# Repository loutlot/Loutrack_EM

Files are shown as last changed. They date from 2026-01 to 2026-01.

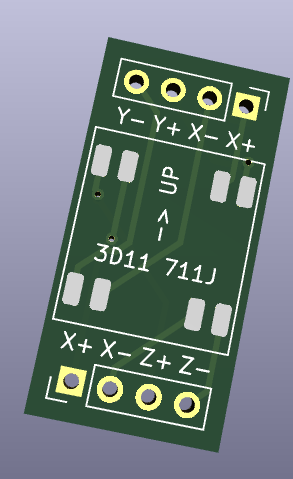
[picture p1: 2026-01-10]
kicad/3D11_test_Board/3D11_test_Board.png

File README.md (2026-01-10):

# Loutrack EM

**磁界ベースのドリフトレスVRトラッカー**

---

## TL;DR

IMUの積分ドリフト問題を解決するため、**磁界（EM）を使った絶対位置・姿勢トラッキング**を開発中。
VRChat等のフルボディトラッキング向け。現在M0（1軸PoC）フェーズ。

---

## 現在の進捗

| フェーズ | 内容 | 状態 |
|---|---|---|
| **M0** | 1軸ディスクリートPoC | 🔄 電源＆受信アンプ組み立て完了、ADC接続中 |
| M1 | 3軸TDM | ⬜ |
| M1.5 | 自作コイル＆ドライバ強化 | ⬜ |
| M2 | SMD基板化（バッテリー駆動対応） | 🔄 バッテリー駆動仕様策定完了 |
| M3 | 推定アルゴリズム | ⬜ |
| M4 | 製品化 | ⬜ |

---

## なぜEMトラッキング？

### 既存技術の問題

| 方式 | 問題点 |
|---|---|
| **IMU** | 積分ドリフトで数分〜数十分で位置がズレる |
| **光学式** | オクルージョン（遮蔽）に弱い、カメラ設置が必要 |
| **Lighthouse** | 高価、HMD依存、セットアップが複雑 |

### EMトラッキングの利点

- ✅ **ドリフトなし**: 磁界強度から直接位置を算出（積分不要）
- ✅ **遮蔽に強い**: 衣服・体を通過する
- ✅ **セットアップ簡単**: 送信アンテナ1つ置くだけ
- ✅ **低コスト化の余地**: IC数個で構成可能

### EMトラッキングの課題

- ⚠️ 金属環境での歪み（キャリブレーションで対応予定）
- ⚠️ 到達距離に限界（送信出力で調整可能）
- ⚠️ 複数トラッカー時の同期

---

## 動作原理

```
┌─────────────┐          磁界           ┌─────────────┐
│   Beacon    │  ～～～～～～～～～～→  │   Tracker   │
│  （送信）   │                         │  （受信）   │
│             │                         │             │
│ 20kHz交流   │                         │ コイルで    │
│ →コイル駆動 │                         │ 誘導電圧検出│
│ →磁界放射   │                         │ →I/Q処理   │
└─────────────┘                         │ →振幅A算出 │
                                        └─────────────┘
```

### 磁界の性質を利用

1. **磁界強度は距離の3乗に反比例** → 距離が分かる
2. **3軸送受信で方向も分かる** → 姿勢も推定可能
3. **位相も取れる** → 将来的に精度向上

### I/Q同期検波

受信信号を送信周波数と同期したsin/cosで積分し、ノイズを除去しながら振幅Aを算出。

```
A = √(I² + Q²)
```

---

## システム構成（M0）

```
┌──────────────────────────────────────────────────────────┐
│                    XIAO ESP32C3                          │
│  PWM生成（20kHz）              SPI ADC読取 → I/Q処理    │
└──────────┬───────────────────────────────┬───────────────┘
           │                               │
           ▼                               ▼
┌──────────────────┐            ┌──────────────────────────┐
│    DRV8835       │            │       MCP6022            │
│   (Hブリッジ)    │            │    (受信アンプ)          │
└────────┬─────────┘            └────────────┬─────────────┘
         │                                   │
         ▼                                   ▼
┌──────────────────┐            ┌──────────────────────────┐
│   3D11-722J      │   磁界     │       3D11-722J          │
│  (送信コイル)    │ ~~~~~~~~→  │     (受信コイル)         │
└──────────────────┘            └────────────┬─────────────┘
                                             │
                                             ▼
                                ┌──────────────────────────┐
                                │        MCP3008           │
                                │         (ADC)            │
                                └──────────────────────────┘
```

## システム構成（M2）

M2では受信機（Tracker）をバッテリー駆動化し、DEEP SLEEP機能で過放電を防止。

```
┌──────────────────────────────────────────────────────────┐
│                XIAO ESP32C3 (Tracker)                    │
│  バッテリー監視 → DEEP SLEEP      SPI ADC読取 → I/Q処理 │
└──────────┬───────────────────────────────┬───────────────┘
           │                               │
           ▼                               ▼
┌──────────────────┐            ┌──────────────────────────┐
│ Li-Po 3.7V       │            │       MCP6022            │
│ (バッテリー)     │            │    (受信アンプ)          │
└────────┬─────────┘            └────────────┬─────────────┘
         │                                   │
         ▼                                   ▼
┌──────────────────┐            ┌──────────────────────────┐
│ 電圧監視回路     │            │       3D11-722J          │
│ (200kΩ分圧)      │            │     (受信コイル)         │
└────────┬─────────┘            └────────────┬─────────────┘
         │                                   │
         ▼                                   ▼
┌──────────────────┐            ┌──────────────────────────┐
│ Wake-upボタン    │   磁界     │        MCP3008           │
│ (D1ピン)         │ ~~~~~~~~→  │         (ADC)            │
└──────────────────┘            └──────────────────────────┘
```

---

## 使用部品

| 部品 | 型番 | 役割 |
|---|---|---|
| MCU | XIAO ESP32C3 | PWM生成、ADC読取、I/Q処理 |
| 3軸コイル | 3D11-722J (7.2mH) | 送受信アンテナ |
| モータドライバ | DRV8835 | コイル駆動（Hブリッジ） |
| オペアンプ | MCP6022 | 受信信号増幅 |
| ADC | MCP3008 | 波形サンプリング |

---

## ロードマップ

### M0: 1軸PoC（現在）
- [x] 部品調達
- [x] GPIO割り当て
- [x] Vmid生成回路組み立て
- [x] 受信アンプ組み立て・動作確認
- [ ] ADC接続・動作確認
- [ ] 送信回路組み立て
- [ ] PWM生成ファームウェア
- [ ] I/Q処理ファームウェア
- [ ] 共振C最適化
- [ ] 距離・角度応答測定

### M1: 3軸TDM
- 3軸送受信でフル姿勢推定
- Time Division Multiplex（X→Y→Z切替）
- 軸間干渉対策

### M1.5: 自作コイル＆ドライバ強化
- 送信距離拡大のための自作コイル製作
- より高出力のドライバ選定・電源強化
- 3m以上のレンジを目指す

### M2: SMD基板化（バッテリー駆動対応）
- [x] バッテリー駆動仕様策定
- [x] 電圧監視回路設計
- [x] DEEP SLEEP/Wake-up実装
- [ ] 回路図設計（KiCad）
- [ ] 基板レイアウト
- [ ] 実装・動作確認

### M3: 推定アルゴリズム
- 磁界モデルに基づく位置・姿勢推定
- キャリブレーション手法

### M4: 製品化
- 無線化（BLE/ESP-NOW）
- 複数トラッカー同期
- VRChat/SteamVR連携

---

## 参考資料

### EMトラッキングの先行事例
- [Polhemus](https://polhemus.com/) - 医療・研究用EMトラッカー
- [NDI Aurora](https://www.ndigital.com/electromagnetic-tracking/) - 手術ナビゲーション

### 技術資料
- [documents/requirements/m0_poc/specification_v0.9.md](documents/requirements/m0_poc/specification_v0.9.md) - M0詳細仕様書
- [documents/requirements/m2_smd/specification.md](documents/requirements/m2_smd/specification.md) - M2バッテリー駆動仕様書
- [documents/schematics/m2_smd/tracker/power_schematic.md](documents/schematics/m2_smd/tracker/power_schematic.md) - M2電源回路図
- [documents/progress/experiment_log.md](documents/progress/m0_poc/experiment_log.md) - M0実験ログ
- [documents/datasheets/](documents/datasheets/) - 部品データシート

---

## フォルダ構成

```
Loutrack_EM/
├── README.md              # このファイル
├── documents/             # ドキュメント
│   ├── requirements/      # 仕様書（フェーズ別）
│   ├── progress/          # 進捗管理
│   ├── bom/               # 部品リスト
│   ├── schematics/        # 回路図
│   ├── assembly/          # 組み立てガイド
│   └── datasheets/        # データシート
├── firmware/              # ファームウェア
│   ├── lib/               # 共通ライブラリ
│   │   ├── battery_monitor.h/cpp    # バッテリー電圧監視
│   │   └── power_manager.h/cpp      # 電源管理（DEEP SLEEP）
│   └── m2_tracker/         # M2受信機ファームウェア
└── kicad/                 # KiCad設計ファイル
```

---

## ライセンス

TBD

---

## 連絡先

TBD

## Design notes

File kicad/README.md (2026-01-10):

# KiCad 設計ファイル

このフォルダには、Loutrack EMプロジェクトで使用するKiCad設計ファイルが保存されています。

## 概要

3D11-722Jコイルをブレッドボード互換のピンヘッダーに変換するためのテストボードをKiCadで設計しています。

## フォルダ構成

```
kicad/
├── README.md                              # このファイル
├── 3D11_test_Board/                       # 単体テストボード
│   ├── 3D11_test_Board.kicad_sch          # 回路図
│   ├── 3D11_test_Board.kicad_pcb          # PCB設計
│   ├── 3D11_test_Board.kicad_pro          # プロジェクト設定
│   ├── 3D11_test_Board.kicad_prl          # プロジェクトレイアウト
│   ├── 3D11_test_Board.png                # 3Dレンダリング
│   ├── garber.zip                         # ガーバーファイル
│   └── fp-info-cache                      # フットプリントキャッシュ
└── 3D11_production/                       # 量産用パネル基板
    ├── 3d11_testboard_batch.kicad_pcb     # PCB設計（パネル）
    ├── 3d11_testboard_batch.kicad_pro     # プロジェクト設定
    ├── 3d11_testboard_batch.png           # 3Dレンダリング
    └── garber.zip                         # ガーバーファイル
```

## テストボードの目的

3D11-722JはSMD部品のため、ブレッドボード（2.54mmピッチ）で直接使用できません。このテストボードは以下の機能を果たします：

- **SMD → DIP変換**: 3D11-722Jを2.54mmピッチのピンヘッダーに接続
- **ブレッドボード互換**: 標準的なブレッドボードに挿入可能
- **信号分離**: 各軸（X, Y, Z）のコイル端子を独立してアクセス可能

## ピン配置

### 基板上面（Y軸 + X軸）

```
        ┌─────────────────────────────────────┐
        │          3D11-722J                  │
        │          Test Board                 │
        │                                     │
        │  Y- [●]  Y+ [●]  X- [●]  X+ [●]    │  ← 上部
        │                                     │
        │          [コイル実装位置]           │
        │                                     │
        │  X+ [●]  X- [●]  Z+ [●]  Z- [●]    │  ← 下部
        │                                     │
        └─────────────────────────────────────┘
```

- **上部**: Y軸, X軸（Y-, Y+, X-, X+）
- **下部**: X軸, Z軸（X+, X-, Z+, Z-）
- **注意**: X軸は上部と下部の両方に存在（接続確認用）

## バージョン説明

### 3D11_test_Board（単体版）

- **用途**: プロトタイプ開発、少量製作
- **基板サイズ**: 単体基板
- **特徴**:
  - 回路図を含む完全なKiCadプロジェクト
  - テスト用の設計検証が可能

### 3D11_production（パネル版）

- **用途**: 量産、10枚同時発注
- **基板サイズ**: 10枚パネル配置
- **特徴**:
  - パネル化によるコスト削減
  - 量産向けに最適化

## 設計仕様

### 電気的特性

| 項目 | 仕様 |
|---|---|
| 入力電圧 | コイルからの誘導電圧（AC） |
| 周波数範囲 | DC〜1MHz（3D11-722JのSRFまで） |
| インピーダンス | コイルインピーダンスに準ずる |
| 絶縁耐圧 | 基板絶縁強度による |

### 機械的特性

| 項目 | 仕様 |
|---|---|
| 基板サイズ | 約30mm × 20mm（単体） |
| 層構成 | 2層基板 |
| ピンヘッダー | 2.54mmピッチ、1×4ヘッダー × 2 |
| コイル固定 | SMDパッド + はんだ固定 |

## 製造手順

### 部品調達

| 部品 | 型番 | 数量 | 備考 |
|---|---|---|---|
| 3D11-722J | - | 1個/基板 | [AliExpress](https://ja.aliexpress.com/item/1005004723068527.html) |
| ピンヘッダー | 1×4, 2.54mm | 2個/基板 | ブレッドボード用 |

### 組み立て手順

1. **基板準備**
   - KiCadでPCBを発注
   - ガーバーファイル（garber.zip）を使用

2. **部品実装**
   - 3D11-722Jを基板中央に配置
   - SMDはんだ付けを実施
   - ピンヘッダーを上下に挿入

3. **動作確認**
   - テスターで各ピン間の導通を確認
   - ショートがないことを確認

## 使用方法

### ブレッドボードへの接続

1. ピンヘッダーをブレッドボードに挿入
2. コイルの各軸端子を回路に接続
3. 電源投入前に接続を確認

### 信号接続例（M0 PoC）

```
DRV8835出力 ──→ 3D11_test_Board X+ ──→ コイルX軸
コイルX軸 ──→ 3D11_test_Board X- ──→ MCP6022入力
```

## 設計ファイルの編集

### KiCadプロジェクトを開く

1. KiCadを起動
2. `File` → `Open Project` → `.kicad_pro`ファイルを選択
3. 回路図（.kicad_sch）またはPCB（.kicad_pcb）を編集

### 回路図の編集

- ピン配置の変更
- 追加回路の設計
- フットプリントの更新

### PCBレイアウトの編集

- 配線パターンの最適化
- サイズ変更
- 層構成の変更

## 注意事項

⚠️ **設計時の注意点:**

1. **絶縁距離**: 高周波信号のため、配線間隔を十分に確保
2. **GND接続**: ノイズ対策のため、GNDプレーンを確保
3. **熱対策**: 発熱部品がある場合は放熱パターンを考慮

⚠️ **使用時の注意点:**

1. **静電気**: ESD対策のため、取り扱いに注意
2. **電源投入**: 接続ミスがないことを確認してから電源投入
3. **周波数範囲**: 3D11-722JのSRFを超えないよう注意

## 関連ドキュメント

- [3D11-722Jデータシート](../../../../documents/datasheets/3d11_coil/)
- [M0組み立てガイド](../../../../documents/assembly/m0_poc/README.md)
- [BOM](../../../../documents/bom/m0_poc/bom.md)

## 変更履歴

| 日付 | 内容 | 変更者 |
|---|---|---|
| 2026-01-11 | 初版作成 | - |

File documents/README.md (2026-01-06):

# Loutrack EM - ドキュメント

## EMトラッキング VRChat用デバイス開発プロジェクト

磁界（EM）ベースのドリフトレストラッキングデバイスのPoC開発ドキュメント

---

## 現在のフェーズ: M0（1軸ディスクリートPoC）

---

## フォルダ構成

```
documents/
├── README.md                      # このファイル
│
├── requirements/                  # 仕様・要件
│   ├── m0_poc/                   # M0: 1軸PoC
│   │   ├── specification_v0.9.md
│   │   └── acceptance_criteria.md
│   ├── m1_3axis/                 # M1: 3軸TDM
│   └── common/                   # 共通仕様
│
├── progress/                      # 進捗管理
│   ├── milestone_tracking.md     # 全体マイルストーン
│   ├── m0_poc/                   # M0実験ログ
│   │   └── experiment_log.md
│   └── m1_3axis/                 # M1実験ログ
│
├── bom/                          # 部品リスト
│   ├── m0_poc/bom.md            # M0用
│   └── m1_3axis/bom.md          # M1用
│
├── schematics/                   # 回路図
│   ├── m0_poc/                  # M0回路図
│   │   ├── beacon/
│   │   ├── tracker/
│   │   └── wiring_table.md
│   └── m1_3axis/                # M1回路図
│
├── assembly/                     # 組み立て説明書
│   ├── m0_poc/                  # M0組み立て
│   │   ├── 01_power_vmid.md
│   │   ├── 02_rx_amplifier.md
│   │   ├── 03_adc.md
│   │   ├── 04_tx_driver.md
│   │   ├── 05_integration.md
│   │   └── troubleshooting.md
│   └── m1_3axis/                # M1組み立て
│
└── datasheets/                   # データシート（共通）
    ├── drv8835/
    ├── 3d11_coil/
    ├── mcp6022/
    ├── mcp3008/
    ├── bat43/
    └── esp32c3/
```

---

## フェーズ一覧

| フェーズ | フォルダ | 内容 | ステータス |
|---|---|---|---|
| **M0** | `m0_poc/` | 1軸ディスクリートPoC | 🔄 進行中 |
| **M1** | `m1_3axis/` | 3軸TDM（ディスクリート） | ⬜ 未着手 |
| **M1.5** | `m1.5_coil_power/` | 自作コイル＆ドライバ強化 | ⬜ 未着手 |
| **M2** | `m2_smd/` | 3軸SMD試作基板 | ⬜ 未着手 |
| **M3** | `m3_algorithm/` | 推定アルゴリズム拡張 | ⬜ 未着手 |
| **M4** | `m4_product/` | 製品化要素 | ⬜ 未着手 |

---

## クイックアクセス（M0）

| ドキュメント | パス |
|---|---|
| 仕様書 | [requirements/m0_poc/specification_v0.9.md](requirements/m0_poc/specification_v0.9.md) |
| 達成基準 | [requirements/m0_poc/acceptance_criteria.md](requirements/m0_poc/acceptance_criteria.md) |
| 部品リスト | [bom/m0_poc/bom.md](bom/m0_poc/bom.md) |
| 配線表 | [schematics/m0_poc/wiring_table.md](schematics/m0_poc/wiring_table.md) |
| 組み立てガイド | [assembly/m0_poc/README.md](assembly/m0_poc/README.md) |
| 実験ログ | [progress/m0_poc/experiment_log.md](progress/m0_poc/experiment_log.md) |
| 全体進捗 | [progress/milestone_tracking.md](progress/milestone_tracking.md) |

---

## 使用機材

| 部品 | 型番 | 入手先 |
|---|---|---|
| MCU | XIAO ESP32C3 | [AliExpress](https://ja.aliexpress.com/item/1005006114576182.html) |
| 3軸コイル | 3D11-722J (L≈7.2mH) | [AliExpress](https://ja.aliexpress.com/item/1005004723068527.html) |
| モータドライバ | DRV8835モジュール | 秋月電子 (109848) |
| オペアンプ | MCP6022-I/P | 秋月電子 (116187) |
| ADC | MCP3008-I/P | 秋月電子 (109485) |

---

## XIAO ESP32C3 GPIO割り当て

| 機能 | ピン | GPIO |
|---|---|---|
| PWM_X | D0 | GPIO2 |
| PWM_X_INV | D1 | GPIO3 |
| SPI_SCK | D8 | GPIO8 |
| SPI_MISO | D9 | GPIO9 |
| SPI_MOSI | D10 | GPIO10 |
| SPI_CS | D7 | GPIO20 |

---

## 更新履歴

| 日付 | 内容 |
|---|---|
| 2026-01-07 | 初版作成 |
| 2026-01-07 | XIAO ESP32C3, 3D11-722J情報追加 |
| 2026-01-07 | フェーズ別フォルダ構成に再編 |

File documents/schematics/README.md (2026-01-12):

# 回路図

## フォルダ構成

```
schematics/
├── README.md          # このファイル
├── m0_poc/           # M0: 1軸ディスクリートPoC
│   ├── beacon/       # 送信回路
│   ├── tracker/      # 受信回路
│   └── wiring_table.md
├── m1_3axis/         # M1: 3軸TDM + LIS3DH
├── m1.5_coil_power/  # M1.5: 自作コイル＆ドライバ強化
└── m2_smd/           # M2: SMD基板化
    └── tracker/
        ├── power_schematic.md   # 電源回路
        └── lis3dh_schematic.md  # LIS3DH回路
```

## 各フェーズの回路図

| フェーズ | 送信回路 | 受信回路 | 配線表 |
|---|---|---|---|
| M0 | [beacon/](m0_poc/beacon/) | [tracker/](m0_poc/tracker/) | [wiring_table.md](m0_poc/wiring_table.md) |
| M1 | TBD | TBD | TBD |
| M2 | TBD | [tracker/](m2_smd/tracker/) | - |

## M2 Tracker回路図

| 回路 | ファイル | 概要 |
|---|---|---|
| 電源回路 | [power_schematic.md](m2_smd/tracker/power_schematic.md) | バッテリー監視、Wake-up回路 |
| LIS3DH回路 | [lis3dh_schematic.md](m2_smd/tracker/lis3dh_schematic.md) | 3軸加速度センサー（Hemispheric ambiguity解決用） |

## 回路図作成ツール（推奨）

- **KiCad** - オープンソース、無料
- **Fritzing** - ブレッドボード図に最適
- **draw.io** - 簡易ブロック図向け

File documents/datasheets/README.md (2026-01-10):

# データシート

## 概要

本プロジェクトで使用する部品のデータシートを保存するフォルダです。

---

## フォルダ構成

```
datasheets/
├── README.md                              # このファイル
├── drv8835/                               # モータドライバ
│   ├── AE-DRV8835-S_akizuki.pdf          ✅ DL済み
│   └── DRV8835_TI.pdf                    ✅ DL済み
├── 3d11_coil/                             # 3軸コイル
│   └── 2016122392158 (1).pdf             ✅ DL済み
├── mcp6022/                               # オペアンプ
│   └── Makin_Signed_henyathegenius-Duet_Night_Abyss_OBT_Campaign.pdf ✅ DL済み
├── mcp3008/                               # ADC
│   └── MCP3008_Microchip.pdf             ✅ DL済み
├── bat43/                                 # ショットキーダイオード
│   └── (要手動DL)
└── esp32c3/                               # MCU
    ├── 20.png                            ✅ DL済み
    └── pin_map-2.png                     ✅ DL済み
```

---

## ダウンロード済み ✅

| フォルダ | ファイル | サイズ | 内容 |
|---|---|---|---|
| drv8835/ | AE-DRV8835-S_akizuki.pdf | 1.0MB | 秋月モジュール説明書 |
| drv8835/ | DRV8835_TI.pdf | 871KB | TI公式データシート |
| 3d11_coil/ | 2016122392158 (1).pdf | 639KB | 3軸コイルシリーズ（3D11） |
| mcp3008/ | MCP3008_Microchip.pdf | 764KB | ADC公式データシート |
| mcp6022/ | Makin_Signed_henyathegenius-Duet_Night_Abyss_OBT_Campaign.pdf | 402KB | オペアンプデータシート |
| esp32c3/ | 20.png | 98KB | ESP32-C3ピン配置図 |
| esp32c3/ | pin_map-2.png | 154KB | ESP32-C3ピンマップ |

---

## 要手動ダウンロード ⚠️

以下のファイルはまだダウンロードできていません。
ブラウザでダウンロードして該当フォルダに保存してください。

### BAT43（ショットキーダイオード）

**保存先:** `bat43/BAT43_ST.pdf`

**ダウンロードリンク:**
- [ST公式](https://www.st.com/en/diodes-and-rectifiers/bat43.html) → "Resources" → "Datasheet"

---

## 主要スペック抜粋

### DRV8835モジュール (秋月 AE-DRV8835-S)

| 項目 | 値 |
|---|-----|
| モータ電源電圧 (VM) | 0〜11V |
| ロジック電源電圧 (VCC) | 2〜7V |
| Hブリッジ出力電流 | 0〜1.5A（並列で3A） |
| 外部入力PWM周波数 | 0〜250kHz |
| オン抵抗 (HS+LS) | 305mΩ |

**ピン配置（反時計回り）:**

| ピン | 名称 | 機能 |
|---|---|---|
| 1 | VM | モータ電源 |
| 2 | AOUT1 | A出力1 |
| 3 | AOUT2 | A出力2 |
| 4 | BOUT1 | B出力1 |
| 5 | BOUT2 | B出力2 |
| 6 | GND | グランド |
| 7 | BIN2 | B入力2/BENBL |
| 8 | BIN1 | B入力1/BPHASE |
| 9 | AIN2 | A入力2/AENBL |
| 10 | AIN1 | A入力1/APHASE |
| 11 | MODE | モード設定 |
| 12 | VCC | ロジック電源 |

**IN/INモード (MODE = GND):**

| xIN1 | xIN2 | xOUT1 | xOUT2 | 動作 |
|---|---|---|---|---|
| 0 | 0 | HiZ | HiZ | 空転 |
| 0 | 1 | L | H | 逆転 |
| 1 | 0 | H | L | 正転 |
| 1 | 1 | L | L | ブレーキ |

### 3D11-722J (SHINHOM)

| 項目 | 値 |
|---|-----|
| サイズ | 11.8 × 11.8 × 2.9 mm |
| インダクタンス (Lx,y,z) | 7.20 mH |
| Q値 | 30 |
| 自己共振周波数 (SRFx,y) | 330 kHz (typ) |
| 自己共振周波数 (SRFz) | 700 kHz (min) |
| DC抵抗 (RDCx,y) | 150Ω max |
| DC抵抗 (RDCz) | 210Ω max |
| 動作温度 | -40°C 〜 +85°C |

### MCP3008 (Microchip)

| 項目 | 値 |
|---|-----|
| 分解能 | 10bit |
| チャンネル数 | 8 |
| サンプルレート | 200ksps @ 5V, 75ksps @ 2.7V |
| 電源電圧 | 2.7〜5.5V |
| インターフェース | SPI |

### ESP32-C3 (Espressif)

| 項目 | 値 |
|---|-----|
| CPU | 32-bit RISC-V RV32IMC |
| クロック | 最大 160MHz |
| SRAM | 400KB |
| Flash | 外部サポート（最大16MB） |
| GPIO | 22個（うちADC1: 6個） |
| Wi-Fi | 802.11 b/g/n |
| Bluetooth | 5.0 (BLE) |
| 消費電流（アクティブ） | 約20mA |
| 消費電流（Deep Sleep） | 約5µA |
| 電源電圧 | 3.0〜3.6V |
| 動作温度 | -40°C 〜 +85°C |

---

## 外部リンク

### メーカーサイト

| 部品 | メーカー | 製品ページ |
|---|---|---|
| DRV8835 | Texas Instruments | [TI](https://www.ti.com/product/DRV8835) |
| AE-DRV8835-S | 秋月電子 | [秋月](https://akizukidenshi.com/catalog/g/g109848/) |
| 3D11-722J | SHINHOM | [SHINHOM](https://www.shinhom.com/) |
| MCP6022 | Microchip | [Microchip](https://www.microchip.com/en-us/product/MCP6022) |
| MCP3008 | Microchip | [Microchip](https://www.microchip.com/en-us/product/MCP3008) |
| BAT43 | STMicroelectronics | [ST](https://www.st.com/en/diodes-and-rectifiers/bat43.html) |
| ESP32-C3 | Espressif | [Espressif](https://www.espressif.com/en/products/socs/esp32-c3) |
| XIAO ESP32C3 | Seeed Studio | [Wiki](https://wiki.seeedstudio.com/XIAO_ESP32C3_Getting_Started/) |

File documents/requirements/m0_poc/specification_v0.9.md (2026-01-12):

# EMトラッキング PoC 仕様書

## ディスクリート→3軸TDM→SMD基板化ロードマップ

**Version:** 0.9  
**作成日:** 2026-01-07  
**対象:** 磁界（EM）ベースのドリフトレス計測 PoC（1軸→3軸TDMへ拡張可能な構造）

---

## 1. 目的とゴール

### 1.1 目的

- EM（磁界）だけで「積分ドリフトなし」の計測が成立するかを検証する
- 送信（Beacon）→受信（Tracker）→I/Q（同期検波） の最小パイプラインをPoCで成立させる
- 将来仕様（3軸TDM＋I/Q＋受信アンプ＋SMD基板）へ、配線・ソフト・データ構造を流用可能な形で実装する

### 1.2 PoCの達成条件（Acceptance Criteria）

PoC（1軸）で以下を満たすこと：

| # | 条件 |
|---|---|
| 1 | 送信ON時、受信信号からI/Qで **安定した振幅A** が算出できる |
| 2 | 送受コイルの距離・角度を変えると、Aが再現性のある単調変化を示す |
| 3 | 送信OFF時は、Aが十分小さく（ノイズフロア）、ON/OFFが明確に判別できる |
| 4 | 1フレーム（例: 16.7ms）内に I/Q 算出が完了し、60Hz相当の更新が可能 |

---

## 2. スコープ

### 2.1 PoC段階のスコープ

- **送信:** 20kHz帯の矩形波をHブリッジでコイル駆動し、L＋共振Cで正弦寄りの磁界を生成
- **受信:** コイル → MCP6022増幅（Vmid基準） → MCP3008 ADC → ESP32S3でI/Q演算
- **段階:**
  1. 1軸送受で成立
  2. 次に **3軸TDM（X→Y→Z時間切替）** へ拡張（同一構造の増殖）

### 2.2 非スコープ（PoCで未実装でもOK）

- VRワールド座標への整列（HMDアンカーによる剛体変換）
- 多トラッカー運用時の無線最適化（帯域、混信、低遅延化）
- 金属環境補正の高度化（環境モデル・キャリブレーション高度化）

---

## 3. 用語と前提

| 用語 | 説明 |
|---|---|
| **Beacon（送信）** | コイルへ交番電流を流し、磁界を作る側 |
| **Tracker（受信）** | コイルで誘導電圧を受け、I/Q処理する側 |
| **Vmid** | 単電源アナログ処理用の仮想GND（3.3V系では1.65V） |
| **I/Q（同期検波）** | 受信波形v(t)をcos/sin参照波で積分し、振幅と位相を得る手法 |
| **TDM** | Time Division Multiplex: X/Y/Z軸送信を時間枠で切り替え識別する方式 |

---

## 4. システム全体アーキテクチャ

### 4.1 ブロック図（論理）

```
┌─────────────────────────────────────────────────────────────────┐
│                    Beacon（送信）                                │
├─────────────────────────────────────────────────────────────────┤
│  ESP32S3                                                        │
│  ├─ 20kHzキャリア生成（PWM/LEDC等）                              │
│  └─ TDMスロット制御（将来3軸）                                   │
│           ↓                                                     │
│  DRV8835（Hブリッジ）                                            │
│  └─ コイルへ±電圧印加（交番電流生成）                            │
│           ↓                                                     │
│  コイル（PoC）＋ 共振C                                           │
│  └─ 高調波を抑えて「正弦寄りの電流波形」にする                   │
└─────────────────────────────────────────────────────────────────┘
           ↓ 磁界
┌─────────────────────────────────────────────────────────────────┐
│                    Tracker（受信）                               │
├─────────────────────────────────────────────────────────────────┤
│  コイル（PoC）                                                   │
│  └─ 20kHz近傍の誘導電圧を発生                                    │
│           ↓                                                     │
│  MCP6022（オペアンプ）                                           │
│  └─ Vmid基準で増幅（単電源で交流を扱う）                         │
│           ↓                                                     │
│  MCP3008（ADC 8ch）                                              │
│  └─ 生波形をサンプルしESP32へSPI転送                             │
│           ↓                                                     │
│  ESP32S3                                                         │
│  └─ I/Q（同期検波）→ A/φ算出                                    │
│     （将来）軸ごとの観測ベクトルから姿勢/位置推定へ拡張          │
└─────────────────────────────────────────────────────────────────┘
```

---

## 5. PoC仕様（ディスクリート実装）

### 5.1 電気仕様（PoCターゲット）

| 項目 | 値 |
|---|-----|
| 送信周波数 | 20kHz（±数%は許容、I/Q参照で追従） |
| 更新レート | 60Hz相当以上（内部はスロット制御でI/Q積分） |
| 受信ADC目標サンプルレート | ≥ 80ksps（20kHzに対して4サンプル/周期以上） |
| アナログ電源 | 3.3V単一（Vmid=1.65V） |
| 送信電源 | USB 5V想定（PoC） |

---

## 6. 回路仕様（PoC：1軸）

### 6.1 Beacon（送信）回路仕様

#### 6.1.1 コイル駆動

- DRV8835の1chで1軸コイルを駆動
- **駆動方式（PoC推奨順）:**
  1. AIN1 = PWM / AIN2 = 反転PWM（±駆動で磁界強度が取りやすい）
  2. AIN1 = PWM / AIN2 = Low固定（簡単だが磁界が弱くなる場合あり）

#### 6.1.2 共振C（"矩形波を丸める"）

- コイル両端にCを並列接続し、L-Cで共振点を20kHz近傍へ寄せる
- PoCでは理論一致より **受信振幅が最大となるCを実測で探索する**
- **手持ちCセットの使い方:**
  - 8200pF
  - 8200+560=8760pF
  - 8200+1500=9700pF
  - 6800pF、6800+1500…
  - の順で試し、受信I/Q振幅が最大になる点を採用

#### 6.1.3 電源デカップリング

- DRV8835近傍に:
  - 0.1µF（5V-GND）
  - 電解100µF（5V-GND）
- 送信系GNDは受信系GNDと一点接続（ノイズ回り込み防止）

### 6.2 Tracker（受信）回路仕様

#### 6.2.1 Vmid生成（仮想GND）

- 10k/10k分圧で1.65V生成（Vmid_raw）
- Vmid_rawを0.1µFで平滑、可能なら電解も追加
- MCP6022の1chを電圧フォロワとしてVmidをバッファ（推奨）
- 以後すべてのアナログ基準はVmid

#### 6.2.2 受信アンプ（1軸・非反転、Vmid基準）

- 受信コイル片端をVmidへ固定し、もう一端を信号入力とする（単端化）
- 入力はVmidにバイアスされるよう構成（ACカップリング or 直結＋抵抗で調整）
- **非反転アンプ:**
  - Gain = 1 + Rf/Rg = 11（Rf=10k, Rg=1k、Rg下端はVmid）
  - 発振時の対策: 47pFをRfに並列（高域ゲインを落とす）
- **目標:** ADCレンジ（0–3.3V）に収まること
  - 飽和する場合はゲインを下げる（または入力を下げる）
  - 弱い場合は2段増幅（将来3軸化時はchが逼迫するのでPoCのみ推奨）

#### 6.2.3 入力保護（BAT43）

- ADC入力を3.3V/GNDへクランプするショットキーを実装（保険）
- 実際には誘導電圧は小さい想定だが、実験時の誤配線対策

#### 6.2.4 ADC（MCP3008）

- VDD=3.3V、VREF=3.3V
- **デカップリング:**
  - VDD-GNDに0.1µF
  - VREF-AGNDに0.1µF
- CH0に受信アンプ出力を入力（PoC）

---

## 7. ファームウェア仕様（PoC：1軸→3軸へ流用）

### 7.1 送信（Beacon側）

- 20kHz PWM生成
- 将来のTDMに備え、スロット制御ステートマシンを最初から実装
- PoCはスロットXのみ有効で動作
- スロット切替は将来X→Y→Zへ拡張

### 7.2 受信（Tracker側）

- MCP3008から波形サンプルを取得
- **I/Q処理:**
  - 参照波cos/sinはNCOまたはテーブル
  - 積分窓長はパラメータ化（0.5ms〜5ms程度で探索）
- **出力:**
  - 振幅 A = sqrt(I²+Q²)
  - 位相 φ = atan2(Q, I)
- PoCではAを主要評価値とする（位相は観測の健全性チェック用途）

### 7.3 TDM（3軸化時）

- フレームを3スロットに分割し、送信軸を切り替える
- 各スロットで独立にI/Q積分し、(Ax, Ay, Az)を得る
- スロット間の過渡（コイルの立上り/共振の安定）を見込んだ "待ち時間（settling）"をパラメータ化（例: 0.2〜1.0ms）

---

## 8. 検証計画（PoCの進め方）

### 8.1 立ち上げ手順（最短）

| Step | 内容 | 確認項目 |
|---|---|---|
| 1 | 受信系単体 | ADCがVmid付近を中心に安定していること |
| 2 | 送信系単体 | DRV8835が過熱しない、電源が落ちない |
| 3 | 送受近接（数cm） | Aが明確に上がること、距離を離すと下がること |
| 4 | 共振C探索 | Cを変え、Aが最大の点を採用 |
| 5 | 距離・角度スイープ | Aの再現性（同じ配置に戻すと同程度のA） |

### 8.2 成功判定に必要なログ

- サンプルレート、積分窓長、A（平均/分散）、送信スロット状態
- 送信PWM設定値、電源電圧（可能なら）

---

## 9. リスクと対策（PoC段階）

| リスク | 対策 |
|---|---|
| ノイズ（送信スイッチングの回り込み） | 送受を物理分離、GND一点接続、ADC/OPAMP近傍デカップリング |
| 信号が弱い | 共振C最適化、コイルの向き・距離見直し、積分窓長増、（PoCのみ）2段増幅 |
| DRV8835の送信出力不足（距離を稼げない） | PoCの目的は"パイプライン成立"なので、まず近距離で成立を優先。将来は送信ドライバ/電源の増強をロードマップに含める |

---

## 10. 3軸TDMへの拡張仕様（次フェーズ）

### 10.1 ハード拡張

- **送信:**
  - DRV8835 2枚で3軸駆動（合計4chのうち3ch使用）
  - コイルは3軸（3Dコイル or 立方体巻線）を用意
- **受信:**
  - MCP6022を「Vmidバッファ1ch＋増幅3ch」で使用
  - MCP3008 CH0-CH2へ各軸アンプ出力を入力
- **⭐ LIS3DH（3軸加速度センサー）**:
  - Hemispheric ambiguity解決用（詳細は10.3参照）
  - I2C接続（D4=SDA, D5=SCL）
  - ブレークアウトボード推奨（秋月/Adafruit）

### 10.2 ソフト拡張

- スロット制御: X→Y→Z
- 各スロットでI/Q積分して (Ax, Ay, Az) を算出
- PoCの次の評価:
  - 軸間干渉（他軸送信時の漏れ）
  - スロット切替時の過渡（settling time）

### 10.3 Hemispheric Ambiguity解決

#### 10.3.1 問題

磁界測定では、+X+Y+Zの位置と-X-Y-Zの位置が同じ測定値を示す「Hemispheric ambiguity」が発生する。

```
     Beacon (送信)
         │
         ▼ 磁界
    ┌─────────┐
    │  +位置  │  ← 測定値 A
    └─────────┘
         │
    ─────┼───── 中心面
         │
    ┌─────────┐
    │  -位置  │  ← 測定値 A（同じ値）
    └─────────┘
```

#### 10.3.2 解決方法（IMU併用）

**Kirbの講義**（`documents/outside_sources/Electromagnetic 6-DOF Tracking for VR Applications/reformatted_kirb_lecture.md`）を参考に、**IMU（加速度センサー）で重力方向を検出**して上下を識別する。

| 方法 | メリット | デメリット | 採用 |
|---|---|---|---|
| 位相検出 | IMU不要 | 位相同期が必要、実装複雑 | ❌ |
| 複数送信コイル | 追加コイルで検証 | コスト・配線増 | ❌ |
| **IMU併用** | シンプル、実証済み | センサー追加 | ⭐ 採用 |

#### 10.3.3 LIS3DHによる実装

- **センサー**: LIS3DH（3軸加速度センサー）
- **必要な機能**: 重力方向検出のみ → 低コストセンサーで十分
- **ジャイロ**: 不要（角速度は不要）
- **データシート**: `documents/requirements/lis3dh/lis3dh.pdf`

**接続（I2C）**:

| LIS3DH | XIAO ESP32C3 | GPIO |
|---|---|---|
| SDA | D4 | GPIO6 |
| SCL | D5 | GPIO7 |
| VDD | 3.3V | - |
| GND | GND | - |

**重力方向検出アルゴリズム**:

```cpp
// Beaconの「下」方向を+Zと仮定
bool isPositiveHemisphere() {
  float gx, gy, gz;
  getGravityDirection(gx, gy, gz);
  // 重力が+Z方向を向いていれば正半球
  return gz > 0;
}
```

#### 10.3.4 初期キャリブレーション手順

1. **Beaconを設置し、向きを固定**（「下」方向を定義）
2. **Trackerを起動**、LIS3DHで重力方向を検出
3. **座標系を整列**: BeaconとTrackerの座標系を合わせる

#### 10.3.5 I/Qロックインとの関係

⚠️ **重要**: I/Qロックイン（I/Q同期検波）は**依然として必要**

| 目的 | I/Qロックイン | IMU (LIS3DH) |
|---|---|---|
| 信号検出・ノイズ除去 | ✅ 必須 | ❌ 不可 |
| 振幅A算出 | ✅ 必須 | ❌ 不可 |
| Hemispheric ambiguity | ❌ 使わない | ✅ これで解決 |

- 位相φも算出するが、**Hemispheric ambiguity解決には使わない**（IMUで解決）
- 位相同期の複雑な実装は不要

---

## 11. SMD基板化（量産に向けた設計方針）

### 11.1 目的

- 配線の寄生成分とノイズ混入を減らし、再現性を上げる
- 3軸＋受信＋ADCの構成を一体化し、調整点を減らす

### 11.2 基板分割（推奨）

- **Beacon基板（送信）とTracker基板（受信）** は分ける
- 送信のスイッチングノイズを受信から隔離
- 受信基板は「アナログ（コイル/AMP）」「デジタル（ADC/MCU/無線）」をレイアウトで分離

### 11.3 回路のSMD化での重要ポイント

- Vmidは必ずバッファ（低インピーダンス）で全体へ配布
- ADCのVREF周りは最優先で静かに（スターGND、短配線、デカップリング密）
- コイル入力は保護・ESD・クランプを入れつつ、過剰な容量を増やさない
- 送信側Hブリッジは熱と電源バルク配置を最優先

### 11.4 将来の部品置換（PoC→製品）

| PoC部品 | 置換候補 |
|---|---|
| MCP3008（SPI ADC） | サンプルレート/分解能/同期性の良いADC |
| DRV8835 | 送信電流を上げられるドライバ（レンジ3m目標時） |
| コイル | 3Dコイル（市販）or 立方体巻線（50mm立方体、線径・巻数最適化） |

---

## 12. ロードマップ（推奨マイルストーン）

| マイルストーン | 内容 |
|---|---|
| **M0** | 1軸ディスクリートPoC成立: Aの安定算出、C最適化、距離/角度応答の確認 |
| **M1** | 3軸TDM（ディスクリート）+ **LIS3DH統合**: (Ax,Ay,Az)がスロットで正しく分離できる、軸干渉・過渡対策のパラメータ確立、**Hemispheric ambiguity解決** |
| **M2** | 3軸SMD試作基板（機能同等）: ディスクリートPoCと同等のA応答を再現、ノイズ・再現性の改善、LIS3DH SMD実装 |
| **M3** | 推定アルゴリズム拡張: 3軸観測ベクトルを用いた姿勢/位置推定の初期実装（環境誤差は未補正で可） |
| **M4** | 製品化要素: 送信出力拡張（レンジ）、無線多端末（同期、帯域）、HMDアンカー整列（ワールド座標） |

---

## 付録

### 付録A: 現在BOM（秋月購入分）

→ `documents/bom/` フォルダ参照

### 付録B: PoCでの「最小配線規約」（再現性のためのルール）

1. 送信系と受信系はブレッドボードで距離を取る
2. GNDは一点接続（受信側で合流）
3. Vmidは必ずバッファして配布
4. ADC VREFは最優先でデカップリング
5. コイル入力配線は最短（可能ならツイスト）

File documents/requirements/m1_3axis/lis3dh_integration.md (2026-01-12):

# M1 LIS3DH統合仕様書

## 概要

LIS3DH（3軸加速度センサー）をTrackerに統合し、Hemispheric ambiguityを解決する。

**参考**: [Kirb EM Tracking講義](../../outside_sources/Electromagnetic%206-DOF%20Tracking%20for%20VR%20Applications/reformatted_kirb_lecture.md)

---

## 1. 目的

### 1.1 Hemispheric Ambiguity問題

磁界測定では、送信コイルからの距離と角度だけで位置を推定するため、原点に対して対称な2つの位置（+X+Y+Zと-X-Y-Z）が同じ測定値を示す。

```
           Beacon
              │
    ┌─────────┴─────────┐
    │                   │
 Tracker A          Tracker A'
 (+X,+Y,+Z)        (-X,-Y,-Z)
    │                   │
    └───── 同じA値 ─────┘
```

### 1.2 解決アプローチ

Kirbの実装を参考に、**IMU（加速度センサー）で重力方向を検出**し、どちらの半球にいるかを判別する。

- **Beaconの「下」方向を固定**（設置時に定義）
- **TrackerのIMUで重力方向を検出**
- **比較して半球を判定**

---

## 2. LIS3DH仕様

### 2.1 基本仕様

| 項目 | 値 |
|---|-----|
| メーカー | STMicroelectronics |
| 型番 | LIS3DH / LIS3DHTR |
| 機能 | 3軸加速度センサー |
| 電源電圧 | 1.71V〜3.6V |
| インターフェース | I2C / SPI |
| I2Cアドレス | 0x18 (SA0=GND) / 0x19 (SA0=VDD) |
| 測定レンジ | ±2g / ±4g / ±8g / ±16g |
| 消費電流 | 2µA (1Hz) 〜 11µA (10Hz) |
| パッケージ | LGA-16 (3x3x1mm) |

**データシート**: [`documents/requirements/lis3dh/lis3dh.pdf`](../lis3dh/lis3dh.pdf)

### 2.2 選定理由

| 項目 | 評価 |
|---|---|
| コスト | ⭐⭐⭐ 低コスト（$1-2） |
| 消費電力 | ⭐⭐⭐ 超低消費電力 |
| 精度 | ⭐⭐ 重力方向検出には十分 |
| 入手性 | ⭐⭐⭐ 秋月、Adafruit、AliExpress |
| ライブラリ | ⭐⭐⭐ Adafruit LIS3DH、Arduino標準 |

**ジャイロは不要**: 重力方向検出だけなので、6軸IMU（BMI160など）より低コストなLIS3DHで十分。

---

## 3. ハードウェア接続

### 3.1 M1（ブレークアウトボード使用）

**推奨ボード**:
- 秋月電子 LIS3DHモジュール
- Adafruit LIS3DH Breakout
- AliExpress GY-LIS3DH

**接続図**:

```
XIAO ESP32C3         LIS3DH Breakout
─────────────        ───────────────
3.3V ────────────── VDD
GND  ────────────── GND
D4 (GPIO6) ──────── SDA
D5 (GPIO7) ──────── SCL
(GND) ───────────── SA0 (アドレス=0x18)
```

**I2Cプルアップ**: ブレークアウトボードに内蔵されていれば不要。無ければ4.7kΩを追加。

### 3.2 M2（SMD直付け）

→ [`documents/schematics/m2_smd/tracker/lis3dh_schematic.md`](../../schematics/m2_smd/tracker/lis3dh_schematic.md)を参照

### 3.3 XIAO ESP32C3 GPIO割り当て（M1/M2共通）

| 機能 | ピン | GPIO | プロトコル |
|---|---|---|---|
| I2C_SDA | D4 | GPIO6 | I2C |
| I2C_SCL | D5 | GPIO7 | I2C |

**ピン競合チェック**:
- SPI（MCP3008）: D7, D8, D9, D10 → OK（別ピン）
- バッテリー監視: D0 → OK（別ピン）
- 空きピン: D1, D2, D3, D6 → OK

---

## 4. ファームウェア実装

### 4.1 依存ライブラリ

```cpp
#include <Wire.h>
#include <Adafruit_LIS3DH.h>
#include <Adafruit_Sensor.h>
```

**インストール** (Arduino IDE):
- `Adafruit LIS3DH` ライブラリ
- `Adafruit Unified Sensor` ライブラリ

### 4.2 初期化コード

```cpp
// LIS3DH設定
#define I2C_SDA 6  // GPIO6 (D4)
#define I2C_SCL 7  // GPIO7 (D5)
#define LIS3DH_ADDR 0x18  // SA0=GND

Adafruit_LIS3DH lis = Adafruit_LIS3DH();

void setupLIS3DH() {
  // I2C初期化（ESP32C3のカスタムピン）
  Wire.begin(I2C_SDA, I2C_SCL);
  
  // LIS3DH初期化
  if (!lis.begin(LIS3DH_ADDR)) {
    Serial.println("ERROR: LIS3DH not found!");
    while (1) yield();
  }
  
  // レンジ設定（±2g: 重力検出に十分）
  lis.setRange(LIS3DH_RANGE_2_G);
  
  // データレート（10Hz: 低消費電力、レスポンス十分）
  lis.setDataRate(LIS3DH_DATARATE_10_HZ);
  
  Serial.println("LIS3DH initialized!");
}
```

### 4.3 重力方向取得

```cpp
// 重力ベクトルを取得（正規化済み）
void getGravityDirection(float &gx, float &gy, float &gz) {
  lis.read();
  
  // 生値（±2gレンジ、1g ≈ 1.0）
  gx = lis.x_g;
  gy = lis.y_g;
  gz = lis.z_g;
  
  // 正規化（オプション）
  float mag = sqrt(gx*gx + gy*gy + gz*gz);
  if (mag > 0.1) {  // ゼロ除算防止
    gx /= mag;
    gy /= mag;
    gz /= mag;
  }
}
```

### 4.4 Hemispheric Ambiguity解決

```cpp
// ===== 設定 =====
// Beaconの「下」方向を定義（設置時に固定）
// 例: Beaconを水平に置いた場合、重力は+Z方向
const float BEACON_DOWN_X = 0.0;
const float BEACON_DOWN_Y = 0.0;
const float BEACON_DOWN_Z = 1.0;  // +Z = 下

// ===== Hemispheric判定 =====
// true: 正半球（Beaconと同じ側）
// false: 負半球（Beaconと反対側）
bool isPositiveHemisphere() {
  float gx, gy, gz;
  getGravityDirection(gx, gy, gz);
  
  // TrackerとBeaconの重力方向の内積
  // 内積 > 0 なら同じ向き（正半球）
  float dot = gx * BEACON_DOWN_X + gy * BEACON_DOWN_Y + gz * BEACON_DOWN_Z;
  
  return dot > 0;
}

// ===== 磁界測定値の符号補正 =====
void applyHemisphereCorrection(float &Ax, float &Ay, float &Az) {
  if (!isPositiveHemisphere()) {
    // 負半球の場合、符号を反転
    Ax = -Ax;
    Ay = -Ay;
    Az = -Az;
  }
}
```

### 4.5 メインループ統合

```cpp
void loop() {
  // ===== 1. 磁界測定（I/Q同期検波） =====
  float Ix, Qx, Ax, phix;
  computeIQ(Ix, Qx, Ax, phix);  // X軸
  
  // 同様にY軸、Z軸（TDM使用時）
  
  // ===== 2. Hemispheric Ambiguity解決 =====
  float Ay = 0, Az = 0;  // TDM使用時は実測値
  applyHemisphereCorrection(Ax, Ay, Az);
  
  // ===== 3. 結果出力 =====
  Serial.printf("A = (%.3f, %.3f, %.3f)\n", Ax, Ay, Az);
}
```

---

## 5. キャリブレーション手順

### 5.1 Beacon設置キャリブレーション

1. **Beaconを設置**（通常は動かさない）
2. **「下」方向を定義**:
   - Beaconを水平に置く → `BEACON_DOWN_Z = 1.0`
   - Beaconを壁に立てかける → `BEACON_DOWN_X = 1.0` など
3. **ファームウェアに定数を設定**

### 5.2 Trackerキャリブレーション（将来拡張）

必要に応じて以下を実装:
- オフセットキャリブレーション（静止状態で1gになるよう補正）
- 軸整列キャリブレーション（LIS3DHとTrackerコイルの軸を合わせる）

---

## 6. 検証項目

### 6.1 M1タスク一覧

| # | タスク | 確認項目 |
|---|---|---|
| 1.7 | LIS3DH購入・接続 | I2C通信成功、加速度値読み取り |
| 1.8 | FW実装（重力方向検出） | 静止状態で約1g、傾けると軸ごとに変化 |
| 1.9 | Hemispheric ambiguity検証 | Beaconの上下で磁界符号が正しく補正される |

### 6.2 テストシナリオ

1. **静止テスト**: 
   - Trackerを水平に置く → gz ≈ 1.0
   - Trackerを垂直に立てる → gx or gy ≈ 1.0

2. **半球判定テスト**:
   - TrackerをBeaconの「上」に配置 → 正半球
   - TrackerをBeaconの「下」に配置 → 負半球
   - 符号補正後のAxが一貫していることを確認

---

## 7. 参考資料

- [LIS3DHデータシート](../lis3dh/lis3dh.pdf)
- [Adafruit LIS3DHライブラリ](https://github.com/adafruit/Adafruit_LIS3DH)
- [Kirb EM Tracking講義](../../outside_sources/Electromagnetic%206-DOF%20Tracking%20for%20VR%20Applications/reformatted_kirb_lecture.md)
- [M1 BOM](../../bom/m1_3axis/bom.md)
- [M2 LIS3DH回路図](../../schematics/m2_smd/tracker/lis3dh_schematic.md)

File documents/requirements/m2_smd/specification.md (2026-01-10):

# M2: 3軸SMD試作基板 仕様書

**Version:** 1.0  
**作成日:** 2026-01-11  
**対象:** 3軸TDM + バッテリー駆動対応の受信機SMD基板

---

## 1. 概要

M2フェーズでは、M1で確立した3軸TDMシステムをSMD基板化し、受信機にバッテリー駆動機能を追加します。

### 1.1 目標

- ディスクリートPoCと同等のA応答を再現
- ノイズ・再現性の改善
- 受信機のバッテリー駆動対応

### 1.2 構成

| ユニット | 電源 | MCU | 備考 |
|---|---|-----|---|
| 送信機（Beacon） | USB 5V | XIAO ESP32C3 | 固定設置 |
| 受信機（Tracker） | Li-Po 3.7V | XIAO ESP32C3 | バッテリー駆動 |

---

## 2. 受信機 GPIO割り当て

### 2.1 ピンマップ

| ピン | GPIO | 機能 | 備考 |
|---|---|---|---|
| D0 | GPIO2 | **バッテリー電圧監視 (A0)** | 200kΩ分圧で接続 |
| D1 | GPIO3 | **Wake-upボタン** | LOW→Wake-up、内部プルアップ使用 |
| D2 | GPIO4 | 予備 | |
| D3 | GPIO5 | 予備 | |
| D4 | GPIO6 | 予備 | |
| D5 | GPIO7 | 予備 | |
| D6 | GPIO21 | 予備 | |
| D7 | GPIO20 | SPI_CS (MCP3008) | |
| D8 | GPIO8 | SPI_SCK | |
| D9 | GPIO9 | SPI_MISO | |
| D10 | GPIO10 | SPI_MOSI | |

**使用: 6ピン / 予備: 5ピン**

### 2.2 制約事項

- **Wake-up対応ピン:** ESP32C3ではD0〜D3 (GPIO2, 3, 4, 5) のみ対応
- **ADC1対応ピン:** D0〜D2 (GPIO2, 4, 3) はADC1を使用、WiFi動作時も利用可能
- **ADC2対応ピン:** D3 (GPIO5) はADC2を使用、WiFi動作時は利用不可

---

## 3. 送信機 GPIO割り当て

### 3.1 ピンマップ

| ピン | GPIO | 機能 | 備考 |
|---|---|---|---|
| D0 | GPIO2 | PWM_X | X軸送信PWM |
| D1 | GPIO3 | PWM_X_INV | X軸反転PWM（またはGND固定） |
| D2 | GPIO4 | PWM_Y | Y軸送信PWM |
| D3 | GPIO5 | PWM_Y_INV | Y軸反転PWM（またはGND固定） |
| D4 | GPIO6 | PWM_Z | Z軸送信PWM |
| D5 | GPIO7 | PWM_Z_INV | Z軸反転PWM（またはGND固定） |
| D6 | GPIO21 | 予備 | |
| D7 | GPIO20 | 予備 | |
| D8 | GPIO8 | 予備 | |
| D9 | GPIO9 | 予備 | |
| D10 | GPIO10 | 予備 | |

**使用: 6ピン / 予備: 5ピン**

---

## 4. バッテリー駆動仕様（受信機のみ）

### 4.1 電源仕様

| 項目 | 仕様 |
|---|---|
| バッテリー種別 | Li-Po 3.7V (1セル) |
| 充電方式 | USB-C経由、XIAO内蔵充電回路使用 |
| 過充電防止 | XIAO内蔵回路で対応 |
| 過放電防止 | ソフトウェア監視 + DEEP SLEEP |

### 4.2 電圧監視

| 項目 | 値 |
|---|-----|
| 監視ピン | D0 (GPIO2 / A0) |
| 分圧抵抗 | 200kΩ × 2（1/2分圧） |
| フル充電電圧 | 4.2V（ADC読み値: 2.1V） |
| 低電圧警告 | 3.3V（ADC読み値: 1.65V） |
| 過放電閾値 | 3.1V（ADC読み値: 1.55V） |

### 4.3 電源スイッチ

| スイッチ | 種類 | 機能 |
|---|---|---|
| メインスイッチ | トグル | バッテリーとXIAO間を物理的に切断 |
| Wake-upボタン | モーメンタリ | DEEP SLEEPからの復帰 |

### 4.4 DEEP SLEEP仕様

| 項目 | 仕様 |
|---|---|
| Wake-upピン | D1 (GPIO3) |
| Wake-up条件 | LOW（ボタン押下時） |
| 内部プルアップ | 有効 |
| DEEP SLEEP消費電流 | 約5µA（XIAO ESP32C3仕様） |

---

## 5. 回路仕様

### 5.1 電圧監視回路

```
BAT+ ──[200kΩ]──┬──[200kΩ]── GND
                │
                └── D0 (A0/GPIO2)
```

### 5.2 Wake-upボタン回路

```
D1 (GPIO3) ──┬── [内部プルアップ]
             │
             └── [モーメンタリSW] ── GND
```

---

## 6. ファームウェア仕様

### 6.1 バッテリー電圧監視

- 監視間隔: 1秒ごと
- 平均化: 16回サンプリングの平均
- `analogReadMilliVolts()` を使用（チップ個体差補正済み）

### 6.2 過放電防止フロー

```
起動
  ↓
電圧監視（1秒間隔）
  ↓
┌─ V < 3.1V → 即座にDEEP SLEEP
├─ V < 3.3V → 警告状態（一定時間後にDEEP SLEEP）
└─ V ≥ 3.3V → 通常動作
```

### 6.3 Wake-up処理

1. ボタン押下でDEEP SLEEPから復帰
2. 起動時に電圧チェック
3. 電圧が十分（≥3.3V）なら通常動作開始
4. 電圧が不足なら再度DEEP SLEEP

---

## 7. 必要部品（バッテリー関連追加分）

| 部品 | 仕様 | 数量 | 用途 |
|---|---|---|---|
| 抵抗 200kΩ | 1/4W, 1% | 2 | 電圧分圧 |
| トグルスイッチ | SPST | 1 | メイン電源ON/OFF |
| タクトスイッチ | モーメンタリ | 1 | Wake-up用 |
| Li-Poバッテリー | 3.7V, 500mAh以上 | 1 | 電源 |
| JST-PHコネクタ | 2ピン | 1 | バッテリー接続 |

---

## 8. 注意事項

1. **XIAO内蔵充電回路を使用**: 外部充電IC（TP4056等）は不要
2. **トグルスイッチの配置**: バッテリーのプラス側に挿入
3. **Wake-up対応ピン制限**: ESP32C3ではD0〜D3のみ対応
4. **ADC精度**: チップ個体差があるため、キャリブレーション推奨
5. **通信時のノイズ**: WiFi通信時はADC読み取りにスパイクが発生するため、16回平均化を実施

---

## 変更履歴

| 日付 | 内容 | 変更者 |
|---|---|---|
| 2026-01-11 | 初版作成（バッテリー駆動仕様追加） | - |

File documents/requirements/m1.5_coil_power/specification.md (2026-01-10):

# M1.5: 自作コイル＆ドライバ強化 仕様書

**Version:** 0.1  
**作成日:** 2026-01-07

---

## 1. 目的

M0/M1で使用した3D11-722JとDRV8835の組み合わせでは、送信距離が限られる。
VRChatフルボディトラッキングの実用化に向け、**3m以上の送受信距離**を実現するため、
送信系（コイル・ドライバ・電源）を強化する。

---

## 2. 達成目標

| 項目 | M1まで | M1.5目標 |
|---|---|---|
| 有効距離 | 〜30cm | 3m以上 |
| 送信電流 | 〜100mA | 0.5〜2A |
| 送信コイル | 3D11-722J (7.2mH) | 自作コイル（最適化） |
| ドライバ | DRV8835 (1.5A) | 高出力ドライバ |
| 電源 | USB 5V | 専用電源 or 昇圧 |

---

## 3. 送信コイル設計

### 3.1 磁界強度の基本

磁気ダイポールの磁界強度（軸上）:

```
B ∝ μ₀ × n × I × A / r³
```

- n: 巻数
- I: 電流
- A: コイル面積
- r: 距離

→ **大きいコイル × 多い巻数 × 大電流** で磁界強度UP

### 3.2 設計パラメータ候補

| パラメータ | 候補1（小型） | 候補2（中型） | 候補3（大型） |
|---|---|---|---|
| 形状 | 立方体 | 立方体 | 立方体 |
| 一辺 | 50mm | 80mm | 100mm |
| 巻数/軸 | 30T | 50T | 50T |
| 線径 | 0.3mm | 0.5mm | 0.8mm |
| 概算L | 〜5mH | 〜15mH | 〜20mH |

### 3.3 コイル製作方法

1. **立方体フレーム製作**
   - 3Dプリント or アクリル板組み立て
   - 各軸用の巻き溝を設ける

2. **巻線**
   - エナメル線を使用
   - 層巻き or 乱巻き
   - 各軸が直交するように配置

3. **インダクタンス測定**
   - LCRメーターで測定
   - 共振Cを計算

---

## 4. ドライバ選定

### 4.1 要件

| 項目 | 要件 |
|---|---|
| 出力電流 | 1A以上（ピーク2A以上） |
| PWM周波数 | 20kHz以上対応 |
| 電源電圧 | 12V〜24V対応 |
| チャンネル数 | 3軸 = 3ch（または2ch×2） |

### 4.2 候補ドライバ

| 型番 | メーカー | 電流 | 電圧 | 備考 |
|---|---|---|---|---|
| DRV8833 | TI | 1.5A | 2.7〜10.8V | DRV8835の上位 |
| TB6612FNG | 東芝 | 1.2A (3A peak) | 2.5〜13.5V | 定番 |
| L298N | ST | 2A | 5〜35V | 大型、放熱板付き |
| BTS7960 | Infineon | 43A | 5.5〜27V | 高出力、過剰かも |
| ディスクリートMOSFET | - | 任意 | 任意 | フルカスタム可 |

### 4.3 初期選定

**TB6612FNG** または **L298N** から開始を推奨。

---

## 5. 電源強化

### 5.1 要件

| 項目 | 計算 |
|---|---|
| 電流 | 1A × 3軸 = 3A（同時駆動時） |
| 電圧 | 12V（コイル抵抗・インダクタンスに依存） |
| 電力 | 12V × 3A = 36W |

### 5.2 電源オプション

| 方式 | 利点 | 欠点 |
|---|---|---|
| ACアダプタ 12V 5A | 安定、安価 | コード必要 |
| Li-Po 3S (11.1V) | ポータブル | 充電管理必要 |
| USB PD + 昇圧 | USB-C対応 | 変換ロス |

---

## 6. 熱設計

### 6.1 発熱源

- ドライバIC（オン抵抗による損失）
- コイル（銅損）
- 昇圧回路（変換損失）

### 6.2 対策

- ヒートシンク追加
- 基板の銅箔面積拡大
- TDMのデューティ比調整（常時送信を避ける）

---

## 7. 検証項目

| # | 項目 | 方法 |
|---|---|---|
| 1 | コイルL値 | LCRメーター |
| 2 | 共振C最適化 | 受信振幅Aで評価 |
| 3 | 距離レンジ | 1m/2m/3mでA測定 |
| 4 | 消費電力 | 電流計で測定 |
| 5 | 温度上昇 | 30分連続運転後の温度 |

---

## 8. リスクと対策

| リスク | 対策 |
|---|---|
| コイルが大きすぎてVRに不向き | Beacon側は固定なので許容、Trackerは小型維持 |
| 発熱で連続運転できない | TDMデューティ調整、放熱強化 |
| 電磁ノイズが増える | シールド、フィルタ追加 |
| コストが上がる | M2で量産最適化 |

---

## 9. 参考資料

- [コイル設計の基礎](https://www.coilcraft.com/)
- [TB6612FNGデータシート](https://toshiba.semicon-storage.com/jp/semiconductor/product/motor-driver-ics/brushed-dc-motor-driver-ics/detail.TB6612FNG.html)
- [L298Nデータシート](https://www.st.com/resource/en/datasheet/l298.pdf)

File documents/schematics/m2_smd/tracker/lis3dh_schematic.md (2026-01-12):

# M2 LIS3DH SMD回路図

## 概要

LIS3DH（3軸加速度センサー）のSMD実装回路図。Hemispheric ambiguity解決用。

**データシート**: [`documents/requirements/lis3dh/lis3dh.pdf`](../../../requirements/lis3dh/lis3dh.pdf)

---

## LIS3DH仕様

| 項目 | 値 |
|---|-----|
| メーカー | STMicroelectronics |
| 型番 | LIS3DHTR |
| パッケージ | LGA-16 (3x3x1mm) |
| 電源電圧 | 1.71V〜3.6V |
| IO電源 | 1.8V（独立供給可能、VDD共用可） |
| インターフェース | I2C / SPI |
| I2Cアドレス | 0x18（SA0=GND）/ 0x19（SA0=VDD） |
| 消費電力 | 2µA @ 1Hz（Ultra-low-power mode） |

---

## ピンアウト（LGA-16）

```
        ┌─────────────────────┐
        │     LIS3DH (TOP)    │
        │      LGA-16         │
        │                     │
    1 ──┤ VDD_IO        GND  ├── 5
    2 ──┤ NC           INT1  ├── 6
    3 ──┤ NC           INT2  ├── 7
    4 ──┤ SDO/SA0      GND   ├── 8
        │                     │
   16 ──┤ VDD          SCL   ├── 9
   15 ──┤ NC           SDA   ├── 10
   14 ──┤ NC           ADC3  ├── 11
   13 ──┤ CS           ADC2  ├── 12
        │                     │
        └─────────────────────┘
```

**ピン説明**:

| ピン | 名称 | 機能 | 接続先 |
|---|---|---|---|
| 1 | VDD_IO | IO電源 (1.8V〜VDD) | 3.3V（VDD共用可） |
| 4 | SDO/SA0 | I2Cアドレス選択 / SPI MISO | GND（アドレス=0x18） |
| 5, 8 | GND | グランド | GND |
| 6 | INT1 | 割り込み出力1 | NC（将来拡張用） |
| 7 | INT2 | 割り込み出力2 | NC（将来拡張用） |
| 9 | SCL | I2Cクロック / SPI CLK | GPIO7 (D5) + 4.7kΩプルアップ |
| 10 | SDA | I2Cデータ / SPI MOSI | GPIO6 (D4) + 4.7kΩプルアップ |
| 11 | ADC3 | 外部ADC入力3 | NC |
| 12 | ADC2 | 外部ADC入力2 | NC |
| 13 | CS | SPI CS（I2Cモード時はVDD） | 3.3V（I2Cモード） |
| 16 | VDD | 電源 | 3.3V |
| 2, 3, 14, 15 | NC | 未接続 | NC |

---

## 回路図

### I2C接続（推奨）

```
                         3.3V
                          │
                    ┌─────┴─────┐
                    │           │
                   4.7kΩ      4.7kΩ
                    │           │
                    │           │
    GPIO6 (D4) ─────┼───────────┼──────────┐
    (SDA)           │           │          │
                    │           │          │
    GPIO7 (D5) ─────┼───────────┘          │
    (SCL)           │                      │
                    │                      │
                    │     ┌────────────────┼────────────────┐
                    │     │                │                │
                    │     │   LIS3DH       │                │
                    │     │   (LGA-16)     │                │
                    │     │                │                │
              3.3V ─┼─────┼── VDD (16)     │                │
                    │     │                │                │
              3.3V ─┼─────┼── VDD_IO (1)   │                │
                    │     │                │                │
              3.3V ─┼─────┼── CS (13)      │ (I2Cモード)    │
                    │     │                │                │
               GND ─┼─────┼── GND (5, 8)   │                │
                    │     │                │                │
               GND ─┼─────┼── SA0 (4)      │ (アドレス=0x18)│
                    │     │                │                │
                    └─────┼── SCL (9) ─────┘                │
                          │                                 │
                          └── SDA (10) ────────────────────┘
                          │
                          ├── INT1 (6) ──── NC (将来拡張用)
                          │
                          └── INT2 (7) ──── NC (将来拡張用)

    電源デカップリング:

              3.3V
               │
           ┌───┴───┐
           │       │
         100nF   10µF
           │       │
           └───┬───┘
               │
              GND
```

---

## 部品リスト

| 参照番号 | 部品 | 値 | パッケージ | 数量 | 備考 |
|---|---|-----|---|---|---|
| U1 | LIS3DHTR | - | LGA-16 | 1 | 3軸加速度センサー |
| C1 | デカップリング | 100nF | 0402/0603 | 1 | VDD-GND |
| C2 | バルク | 10µF | 0603/0805 | 1 | VDD-GND |
| R1 | プルアップ | 4.7kΩ | 0402/0603 | 1 | SDA-3.3V |
| R2 | プルアップ | 4.7kΩ | 0402/0603 | 1 | SCL-3.3V |

---

## PCBレイアウトガイドライン

### フットプリント

データシート（lis3dh.pdf）のFigure 12参照。

| 項目 | 値 |
|---|-----|
| パッケージサイズ | 3.0 × 3.0 × 1.0 mm |
| パッドピッチ | 0.5mm |
| パッドサイズ | データシート推奨値に従う |

### 配置推奨

```
┌─────────────────────────────────────────────┐
│                                             │
│   ┌───────┐                                 │
│   │ C1    │  ← VDD近傍（デカップリング）     │
│   │100nF  │                                 │
│   └───────┘                                 │
│                                             │
│   ┌───────────────┐                         │
│   │               │                         │
│   │    LIS3DH     │  ← センサー配置          │
│   │               │                         │
│   └───────────────┘                         │
│                                             │
│   ┌───────┐                                 │
│   │ C2    │  ← バルクコンデンサ             │
│   │ 10µF  │                                 │
│   └───────┘                                 │
│                                             │
│   ┌───┐ ┌───┐                               │
│   │R1 │ │R2 │  ← I2Cプルアップ              │
│   │4.7k│ │4.7k│                             │
│   └───┘ └───┘                               │
│                                             │
└─────────────────────────────────────────────┘
```

### 配線ガイドライン

1. **デカップリング**: C1 (100nF) はVDDピンの直近に配置
2. **I2Cライン**: できるだけ短く配線、GNDプレーンから離す
3. **GNDプレーン**: センサー周辺にベタGNDを配置
4. **ノイズ対策**: デジタル回路（MCU）とは離して配置

---

## ファームウェア設定

### I2C初期化

```cpp
#include <Wire.h>
#include <Adafruit_LIS3DH.h>

// XIAO ESP32C3のI2Cピン
#define I2C_SDA 6  // GPIO6 (D4)
#define I2C_SCL 7  // GPIO7 (D5)

// I2Cアドレス（SA0=GND）
#define LIS3DH_ADDR 0x18

Adafruit_LIS3DH lis = Adafruit_LIS3DH();

void setupLIS3DH() {
  // I2C初期化
  Wire.begin(I2C_SDA, I2C_SCL);
  
  // LIS3DH初期化
  if (!lis.begin(LIS3DH_ADDR)) {
    Serial.println("LIS3DH not found!");
    while (1);
  }
  
  // レンジ設定（±2g、重力検出に十分）
  lis.setRange(LIS3DH_RANGE_2_G);
  
  // データレート設定（低消費電力モード）
  lis.setDataRate(LIS3DH_DATARATE_10_HZ);
  
  Serial.println("LIS3DH initialized!");
}
```

### 重力方向検出（Hemispheric Ambiguity解決）

```cpp
// 重力方向を取得
void getGravityDirection(float &gx, float &gy, float &gz) {
  lis.read();
  gx = lis.x_g;
  gy = lis.y_g;
  gz = lis.z_g;
}

// Hemispheric ambiguity解決
// Beaconの「下」方向を+Zと仮定
bool isPositiveHemisphere() {
  float gx, gy, gz;
  getGravityDirection(gx, gy, gz);
  
  // 重力方向がBeaconの「下」と同じ向きなら正半球
  return gz > 0;
}
```

---

## 参考資料

- [LIS3DHデータシート](../../../requirements/lis3dh/lis3dh.pdf)
- [Kirb EMトラッキング講義](../../../outside_sources/Electromagnetic%206-DOF%20Tracking%20for%20VR%20Applications/reformatted_kirb_lecture.md)（Hemispheric ambiguity解決の参考）
- [Adafruit LIS3DHライブラリ](https://github.com/adafruit/Adafruit_LIS3DH)

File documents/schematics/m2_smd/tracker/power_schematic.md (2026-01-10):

# M2 Tracker（受信機）電源回路図

## 概要

このドキュメントでは、M2受信機のバッテリー駆動に必要な電源回路を説明します。

---

## 電源系統ブロック図

```
                          ┌─────────────────────────────────────────────────┐
                          │               XIAO ESP32C3                      │
                          │                                                 │
USB-C ════════════════════╪══→ USB ──→ [内蔵充電IC] ──→ BAT+端子           │
                          │                  │            ↓                 │
                          │                  │      ┌─────────┐            │
                          │                  └──────┤ Li-Po   │            │
                          │                         │ 3.7V    │            │
                          │                         └────┬────┘            │
                          │                              │                  │
                          │      ┌───────────────────────┤                  │
                          │      │                       │                  │
                          │      ▼                       ▼                  │
                          │ [トグルSW] ─────────────→ BAT+ ──→ LDO ──→ 3.3V│
                          │                              │                  │
                          │                         [電圧監視]              │
                          │                              │                  │
                          │                              ▼                  │
                          │                         D0 (A0)                 │
                          └─────────────────────────────────────────────────┘
```

---

## 電圧監視回路（詳細）

### 回路図

```
Li-Po BAT+ (3.7V〜4.2V)
     │
     │    ┌────────────────────────────────────────────┐
     │    │                                            │
     ├────┼──[トグルスイッチ]──→ XIAO BAT+端子         │
     │    │                                            │
     │    │   電圧監視回路                             │
     │    │   ┌─────────┐                              │
     └────┼───┤         │                              │
          │   │  200kΩ  │ R1                           │
          │   │         │                              │
          │   └────┬────┘                              │
          │        │                                   │
          │        ├───────────→ D0 (GPIO2/A0)         │
          │        │              XIAO ESP32C3         │
          │   ┌────┴────┐                              │
          │   │         │                              │
          │   │  200kΩ  │ R2                           │
          │   │         │                              │
          │   └────┬────┘                              │
          │        │                                   │
          └────────┴───────────→ GND                   │
                                                       │
                   └───────────────────────────────────┘
```

### 計算

| 項目 | 計算式 | 値 |
|---|---|-----|
| 分圧比 | R2 / (R1 + R2) | 0.5 (1/2) |
| 消費電流 | V_bat / (R1 + R2) | 4.2V / 400kΩ = 10.5µA (最大) |
| フル充電時 ADC入力 | 4.2V × 0.5 | 2.1V |
| 空時 ADC入力 | 3.0V × 0.5 | 1.5V |

### ADC読み取り値と電圧の対応

| バッテリー電圧 | ADC入力電圧 | 状態 |
|---|---|---|
| 4.2V | 2.1V | フル充電 |
| 3.7V | 1.85V | 50%程度 |
| 3.3V | 1.65V | 低電圧警告 |
| 3.1V | 1.55V | 過放電閾値 |
| 3.0V | 1.5V | 危険（即シャットダウン） |

---

## Wake-upボタン回路（詳細）

### 回路図

```
        XIAO ESP32C3
             │
             │   D1 (GPIO3)
             │      │
             │      ├───[内部プルアップ 45kΩ]──── 3.3V
             │      │
             │      │
             │      └───[タクトスイッチ]──── GND
             │
             └─────────────────────────────────────
```

### 動作

| ボタン状態 | D1電圧 | ESP32C3状態 |
|---|---|---|
| 開放（通常） | HIGH (3.3V) | 通常動作 / DEEP SLEEP維持 |
| 押下 | LOW (0V) | Wake-up（DEEP SLEEPから復帰） |

### 設定

```cpp
// 内部プルアップを有効化
pinMode(D1, INPUT_PULLUP);

// Wake-up設定（LOWで起動）
esp_deep_sleep_enable_gpio_wakeup(BIT(D1), ESP_GPIO_WAKEUP_GPIO_LOW);
```

---

## 電源スイッチ接続

### トグルスイッチの配置

```
Li-Po バッテリー
     │
     ├──[+]── トグルスイッチ ───→ XIAO BAT+パッド
     │                              │
     │                         [はんだ付け]
     │                              │
     │                         XIAO ESP32C3
     │                              │
     └──[−]─────────────────────→ GND
```

### XIAO ESP32C3 バッテリー接続パッド

```
        ┌─────────────────────────────────┐
        │         XIAO ESP32C3            │
        │                                 │
USB-C ══╪══                               │
        │                                 │
        │    ┌─────┐    ┌─────┐          │
        │    │ BAT+│    │ BAT-│          │
        │    │ パッド│    │ パッド│          │
        │    └──┬──┘    └──┬──┘          │
        │       │           │             │
        └───────┼───────────┼─────────────┘
                │           │
                ▼           ▼
          [トグルSW]       GND
                │
                ▼
          Li-Po BAT+
```

⚠️ **注意:** XIAOの裏面にあるBAT+/BAT-パッドにはんだ付けが必要です。

---

## 配線表

### 電圧監視回路

| 接続元 | 接続先 | 部品 |
|---|---|---|
| Li-Po BAT+ | R1 (200kΩ) 片端 | - |
| R1 (200kΩ) もう片端 | R2 (200kΩ) 片端 | - |
| R1-R2 接続点 | XIAO D0 (GPIO2) | - |
| R2 (200kΩ) もう片端 | GND | - |

### Wake-upボタン

| 接続元 | 接続先 | 部品 |
|---|---|---|
| XIAO D1 (GPIO3) | タクトスイッチ 片端 | - |
| タクトスイッチ もう片端 | GND | - |

### 電源スイッチ

| 接続元 | 接続先 | 部品 |
|---|---|---|
| Li-Po BAT+ | トグルスイッチ COM | JST-PHコネクタ |
| トグルスイッチ NO | XIAO BAT+パッド | はんだ付け |
| Li-Po BAT- | XIAO GND | JST-PHコネクタ |

---

## 部品リスト

| 部品 | 仕様 | 数量 | 秋月コード | 備考 |
|---|---|---|---|---|
| 抵抗 | 200kΩ 1/4W 1% | 2 | - | 電圧分圧用 |
| トグルスイッチ | SPST | 1 | - | メイン電源 |
| タクトスイッチ | 6mm角 | 1 | 103647 | Wake-up用 |
| JST-PHコネクタ | 2ピン メス | 1 | - | バッテリー接続 |
| Li-Poバッテリー | 3.7V 500mAh以上 | 1 | - | 電源 |

---

## 安全上の注意

⚠️ **バッテリー取り扱い注意:**

1. **ショート厳禁:** BAT+とGNDを絶対にショートさせないこと
2. **極性確認:** バッテリーの+/-を必ず確認してから接続
3. **はんだ作業:** XIAOのBAT+パッドへのはんだ付けは慎重に（隣接パッドとのブリッジに注意）
4. **過放電防止:** 3.0V以下まで放電させないこと（ファームウェアで保護）
5. **保管:** 使用しない場合はトグルスイッチをOFFにして保管

---

## 変更履歴

| 日付 | 内容 | 変更者 |
|---|---|---|
| 2026-01-11 | 初版作成 | - |

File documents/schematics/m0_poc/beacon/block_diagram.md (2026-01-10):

# M0 Beacon（送信）ブロック図

## 回路ブロック図

```
┌─────────────────────────────────────────────────────────────────────┐
│                         ESP32-S3                                    │
│  ┌──────────────────────────────────────────────────────────────┐  │
│  │  LEDC / PWM Generator                                         │  │
│  │  ├─ 20kHz, 50% duty                                          │  │
│  │  └─ 将来: TDMスロット制御                                     │  │
│  └──────────────────────────────────────────────────────────────┘  │
│           │ PWM                    │ PWM_INV (反転)                 │
│           │ GPIO_TBD               │ GPIO_TBD                       │
└───────────┼────────────────────────┼────────────────────────────────┘
            │                        │
            ▼                        ▼
┌─────────────────────────────────────────────────────────────────────┐
│                      DRV8835 モジュール                              │
│  ┌────────────────────────────────────────────────────────────┐    │
│  │  VCC ←── 5V (USB)                                          │    │
│  │  GND ←── GND                                               │    │
│  │  VIN ←── 3.3V (ロジック電圧)                                │    │
│  │  MODE ←── Hi (IN/IN モード)                                │    │
│  │                                                            │    │
│  │  AIN1 ←── PWM                                              │    │
│  │  AIN2 ←── PWM_INV (または GND固定)                         │    │
│  │                                                            │    │
│  │  AOUT1 ──┬──→ 送信コイル端子A                              │    │
│  │  AOUT2 ──┴──→ 送信コイル端子B                              │    │
│  └────────────────────────────────────────────────────────────┘    │
│                                                                     │
│  デカップリング:                                                    │
│  ├─ 0.1µF (5V-GND) ← VCC近傍                                       │
│  └─ 100µF電解 (5V-GND) ← 電源バルク                                │
└─────────────────────────────────────────────────────────────────────┘
            │
            ▼
┌─────────────────────────────────────────────────────────────────────┐
│                     送信コイル + 共振C                               │
│  ┌────────────────────────────────────────────────────────────┐    │
│  │                                                            │    │
│  │    AOUT1 ────┬────[  L (コイル)  ]────┬──── AOUT2          │    │
│  │              │                        │                    │    │
│  │              └────[  C (共振C)   ]────┘                    │    │
│  │                                                            │    │
│  │  ※ L-C並列で20kHz付近に共振点を合わせる                    │    │
│  │  ※ Cは実測で最適値を探索                                   │    │
│  └────────────────────────────────────────────────────────────┘    │
└─────────────────────────────────────────────────────────────────────┘
            │
            ▼
        【磁界放射】
```

## DRV8835 駆動モードの選択

### 推奨: IN/IN モード（MODE = Hi）

| AIN1 | AIN2 | AOUT1 | AOUT2 | 動作 |
|---|---|---|---|---|
| Hi | Lo | Hi | Lo | 正方向 |
| Lo | Hi | Lo | Hi | 逆方向 |
| Hi | Hi | Hi | Hi | ブレーキ |
| Lo | Lo | Lo | Lo | コースト |

### ±駆動（推奨）

```
AIN1 = PWM (20kHz, 50%)
AIN2 = PWM反転 (20kHz, 50%, 位相180°)

→ コイルに交互に±電圧が印加され、磁界強度が最大化
```

### 片側駆動（簡易版）

```
AIN1 = PWM (20kHz, 50%)
AIN2 = Lo 固定

→ 配線は簡単だが、磁界強度は±駆動の半分程度
```

## 共振Cの選定

共振周波数: f = 1 / (2π√(LC))

20kHz共振の場合:
- L = 7.7mH → C ≈ 8200pF
- L = 6.5mH → C ≈ 9700pF

**実測手順:**
1. まず共振Cなしで送信
2. 8200pF → 8760pF → 9700pF の順で試す
3. 受信側のI/Q振幅Aが最大になるCを採用

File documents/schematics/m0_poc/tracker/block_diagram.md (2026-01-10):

# M0 Tracker（受信）ブロック図

## 回路ブロック図

```
┌─────────────────────────────────────────────────────────────────────┐
│                       受信コイル                                     │
│  ┌────────────────────────────────────────────────────────────┐    │
│  │                                                            │    │
│  │    端子A ────[  L (コイル)  ]──── 端子B                     │    │
│  │       │                            │                       │    │
│  │       └─→ Vmidへ接続               └─→ アンプ入力へ        │    │
│  │                                                            │    │
│  └────────────────────────────────────────────────────────────┘    │
└─────────────────────────────────────────────────────────────────────┘
            │
            ▼
┌─────────────────────────────────────────────────────────────────────┐
│                     Vmid生成（仮想GND）                              │
│  ┌────────────────────────────────────────────────────────────┐    │
│  │                                                            │    │
│  │   3.3V ──[10kΩ]──┬──[10kΩ]── GND                          │    │
│  │                   │                                        │    │
│  │                   ├── 0.1µF ── GND (平滑)                  │    │
│  │                   │                                        │    │
│  │                   └──→ MCP6022 電圧フォロワ入力            │    │
│  │                              │                             │    │
│  │                              └──→ Vmid (バッファ後)        │    │
│  │                                   = 1.65V (安定)           │    │
│  └────────────────────────────────────────────────────────────┘    │
└─────────────────────────────────────────────────────────────────────┘
            │
            ▼
┌─────────────────────────────────────────────────────────────────────┐
│              MCP6022 受信アンプ（非反転増幅）                        │
│  ┌────────────────────────────────────────────────────────────┐    │
│  │                                                            │    │
│  │   【Vmidバッファ（1ch目）】                                │    │
│  │   Vmid_raw ──[+]──┬── Vmid_out                            │    │
│  │              [-]──┘                                        │    │
│  │                                                            │    │
│  │   【受信アンプ（2ch目）】                                  │    │
│  │                     ┌─[47pF]─┐                            │    │
│  │                     │        │                            │    │
│  │   コイル信号 ──[+]──┤        ├── ADC入力へ                │    │
│  │              [-]──┬─[10kΩ Rf]┘                            │    │
│  │                   │                                        │    │
│  │                [1kΩ Rg]                                    │    │
│  │                   │                                        │    │
│  │                 Vmid                                       │    │
│  │                                                            │    │
│  │   Gain = 1 + Rf/Rg = 1 + 10k/1k = 11倍                    │    │
│  │                                                            │    │
│  └────────────────────────────────────────────────────────────┘    │
│                                                                     │
│  電源デカップリング:                                                │
│  └─ 0.1µF (VDD-GND) ← IC近傍                                       │
└─────────────────────────────────────────────────────────────────────┘
            │
            ▼
┌─────────────────────────────────────────────────────────────────────┐
│                  入力保護（BAT43クランプ）                           │
│  ┌────────────────────────────────────────────────────────────┐    │
│  │                                                            │    │
│  │   3.3V ──|◁── ADC入力 ──▷|── GND                          │    │
│  │       (BAT43)          (BAT43)                             │    │
│  │                                                            │    │
│  │   ※ 過大入力時に3.3VまたはGNDへクランプ                   │    │
│  │   ※ 実験中の誤配線対策                                    │    │
│  └────────────────────────────────────────────────────────────┘    │
└─────────────────────────────────────────────────────────────────────┘
            │
            ▼
┌─────────────────────────────────────────────────────────────────────┐
│                      MCP3008（ADC）                                  │
│  ┌────────────────────────────────────────────────────────────┐    │
│  │                                                            │    │
│  │   VDD = 3.3V ──┬── 0.1µF ── GND                           │    │
│  │   VREF = 3.3V ──┬── 0.1µF ── AGND                         │    │
│  │                                                            │    │
│  │   CH0 ←── 受信アンプ出力                                  │    │
│  │   CH1〜CH7: 未使用（将来3軸用）                            │    │
│  │                                                            │    │
│  │   SPI:                                                     │    │
│  │   ├─ CLK  ──→ ESP32 GPIO_TBD                              │    │
│  │   ├─ DOUT ──→ ESP32 GPIO_TBD (MISO)                       │    │
│  │   ├─ DIN  ←── ESP32 GPIO_TBD (MOSI)                       │    │
│  │   └─ CS   ←── ESP32 GPIO_TBD                              │    │
│  │                                                            │    │
│  └────────────────────────────────────────────────────────────┘    │
└─────────────────────────────────────────────────────────────────────┘
            │
            ▼
┌─────────────────────────────────────────────────────────────────────┐
│                         ESP32-S3                                    │
│  ┌────────────────────────────────────────────────────────────┐    │
│  │                                                            │    │
│  │   SPI受信 → I/Q処理                                        │    │
│  │   ├─ cos/sin参照波と乗算                                   │    │
│  │   ├─ 積分窓長で積分                                        │    │
│  │   └─ A = √(I²+Q²), φ = atan2(Q,I)                         │    │
│  │                                                            │    │
│  │   出力: 振幅A（主要評価値）                                │    │
│  │                                                            │    │
│  └────────────────────────────────────────────────────────────┘    │
└─────────────────────────────────────────────────────────────────────┘
```

## アンプゲイン調整

| 状態 | 対策 |
|---|---|
| ADCが飽和（0または3.3Vに張り付く） | Rfを小さく（例: 5.1kΩでGain≈6） |
| 信号が小さすぎる | Rfを大きく（例: 22kΩでGain≈23） |
| 発振する | 47pFを追加、または大きく |

## ADCサンプルレート設定

MCP3008の理論最大: 200ksps @ 5V, 75ksps @ 2.7V

**PoC目標:** ≥80ksps

ESP32側のSPIクロック設定で調整

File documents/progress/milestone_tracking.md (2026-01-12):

# マイルストーン進捗管理

## 現在のフェーズ: M0（1軸ディスクリートPoC）

---

## フェーズ別ドキュメント

| フェーズ | 仕様書 | BOM | 回路図 | 組み立て | 実験ログ |
|---|---|-----|---|---|---|
| M0 | [仕様](../requirements/m0_poc/) | [BOM](../bom/m0_poc/) | [回路図](../schematics/m0_poc/) | [組み立て](../assembly/m0_poc/) | [ログ](m0_poc/experiment_log.md) |
| M1 | [仕様](../requirements/m1_3axis/) | [BOM](../bom/m1_3axis/) | [回路図](../schematics/m1_3axis/) | [組み立て](../assembly/m1_3axis/) | [ログ](m1_3axis/) |
| M1.5 | [仕様](../requirements/m1.5_coil_power/) | [BOM](../bom/m1.5_coil_power/) | [回路図](../schematics/m1.5_coil_power/) | [組み立て](../assembly/m1.5_coil_power/) | [ログ](m1.5_coil_power/) |

---

## 使用機材

| 部品 | 型番 | 数量 | ステータス |
|---|---|---|---|
| MCU | XIAO ESP32C3 | **2** | ✅ 入手済み |
| 3軸コイル | 3D11-722J | **5** | ✅ 入手済み |
| モータドライバ | DRV8835モジュール | 2 | ✅ 入手済み |
| オペアンプ | MCP6022-I/P | 2 | ✅ 入手済み |
| ADC | MCP3008-I/P | 1 | ✅ 入手済み |
| **加速度センサー** | **LIS3DH（ブレークアウト）** | **1** | ⬜ 未入手（M1用） |
| 受動部品（R,C） | 各種 | 適量 | ✅ 入手済み |
| ブレッドボード | EIC-106J | 1 | ✅ 入手済み |

---

## M0: 1軸ディスクリートPoC

**目標:** Aの安定算出、C最適化、距離/角度応答の確認

### タスク一覧

| # | タスク | ステータス | 開始日 | 完了日 | 備考 |
|---|---|---|---|---|---|
| 0.1 | 部品確認・在庫チェック | ✅ 完了 | 2026-01-07 | 2026-01-07 | |
| 0.2 | GPIO割り当て確定 | ✅ 完了 | 2026-01-07 | 2026-01-07 | XIAO ESP32C3 |
| 0.3 | Vmid生成回路組み立て | ✅ 完了 | 2026-01-11 | 2026-01-11 | |
| 0.4 | 受信アンプ組み立て | ✅ 完了 | 2026-01-11 | 2026-01-11 | |
| 0.5 | ADC(MCP3008)接続・動作確認 | ⬜ 未着手 | - | - | |
| 0.6 | 送信回路(DRV8835)組み立て | ⬜ 未着手 | - | - | |
| 0.7 | PWM生成ファームウェア | ⬜ 未着手 | - | - | |
| 0.8 | I/Q処理ファームウェア | ⬜ 未着手 | - | - | |
| 0.9 | 共振C探索 | ⬜ 未着手 | - | - | 3D11-722J: L≈7.2mH |
| 0.10 | 距離・角度応答測定 | ⬜ 未着手 | - | - | |
| 0.11 | AC-01〜04達成確認 | ⬜ 未着手 | - | - | |

### ステータス凡例
- ⬜ 未着手
- 🔄 進行中
- ✅ 完了
- ⏸️ 保留
- ❌ 中止

---

## M1: 3軸TDM（ディスクリート）+ LIS3DH統合

**目標:** (Ax,Ay,Az)がスロットで正しく分離できる、軸干渉・過渡対策のパラメータ確立、Hemispheric ambiguity解決

| # | タスク | ステータス | 開始日 | 完了日 | 備考 |
|---|---|---|---|---|---|
| 1.1 | 3D11-722J Y/Z軸接続 | ⬜ 未着手 | - | - | |
| 1.2 | DRV8835 2枚構成 | ⬜ 未着手 | - | - | |
| 1.3 | 3軸受信アンプ構成 | ⬜ 未着手 | - | - | MCP6022 2枚使用 |
| 1.4 | TDMスロット制御実装 | ⬜ 未着手 | - | - | |
| 1.5 | 軸間干渉測定・対策 | ⬜ 未着手 | - | - | |
| 1.6 | settling time最適化 | ⬜ 未着手 | - | - | |
| **1.7** | **LIS3DH購入・接続** | ⬜ 未着手 | - | - | **Hemispheric ambiguity解決用** |
| **1.8** | **LIS3DH FW実装** | ⬜ 未着手 | - | - | **重力方向検出** |
| **1.9** | **Hemispheric ambiguity検証** | ⬜ 未着手 | - | - | **IMUで上下識別** |

### Hemispheric Ambiguity解決方針

- **問題**: +X+Y+Zと-X-Y-Zが同じ磁界測定値になる
- **解決**: LIS3DH（3軸加速度センサー）で重力方向を検出し、上下を識別
- **参考**: Kirb EMトラッキング講義（BMI270使用、同様のアプローチ）
- **接続**: I2C（D4=SDA, D5=SCL）

---

## M1.5: 自作コイル＆ドライバ強化

**目標:** 送信距離を3m以上に拡大するための自作コイル製作とドライバ・電源強化

| # | タスク | ステータス | 開始日 | 完了日 | 備考 |
|---|---|---|---|---|---|
| 1.5.1 | 送信コイル設計（巻数・線径・コア検討） | ⬜ 未着手 | - | - | |
| 1.5.2 | コイル製作治具準備 | ⬜ 未着手 | - | - | |
| 1.5.3 | 送信コイル製作・インダクタンス測定 | ⬜ 未着手 | - | - | |
| 1.5.4 | 高出力ドライバ選定・評価 | ⬜ 未着手 | - | - | DRV8835以外を検討 |
| 1.5.5 | 電源強化（専用電源 or 昇圧回路） | ⬜ 未着手 | - | - | |
| 1.5.6 | 距離レンジ測定（1m/2m/3m） | ⬜ 未着手 | - | - | |
| 1.5.7 | 熱設計・連続動作テスト | ⬜ 未着手 | - | - | |

---

## M2: 3軸SMD試作基板

**目標:** ディスクリートPoCと同等のA応答を再現、ノイズ・再現性の改善

| # | タスク | ステータス | 開始日 | 完了日 | 備考 |
|---|---|---|---|---|---|
| 2.0 | バッテリー駆動仕様策定 | ✅ 完了 | 2026-01-11 | 2026-01-11 | GPIO割り当て、電源回路設計 |
| 2.0.1 | 電源回路図作成 | ✅ 完了 | 2026-01-11 | 2026-01-11 | 電圧監視、Wake-up回路 |
| 2.0.2 | バッテリー監視ファームウェア | ✅ 完了 | 2026-01-11 | 2026-01-11 | battery_monitor.h/cpp |
| 2.0.3 | DEEP SLEEP実装 | ✅ 完了 | 2026-01-11 | 2026-01-11 | power_manager.h/cpp |
| 2.1 | 回路図設計 | ⬜ 未着手 | - | - | |
| 2.2 | 基板レイアウト | ⬜ 未着手 | - | - | |
| 2.3 | 基板発注 | ⬜ 未着手 | - | - | |
| 2.4 | 実装・動作確認 | ⬜ 未着手 | - | - | |

---

## M3: 推定アルゴリズム拡張

**目標:** 3軸観測ベクトルを用いた姿勢/位置推定の初期実装

| # | タスク | ステータス | 開始日 | 完了日 | 備考 |
|---|---|---|---|---|---|
| 3.1 | 磁界モデル実装 | ⬜ 未着手 | - | - | |
| 3.2 | 姿勢推定アルゴリズム | ⬜ 未着手 | - | - | |
| 3.3 | 位置推定アルゴリズム | ⬜ 未着手 | - | - | |

---

## M4: 製品化要素

**目標:** 送信出力拡張、無線多端末、HMDアンカー整列

| # | タスク | ステータス | 開始日 | 完了日 | 備考 |
|---|---|---|---|---|---|
| 4.1 | 高出力ドライバ選定 | ⬜ 未着手 | - | - | |
| 4.2 | 無線プロトコル設計 | ⬜ 未着手 | - | - | |
| 4.3 | VRChat連携実装 | ⬜ 未着手 | - | - | |

---

## 変更履歴

| 日付 | 内容 | 変更者 |
|---|---|---|
| 2026-01-07 | 初版作成 | - |
| 2026-01-07 | XIAO ESP32C3, 3D11-722J追加 | - |
| 2026-01-07 | フェーズ別フォルダ構成に対応 | - |
| 2026-01-07 | M1.5（自作コイル＆ドライバ強化）追加 | - |
| 2026-01-11 | M0: Vmid生成回路と受信アンプ組み立て完了 | - |
| 2026-01-11 | M2: バッテリー駆動仕様策定・ファームウェア実装 | - |
| 2026-01-13 | M1: LIS3DH統合タスク追加（1.7-1.9）、Hemispheric ambiguity解決方針追記 | - |

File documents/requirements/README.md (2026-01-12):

# 仕様・要件

## フォルダ構成

```
requirements/
├── README.md          # このファイル
├── m0_poc/           # M0: 1軸ディスクリートPoC
│   ├── specification_v0.9.md
│   └── acceptance_criteria.md
├── m1_3axis/         # M1: 3軸TDM + LIS3DH統合
│   └── lis3dh_integration.md
├── m1.5_coil_power/  # M1.5: 自作コイル＆ドライバ強化
│   └── specification.md
├── m2_smd/           # M2: SMD基板化
│   └── specification.md
├── lis3dh/           # LIS3DHデータシート
│   └── lis3dh.pdf
└── common/           # 共通仕様
```

## 各フェーズの仕様書

| フェーズ | 仕様書 | 達成基準 | 追加仕様 |
|---|---|---|---|
| M0 | [specification_v0.9.md](m0_poc/specification_v0.9.md) | [acceptance_criteria.md](m0_poc/acceptance_criteria.md) | - |
| M1 | (M0仕様の拡張) | TBD | [LIS3DH統合](m1_3axis/lis3dh_integration.md) |
| M1.5 | [specification.md](m1.5_coil_power/specification.md) | TBD | - |
| M2 | [specification.md](m2_smd/specification.md) | TBD | - |

## Hemispheric Ambiguity解決

M1以降で使用するLIS3DH（3軸加速度センサー）による解決方法は以下を参照:
- [M1 LIS3DH統合仕様書](m1_3axis/lis3dh_integration.md)
- [M0仕様書 10.3節](m0_poc/specification_v0.9.md#103-hemispheric-ambiguity解決)

## 命名規則

- `specification_vX.Y.md` - 仕様書（バージョン付き）
- `acceptance_criteria.md` - 達成基準
- `design_notes.md` - 設計メモ（オプション）

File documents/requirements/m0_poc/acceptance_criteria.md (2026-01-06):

# Acceptance Criteria（達成基準）

## PoC（M0）達成条件

### 必須条件

| ID | 条件 | 測定方法 | 合格基準 |
|----|---|---|---|
| AC-01 | 振幅A安定性 | 送信ON時のA値を100サンプル取得 | 標準偏差 < 平均値の10% |
| AC-02 | 距離応答 | 距離5cm→10cm→15cmでA測定 | 単調減少を示すこと |
| AC-03 | ON/OFF判別 | 送信ON/OFF時のA値比較 | ON時のA > OFF時のA × 10 |
| AC-04 | 更新レート | I/Q算出時間を測定 | 16.7ms以内（60Hz相当） |

### 推奨条件（達成すればより良い）

| ID | 条件 | 測定方法 | 目標値 |
|----|---|---|---|
| AC-05 | 再現性 | 同一配置で3回測定 | A値の差 < 5% |
| AC-06 | 角度応答 | 0°/45°/90°でA測定 | 予測可能な変化パターン |

---

## M1（3軸TDM）達成条件

| ID | 条件 | 測定方法 | 合格基準 |
|----|---|---|---|
| AC-11 | 軸分離 | X送信時のAy, Az | 漏れ < Ax × 5% |
| AC-12 | 過渡安定 | スロット切替後のA安定時間 | < 1ms |
| AC-13 | 3軸同時取得 | (Ax, Ay, Az)を60Hz取得 | 欠落なく連続取得 |

---

## M2（SMD基板）達成条件

| ID | 条件 | 測定方法 | 合格基準 |
|----|---|---|---|
| AC-21 | 機能同等 | ディスクリートPoCと同条件で比較 | A値の差 < 10% |
| AC-22 | ノイズ改善 | ノイズフロア測定 | ディスクリート以下 |
| AC-23 | 再現性 | 3枚の基板で同一測定 | 基板間差 < 5% |

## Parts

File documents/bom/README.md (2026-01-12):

# 部品リスト（BOM）

## フォルダ構成

```
bom/
├── README.md          # このファイル
├── m0_poc/           # M0: 1軸ディスクリートPoC
│   └── bom.md
├── m1_3axis/         # M1: 3軸TDM + LIS3DH
│   └── bom.md
├── m1.5_coil_power/  # M1.5: 自作コイル＆ドライバ強化
└── m2_smd/           # M2: SMD基板化
    └── bom.md
```

## 各フェーズのBOM

| フェーズ | BOM | 特徴 |
|---|-----|---|
| M0 | [bom.md](m0_poc/bom.md) | 1軸ディスクリートPoC |
| M1 | [bom.md](m1_3axis/bom.md) | 3軸TDM + LIS3DHブレークアウト |
| M2 | [bom.md](m2_smd/bom.md) | SMD基板化、LIS3DH直付け |

## 共通部品（購入済み）

| 部品 | 型番 | 入手先 |
|---|---|---|
| MCU | XIAO ESP32C3 | AliExpress |
| 3軸コイル | 3D11-722J | AliExpress |
| モータドライバ | DRV8835モジュール | 秋月電子 |
| オペアンプ | MCP6022-I/P | 秋月電子 |
| ADC | MCP3008-I/P | 秋月電子 |

## M1以降で追加（要購入）

| 部品 | 型番 | 入手先 | 用途 |
|---|---|---|---|
| 加速度センサー | LIS3DH（ブレークアウト） | 秋月/Adafruit/AliExpress | Hemispheric ambiguity解決 |

## M2以降で追加（SMD実装）

| 部品 | 型番 | パッケージ | 入手先 | 用途 |
|---|---|---|---|---|
| 加速度センサー | LIS3DHTR | LGA-16 | DigiKey/LCSC | SMD直付け |
| デカップリング | 100nF | 0402/0603 | - | 各IC用 |
| バルクC | 10µF | 0603/0805 | - | 電源安定化 |
| プルアップR | 4.7kΩ | 0402/0603 | - | I2C用 |
| 分圧R | 1MΩ | 0402/0603 | - | バッテリー監視用 |

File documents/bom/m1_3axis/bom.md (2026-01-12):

# M1 3軸TDM 部品リスト（BOM）

## 概要

3軸TDMディスクリート実装用の部品リスト（M0からの追加分）

**M1追加機能**: LIS3DH（3軸加速度センサー）によるHemispheric ambiguity解決

---

## M0で購入済み部品からの流用

| 秋月コード | 商品名 | M0残り | M1使用 | 備考 |
|---|---|---|---|---|
| [109848](https://akizukidenshi.com/catalog/g/g109848/) | DRV8835モジュール | 1 | 1 | 3軸駆動（計2枚で4ch→3ch使用） |
| [116187](https://akizukidenshi.com/catalog/g/g116187/) | MCP6022-I/P | 1 | 1 | 残り2ch（+増幅2ch分） |
| [116877](https://akizukidenshi.com/catalog/g/g116877/) | 10kΩ 0.1% | 7 | 2 | Rf追加分 |
| [116876](https://akizukidenshi.com/catalog/g/g116876/) | 1kΩ 0.1% | 9 | 2 | Rg追加分 |
| [108045](https://akizukidenshi.com/catalog/g/g108045/) | 47pF C0G | 9 | 2 | 発振防止追加分 |
| [117059](https://akizukidenshi.com/catalog/g/g117059/) | 0.1µF C0G | 6 | 2 | デカップリング追加分 |
| [105002](https://akizukidenshi.com/catalog/g/g105002/) | 100µF電解 | 3 | 1 | DRV8835 #2用 |

### コイル（追加購入不要）

| 入手先 | 商品名 | M0残り | M1使用 | 備考 |
|---|---|---|---|---|
| AliExpress | 3D11-722J 3軸コイル | **3** | 2 | 送信Y/Z軸用（各1個）または受信Y/Z軸用 |

---

## M1で追加購入が必要な部品

### LIS3DH（3軸加速度センサー）— Hemispheric Ambiguity解決用

| 入手先 | 商品名 | 価格 | 数量 | 備考 |
|---|---|---|---|---|
| 秋月電子 | LIS3DHモジュール | 約¥500 | 1 | ブレッドボード対応推奨 |
| AliExpress | GY-LIS3DH | 約$2-3 | 1 | 安価だが配送時間あり |
| Adafruit | LIS3DH Breakout | 約$8 | 1 | 品質安定、ライブラリ充実 |

**LIS3DH仕様**:
- メーカー: STMicroelectronics
- 電源電圧: 1.71V〜3.6V
- インターフェース: I2C / SPI
- I2Cアドレス: 0x18（SA0=GND）または 0x19（SA0=VDD）
- 消費電力: 超低消費（2µA @ 1Hz）
- データシート: `documents/requirements/lis3dh/lis3dh.pdf`

**接続（I2C）**:

| LIS3DH | XIAO ESP32C3 | GPIO |
|---|---|---|
| SDA | D4 | GPIO6 |
| SCL | D5 | GPIO7 |
| VDD | 3.3V | - |
| GND | GND | - |
| SA0 | GND | - （アドレス0x18） |

**追加部品（ブレークアウトボードに内蔵の場合は不要）**:

| 部品 | 値 | 数量 | 用途 |
|---|-----|---|---|
| プルアップ抵抗 | 4.7kΩ | 2 | I2C SDA, SCL |

---

### 送信コイル（3D11-722Jから流用）

| 品名 | 仕様 | 数量 | 用途 | 備考 |
|---|---|---|---|---|
| 送信コイル Y軸 | 3D11-722J | 1 | Y軸磁界生成 | M0残りから流用 |
| 送信コイル Z軸 | 3D11-722J | 1 | Z軸磁界生成 | M0残りから流用 |
| 共振C Y軸 | 最適値 | 1セット | Y軸波形整形 | M0で最適値確定後 |
| 共振C Z軸 | 最適値 | 1セット | Z軸波形整形 | M0で最適値確定後 |

### 受信コイル（3D11-722Jから流用）

| 品名 | 仕様 | 数量 | 用途 | 備考 |
|---|---|---|---|---|
| 受信コイル Y軸 | 3D11-722J | 1 | Y軸誘導電圧検出 | M0残りから流用 |
| 受信コイル Z軸 | 3D11-722J | 1 | Z軸誘導電圧検出 | M0残りから流用 |

### 3軸コイル候補

| タイプ | 仕様 | メリット | デメリット |
|---|---|---|---|
| 3Dコイル（市販） | 直交3軸一体型 | 位置精度高い | 入手性、サイズ制約 |
| 立方体巻線（自作） | 50mm立方体、各面に巻線 | カスタマイズ可 | 製作手間 |
| 個別コイル3個配置 | 独立コイル×3 | 簡単 | 位置合わせ困難 |

---

## M1完成時の総部品使用数

| 部品 | M0 | M1追加 | 合計 | 在庫残り |
|---|-----|---|---|---|
| XIAO ESP32C3 | 1 | 0 | 1 | 1 |
| DRV8835モジュール | 1 | 1 | 2 | 0 |
| MCP6022 | 1 | 1 | 2（計4ch） | 0 |
| MCP3008 | 1 | 0 | 1（3ch使用） | 0 |
| 3D11-722J | 2 | 2 | 4 | **1** |
| **LIS3DH** | 0 | **1** | **1** | - |
| 10kΩ (Rf) | 1 | 2 | 3 | 7 |
| 1kΩ (Rg) | 1 | 2 | 3 | 9 |
| 47pF | 1 | 2 | 3 | 9 |
| 4.7kΩ（I2Cプルアップ） | 0 | 2 | 2 | - |

---

## GPIO割り当て（3軸時）

※ ESP32S3の型番確定後に詳細化

### 送信側

| 機能 | DRV8835 | GPIO | 備考 |
|---|---|---|---|
| PWM_X | #1 AIN1 | TBD | X軸送信 |
| PWM_X_INV | #1 AIN2 | TBD | X軸反転PWM |
| PWM_Y | #1 BIN1 | TBD | Y軸送信 |
| PWM_Y_INV | #1 BIN2 | TBD | Y軸反転PWM |
| PWM_Z | #2 AIN1 | TBD | Z軸送信 |
| PWM_Z_INV | #2 AIN2 | TBD | Z軸反転PWM |

### 受信側

| 機能 | MCP3008 CH | 備考 |
|---|---|---|
| RX_X | CH0 | X軸受信 |
| RX_Y | CH1 | Y軸受信 |
| RX_Z | CH2 | Z軸受信 |

### SPI（共通）

| 信号 | GPIO | 備考 |
|---|---|---|
| SPI_CLK | GPIO8 (D8) | MCP3008 CLK |
| SPI_MOSI | GPIO10 (D10) | MCP3008 DIN |
| SPI_MISO | GPIO9 (D9) | MCP3008 DOUT |
| SPI_CS | GPIO20 (D7) | MCP3008 CS |

### I2C（LIS3DH用）

| 信号 | GPIO | 備考 |
|---|---|---|
| I2C_SDA | GPIO6 (D4) | LIS3DH SDA |
| I2C_SCL | GPIO7 (D5) | LIS3DH SCL |

---

## DRV8835 2枚構成

### DRV8835 #1（M0から使用）

| 出力 | 接続先 |
|---|---|
| AOUT1/2 | X軸送信コイル |
| BOUT1/2 | Y軸送信コイル |

### DRV8835 #2（M1で追加）

| 出力 | 接続先 |
|---|---|
| AOUT1/2 | Z軸送信コイル |
| BOUT1/2 | 未使用 |

---

## MCP6022 2枚構成

### MCP6022 #1（M0から使用）

| チャンネル | 用途 |
|---|---|
| A | Vmidバッファ |
| B | X軸受信アンプ |

### MCP6022 #2（M1で追加）

| チャンネル | 用途 |
|---|---|
| A | Y軸受信アンプ |
| B | Z軸受信アンプ |

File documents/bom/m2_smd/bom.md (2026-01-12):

# M2 SMD基板 部品リスト（BOM）

## 概要

3軸SMD試作基板用の部品リスト（Tracker側）

**M2の特徴**:
- SMD直付け実装（devボードではなくIC直接実装）
- LIS3DH (LGA-16) + 周辺部品
- バッテリー駆動対応

---

## LIS3DH（3軸加速度センサー）— SMD実装

### IC

| 入手先 | 型番 | パッケージ | 価格 | 数量 | 備考 |
|---|---|---|---|---|---|
| DigiKey | LIS3DHTR | LGA-16 (3x3x1mm) | 約$1.5 | 1 | |
| LCSC | LIS3DHTR | LGA-16 (3x3x1mm) | 約$0.8 | 1 | 中国発送 |
| AliExpress | LIS3DHTR | LGA-16 (3x3x1mm) | 約$0.5-1 | 1 | 安価だが品質要確認 |

**データシート**: [`documents/requirements/lis3dh/lis3dh.pdf`](../../requirements/lis3dh/lis3dh.pdf)

### LIS3DH周辺部品

| 部品 | 値 | パッケージ | 数量 | 接続先 | 用途 | 備考 |
|---|-----|---|---|---|---|---|
| C1 | 100nF | 0402/0603 | 1 | VDD-GND | デカップリング | 必須 |
| C2 | 10µF | 0603/0805 | 1 | VDD-GND | バルクデカップリング | 推奨 |
| C3 | 100nF | 0402/0603 | 1 | VDD_IO-GND | IO電源デカップリング | VDD共用可 |
| R1 | 4.7kΩ | 0402/0603 | 1 | SDA-3.3V | I2Cプルアップ | |
| R2 | 4.7kΩ | 0402/0603 | 1 | SCL-3.3V | I2Cプルアップ | |

### LIS3DH接続

| LIS3DHピン | 接続先 | 備考 |
|---|---|---|
| VDD | 3.3V | 電源 |
| VDD_IO | 3.3V | IO電源（VDD共用可） |
| GND | GND | |
| SDA | GPIO6 (D4) + 4.7kΩプルアップ | I2Cデータ |
| SCL | GPIO7 (D5) + 4.7kΩプルアップ | I2Cクロック |
| SA0 | GND | I2Cアドレス=0x18 |
| CS | VDD | I2Cモード選択（SPIモードでは未使用） |
| INT1 | NC | 将来拡張用（割り込み） |
| INT2 | NC | 将来拡張用（割り込み） |

---

## バッテリー監視回路

**参考**: [`documents/outside_sources/Xiao_ESP32C3_battery/lipo_overdischarge_protection.md`](../../outside_sources/Xiao_ESP32C3_battery/lipo_overdischarge_protection.md)

### 分圧回路部品

| 部品 | 値 | パッケージ | 数量 | 用途 | 備考 |
|---|-----|---|---|---|---|
| R3 | 1MΩ | 0402/0603 | 1 | 分圧上側 | 漏電電流削減のため1MΩ推奨 |
| R4 | 1MΩ | 0402/0603 | 1 | 分圧下側 | |
| C4 | 100nF | 0402/0603 | 1 | ADC入力安定化 | オプション |

### 接続

| 信号 | 接続先 | 備考 |
|---|---|---|
| LiPo+ | R3 (1MΩ) → ADC入力 (D0/GPIO2) | 分圧後 |
| ADC入力 | R4 (1MΩ) → GND | |
| 分圧比 | 0.5 | V_adc = V_battery × 0.5 |

---

## MCU周辺部品

### XIAO ESP32C3用

| 部品 | 値 | パッケージ | 数量 | 用途 | 備考 |
|---|-----|---|---|---|---|
| C5 | 100nF | 0402/0603 | 1 | 3.3V デカップリング | |
| C6 | 10µF | 0603/0805 | 1 | 3.3V バルク | |

---

## ADC (MCP3008) 周辺部品

| 部品 | 値 | パッケージ | 数量 | 用途 | 備考 |
|---|-----|---|---|---|---|
| C7 | 100nF | 0402/0603 | 1 | VDD-DGND | デカップリング |
| C8 | 100nF | 0402/0603 | 1 | VREF-AGND | リファレンス安定化 |

---

## アナログフロントエンド (MCP6022) 周辺部品

### 各軸アンプ（X/Y/Z × 3セット）

| 部品 | 値 | パッケージ | 数量 | 用途 | 備考 |
|---|-----|---|---|---|---|
| Rf | 10kΩ | 0402/0603 | 3 | フィードバック抵抗 | ゲイン設定 |
| Rg | 1kΩ | 0402/0603 | 3 | ゲイン設定抵抗 | |
| Cf | 47pF | 0402/0603 | 3 | 発振防止 | Rfに並列 |

### Vmid生成

| 部品 | 値 | パッケージ | 数量 | 用途 | 備考 |
|---|-----|---|---|---|---|
| R_vmid1 | 10kΩ | 0402/0603 | 1 | 分圧上側 | 3.3V → Vmid |
| R_vmid2 | 10kΩ | 0402/0603 | 1 | 分圧下側 | Vmid → GND |
| C_vmid | 100nF | 0402/0603 | 1 | Vmid平滑 | |

---

## M2 GPIO割り当て（Tracker側）

| 機能 | ピン | GPIO | ADC | 備考 |
|---|---|---|-----|---|
| バッテリー監視 | D0 | GPIO2 | ✅ ADC1 | 分圧回路経由 |
| Wake-upボタン | D1 | GPIO3 | ✅ ADC1 | Deep Sleep復帰 |
| 空き | D2 | GPIO4 | ✅ ADC1 | |
| 空き | D3 | GPIO5 | ❌ | |
| I2C_SDA (LIS3DH) | D4 | GPIO6 | ❌ | |
| I2C_SCL (LIS3DH) | D5 | GPIO7 | ❌ | |
| 空き | D6 | GPIO21 | ❌ | |
| SPI_CS (MCP3008) | D7 | GPIO20 | ❌ | |
| SPI_SCK (MCP3008) | D8 | GPIO8 | ❌ | |
| SPI_MISO (MCP3008) | D9 | GPIO9 | ❌ | |
| SPI_MOSI (MCP3008) | D10 | GPIO10 | ❌ | |

**使用ピン数**: 8（SPI 4 + I2C 2 + バッテリー監視 1 + Wake-up 1）
**空きピン数**: 3（D2, D3, D6）

---

## 部品サマリー

### SMD部品一覧

| カテゴリ | 部品 | 値 | パッケージ | 数量 |
|---|---|-----|---|---|
| IC | LIS3DHTR | - | LGA-16 | 1 |
| コンデンサ | デカップリング | 100nF | 0402/0603 | 6 |
| コンデンサ | バルク | 10µF | 0603/0805 | 2 |
| 抵抗 | I2Cプルアップ | 4.7kΩ | 0402/0603 | 2 |
| 抵抗 | バッテリー分圧 | 1MΩ | 0402/0603 | 2 |
| 抵抗 | ゲイン設定 (Rf) | 10kΩ | 0402/0603 | 4 |
| 抵抗 | ゲイン設定 (Rg) | 1kΩ | 0402/0603 | 3 |
| コンデンサ | 発振防止 | 47pF | 0402/0603 | 3 |

### 実装上の注意

1. **LIS3DH (LGA-16)**: 3x3mmの微小パッケージ、リフローはんだ付け推奨
2. **パッド設計**: データシートのフットプリント推奨値に従う
3. **配線**: I2Cラインは短く、GNDプレーンから離す
4. **デカップリング**: ICの近傍に配置

---

## 参考資料

- [LIS3DHデータシート](../../requirements/lis3dh/lis3dh.pdf)
- [XIAO ESP32C3 バッテリー駆動設定](../../outside_sources/Xiao_ESP32C3_battery/lipo_overdischarge_protection.md)
- [M2電源回路図](../../schematics/m2_smd/tracker/power_schematic.md)

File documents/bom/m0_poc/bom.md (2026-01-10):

# M0 PoC 部品リスト（BOM）

## 概要

1軸ディスクリートPoC用の部品リスト

---

## 購入済み部品一覧

### マイコン

| 入手先 | 商品名 | 数量 | 用途 | リンク |
|---|---|---|---|---|
| AliExpress | XIAO ESP32C3 Development Board | **2** | 送信用×1、受信用×1（M0では1台で送受信兼用も可） | [リンク](https://ja.aliexpress.com/item/1005006114576182.html) |

### コイル

| 入手先 | 商品名 | 数量 | 用途 | リンク |
|---|---|---|---|---|
| AliExpress | 3D11-722J 3軸コイル | **5** | M0: 送信用×1、受信用×1（残り3個はM1/M1.5用） | [リンク](https://ja.aliexpress.com/item/1005004723068527.html) |

**3D11-722J スペック:**
- インダクタンス: 各軸約7.2mH（722 = 7200µH）
- 構造: 3軸直交コイル内蔵
- **パッケージ: SMD**（ブレッドボード直接使用不可）

### 3D11-722Jテストボード

| 入手先 | 商品名 | 数量 | 用途 | リンク |
|---|---|---|---|---|
| 自作基板 | 3D11-722Jテストボード（単体版） | 2枚 | 送信用×1、受信用×1 | [KiCad設計](../../../kicad/3D11_test_Board/) |
| 自作基板 | 3D11-722Jテストボード（パネル版） | 1パネル（10枚） | 量産用（M0では2枚使用、残りはM1以降用） | [KiCad設計](../../../kicad/3D11_production/) |

**テストボードの部品（1枚あたり）:**
- 3D11-722Jコイル × 1個
- ピンヘッダー 1×4（2.54mmピッチ）× 2本（上部・下部用）

💡 **基板発注について:**
- KiCadファイルからGerberファイル（`garber.zip`）を生成して基板発注
- 単体版: プロトタイプ用
- パネル版: 10枚まとめて発注する場合（到着後、個別基板に切り離す）

### アクティブ部品（秋月電子）

| 秋月コード | 商品名 | 数量 | 単価 | 用途 |
|---|---|---|---|---|
| [109848](https://akizukidenshi.com/catalog/g/g109848/) | DRV8835使用ステッピング&DCモータードライバーモジュール | 2セット | ¥550/セット | Hブリッジ送信（M0で1枚使用） |
| [116187](https://akizukidenshi.com/catalog/g/g116187/) | 2回路入レールtoレールCMOSオペアンプ MCP6022-I/P | 2個 | ¥220/個 | 受信増幅+Vmidバッファ |
| [109485](https://akizukidenshi.com/catalog/g/g109485/) | 10bit 8ch ADコンバーター MCP3008-I/P | 1個 | ¥360/個 | 受信波形サンプリング |
| [113907](https://akizukidenshi.com/catalog/g/g113907/) | ショットキーバリアダイオード 30V200mA BAT43 | 10本入 | ¥150/パック | 入力保護クランプ |

### コンデンサ（共振C候補・C0G）

| 秋月コード | 商品名 | 数量 | 単価 | 用途 |
|---|---|---|---|---|
| [108125](https://akizukidenshi.com/catalog/g/g108125/) | 積層セラミックコンデンサー 8200pF50V C0G 5mm | 10個入 | ¥170/パック | 共振C候補 |
| [108124](https://akizukidenshi.com/catalog/g/g108124/) | 積層セラミックコンデンサー 6800pF50V C0G 5mm | 10個入 | ¥170/パック | 共振C候補 |
| [108116](https://akizukidenshi.com/catalog/g/g108116/) | 積層セラミックコンデンサー 1500pF50V C0G 5mm | 10個入 | ¥130/パック | 共振C調整 |
| [108111](https://akizukidenshi.com/catalog/g/g108111/) | 積層セラミックコンデンサー 560pF50V C0G 5mm | 10個入 | ¥100/パック | 共振C調整 |
| [108045](https://akizukidenshi.com/catalog/g/g108045/) | 積層セラミックコンデンサー 47pF50V C0G 5mm | 10個入 | ¥130/パック | 発振防止 |

### コンデンサ（デカップリング）

| 秋月コード | 商品名 | 数量 | 単価 | 用途 |
|---|---|---|---|---|
| [117059](https://akizukidenshi.com/catalog/g/g117059/) | 積層セラミックコンデンサー 0.1µF50V C0G 5mm | 10個入 | ¥250/パック | デカップリング |
| [108043](https://akizukidenshi.com/catalog/g/g108043/) | 積層セラミックコンデンサー 0.01µF50V C0G 5mm | 10個入 | ¥200/パック | デカップリング |
| [105002](https://akizukidenshi.com/catalog/g/g105002/) | アルミ電解コンデンサー100µF16V105℃ ルビコンMH5 | 4個 | ¥20/個 | バルクデカップリング |

### 抵抗

| 秋月コード | 商品名 | 数量 | 単価 | 用途 |
|---|---|---|---|---|
| [116876](https://akizukidenshi.com/catalog/g/g116876/) | 金属皮膜抵抗 1/4W 1kΩ ±0.1% | 10本入 | ¥200/パック | Rg（ゲイン設定） |
| [116877](https://akizukidenshi.com/catalog/g/g116877/) | 金属皮膜抵抗 1/4W 10kΩ ±0.1% | 10本入 | ¥400/パック | Rf, Vmid分圧 |

### その他

| 秋月コード | 商品名 | 数量 | 単価 | 用途 |
|---|---|---|---|---|
| [100167](https://akizukidenshi.com/catalog/g/g100167/) | ピンヘッダー 1×40 (40P) | 2個 | ¥35/個 | 接続用 |
| [100167](https://akizukidenshi.com/catalog/g/g100167/) | ピンヘッダー 1×40 (40P) | 1個 | ¥35/個 | テストボード用（1×4を8本切り出し、2枚のテストボード×4本） |
| [100284](https://akizukidenshi.com/catalog/g/g100284/) | ブレッドボード EIC-106J | 1枚 | ¥2,100/枚 | プロトタイピング |

---

## M0 PoCでの使用数

| 部品 | 在庫 | M0使用 | 残り | 備考 |
|---|---|---|---|---|
| XIAO ESP32C3 | **2** | 1 | 1 | M0では1台で送受信兼用も可、残りはM1以降用 |
| 3D11-722J | **5** | 2 | 3 | 送信×1、受信×1。残りはM1/M1.5用 |
| DRV8835モジュール | 2 | 1 | 1 | M1で残りを使用 |
| MCP6022 | 2 | 1 | 1 | 2ch使用（Vmid+アンプ） |
| MCP3008 | 1 | 1 | 0 | 1ch使用 |
| 10kΩ | 10 | 3 | 7 | Vmid分圧2本+Rf1本 |
| 1kΩ | 10 | 1 | 9 | Rg1本 |
| 0.1µF | 10 | 4 | 6 | 各IC+Vmid平滑 |
| 100µF | 4 | 1 | 3 | DRV8835バルク |
| 47pF | 10 | 1 | 9 | 発振防止 |
| BAT43 | 10 | 2 | 8 | 入力保護 |
| 共振C | 各10 | 1〜2 | 多数 | 最適値探索 |

---

## 共振C組み合わせ候補

3D11-722J（L ≈ 7.2mH）の場合:

| 組み合わせ | 合計容量 | 共振周波数（理論） | 備考 |
|---|---|---|---|
| 8200pF単体 | 8200pF | 20.6kHz | |
| 8200+560pF | 8760pF | 20.0kHz | ★ 理論最適 |
| 8200+1500pF | 9700pF | 19.0kHz | |
| 6800pF単体 | 6800pF | 22.9kHz | |
| 6800+560pF | 7360pF | 22.0kHz | |
| 6800+1500pF | 8300pF | 20.5kHz | |

※ 実測で受信振幅が最大になる組み合わせを採用

---

## XIAO ESP32C3 GPIO割り当て

| 機能 | ピン | GPIO | 備考 |
|---|---|---|---|
| PWM_X | D0 | GPIO2 | 送信PWM |
| PWM_X_INV | D1 | GPIO3 | 反転PWM（または GND固定） |
| SPI_SCK | D8 | GPIO8 | MCP3008 CLK |
| SPI_MISO | D9 | GPIO9 | MCP3008 DOUT |
| SPI_MOSI | D10 | GPIO10 | MCP3008 DIN |
| SPI_CS | D7 | GPIO20 | MCP3008 CS |
| 5V | 5V | - | DRV8835 VM |
| 3.3V | 3V3 | - | アナログ回路電源 |
| GND | GND | - | 共通GND |

---

## 秋月商品リンク

- [DRV8835モジュール (109848)](https://akizukidenshi.com/catalog/g/g109848/)
- [MCP6022-I/P (116187)](https://akizukidenshi.com/catalog/g/g116187/)
- [MCP3008-I/P (109485)](https://akizukidenshi.com/catalog/g/g109485/)
- [BAT43 (113907)](https://akizukidenshi.com/catalog/g/g113907/)
- [ブレッドボード EIC-106J (100284)](https://akizukidenshi.com/catalog/g/g100284/)

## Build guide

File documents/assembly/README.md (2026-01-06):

# 組み立てガイド

## フォルダ構成

```
assembly/
├── README.md          # このファイル
├── m0_poc/           # M0: 1軸ディスクリートPoC
│   ├── README.md
│   ├── 01_power_vmid.md
│   ├── 02_rx_amplifier.md
│   ├── 03_adc.md
│   ├── 04_tx_driver.md
│   ├── 05_integration.md
│   └── troubleshooting.md
└── m1_3axis/         # M1: 3軸TDM
```

## 各フェーズの組み立てガイド

| フェーズ | ガイド |
|---|---|
| M0 | [m0_poc/README.md](m0_poc/README.md) |
| M1 | TBD |

## 組み立て順序（共通）

```
[1] 電源 & Vmid
      ↓ 動作確認
[2] 受信アンプ
      ↓ 動作確認
[3] ADC
      ↓ 動作確認
[4] 送信回路
      ↓ 動作確認
[5] 全体結合 & 調整
```

## 必要な工具

| 工具 | 用途 | 必須度 |
|---|---|---|
| テスター（マルチメータ） | 電圧確認、導通チェック | ★★★ |
| ブレッドボード | 部品配置 | ★★★ |
| ジャンパワイヤ | 配線 | ★★★ |
| ニッパー | リード線カット | ★★☆ |
| ピンセット | 小さい部品 | ★☆☆ |
| オシロスコープ | 波形確認 | ★☆☆ |

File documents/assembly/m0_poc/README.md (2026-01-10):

# M0 PoC 組み立てガイド

## はじめに

このガイドは、電子回路初心者の方がM0 PoC（1軸ディスクリート）を組み立てられるよう、**モジュール単位**で段階的に説明します。

## 使用部品

| 部品 | 型番 | 入手先 |
|---|---|---|
| MCU | XIAO ESP32C3 | [AliExpress](https://ja.aliexpress.com/item/1005006114576182.html) |
| 3軸コイル | 3D11-722J | [AliExpress](https://ja.aliexpress.com/item/1005004723068527.html) |
| **3D11-722Jテストボード** | **自作基板** | [KiCad設計ファイル](../../../kicad/3D11_test_Board/) |
| モータドライバ | DRV8835モジュール | 秋月電子 ([109848](https://akizukidenshi.com/catalog/g/g109848/)) |
| オペアンプ | MCP6022-I/P | 秋月電子 ([116187](https://akizukidenshi.com/catalog/g/g116187/)) |
| ADC | MCP3008-I/P | 秋月電子 ([109485](https://akizukidenshi.com/catalog/g/g109485/)) |

## 3D11-722Jテストボードについて

3D11-722Jは**SMD部品**のため、ブレッドボード（2.54mmピッチ）で直接使用できません。
そのため、KiCadで設計した**テストボード**を作成し、2.54mmピッチのピンヘッダーに変換します。

### テストボードの入手方法

| バージョン | 説明 | KiCadファイル | 3Dレンダリング |
|---|---|---|---|
| **単体版** | 1枚の基板（プロトタイプ用） | [3D11_test_Board](../../../kicad/3D11_test_Board/) | [3D11_test_Board.png](../../../kicad/3D11_test_Board/3D11_test_Board.png) |
| **パネル版** | 10枚を1パネルに（量産用） | [3D11_production](../../../kicad/3D11_production/) | [3d11_testboard_batch.png](../../../kicad/3D11_production/3d11_testboard_batch.png) |

💡 **基板発注について:**
- 単体版: プロトタイプや少量製作に適しています
- パネル版: 10枚まとめて発注する場合に使用します。到着後、パネルから個別基板を切り離して使用します
- 基板発注は、KiCadから生成したGerberファイル（`garber.zip`）を使用します

### テストボードのピン配置

```
        ┌─────────────┐
        │  3D11-722J  │
        │  Test Board │
        │             │
  Y- ───┤●            │
  Y+ ───┤●            │
  X- ───┤●            │
  X+ ───┤●            │
        │             │
        │    [UP]     │
        │             │
  X+ ───┤●            │
  X- ───┤●            │
  Z+ ───┤●            │
  Z- ───┤●            │
        └─────────────┘

上部: Y-, Y+, X-, X+  (Y軸とX軸)
下部: X+, X-, Z+, Z-  (X軸とZ軸)
```

💡 **注意:** 上部と下部の両方にX軸端子があります。どちらを使ってもOKです。

### テストボードの組み立て

**必要な部品:**
- 3D11-722Jコイル × 1個（1枚の基板あたり）
- ピンヘッダー 1×4（2.54mmピッチ）× 2本（上部・下部用）

**組み立て手順:**

1. **パネル版の場合:** パネルから個別基板を切り離す（ニッパーやカッターで切り離し）
2. **3D11-722Jを基板に実装**
   - 基板の中央に3D11-722Jを配置
   - 向きを確認（基板の"UP"マークに合わせる）
   - SMDはんだ付けを実施
3. **ピンヘッダーを基板に挿入**
   - 上部: 1×4ピンヘッダー（Y-, Y+, X-, X+）
   - 下部: 1×4ピンヘッダー（X+, X-, Z+, Z-）
   - 2.54mmピッチでブレッドボードに挿入可能
4. **動作確認**
   - テスターで各ピン間の導通を確認
   - ショートがないことを確認

詳細は [04_tx_driver.md](04_tx_driver.md) と [05_integration.md](05_integration.md) を参照。

## 組み立て順序（推奨）

各モジュールを**順番に組み立て、動作確認してから次へ進む**ことで、問題が発生しても原因を特定しやすくなります。

```
[0] 3D11-722Jテストボード組み立て（事前準備）
      ↓
[1] 電源 & Vmid
      ↓ 動作確認
[2] 受信アンプ
      ↓ 動作確認
[3] ADC (MCP3008)
      ↓ 動作確認
[4] 送信回路 (DRV8835)
      ↓ 動作確認
[5] 全体結合 & 調整
```

## ドキュメント一覧

| ファイル | 内容 |
|---|---|
| [01_power_vmid.md](01_power_vmid.md) | 電源配線とVmid（仮想GND）生成 |
| [02_rx_amplifier.md](02_rx_amplifier.md) | 受信アンプ（MCP6022） |
| [03_adc.md](03_adc.md) | ADC（MCP3008）の接続 |
| [04_tx_driver.md](04_tx_driver.md) | 送信ドライバ（DRV8835） |
| [05_integration.md](05_integration.md) | 全体結合と動作確認 |
| [troubleshooting.md](troubleshooting.md) | よくある問題と対策 |

## XIAO ESP32C3 ピンアウト

```
        ┌─────────────────┐
        │   XIAO ESP32C3  │
        │                 │
   D0 ──┤ GPIO2    5V    ├── 5V出力
   D1 ──┤ GPIO3    GND   ├── GND
   D2 ──┤ GPIO4    3V3   ├── 3.3V出力
   D3 ──┤ GPIO5    GPIO10├── D10 (MOSI)
   D4 ──┤ GPIO6    GPIO9 ├── D9  (MISO)
   D5 ──┤ GPIO7    GPIO8 ├── D8  (SCK)
   D6 ──┤ GPIO21   GPIO20├── D7  (RX)
        └─────────────────┘

左側: D0-D6 (GPIO2,3,4,5,6,7,21)
右側: 5V, GND, 3V3, D10-D7 (GPIO10,9,8,20)
```

💡 **注意:** D3 (GPIO5/A3) はADC2を使用します。ADC2はWiFi使用時に動作しない可能性があるため、アナログ読み取りにはADC1（D0-D2）を使用することを推奨します。

## M0での GPIO割り当て

| 機能 | ピン | GPIO | 備考 |
|---|---|---|---|
| PWM_X | D0 | GPIO2 | 送信PWM |
| PWM_X_INV | D1 | GPIO3 | 反転PWM（またはGND固定） |
| SPI_SCK | D8 | GPIO8 | MCP3008 CLK |
| SPI_MISO | D9 | GPIO9 | MCP3008 DOUT |
| SPI_MOSI | D10 | GPIO10 | MCP3008 DIN |
| SPI_CS | D7 | GPIO20 | MCP3008 CS |

## 必要な工具

| 工具 | 用途 | 必須度 |
|---|---|---|
| テスター（マルチメータ） | 電圧確認、導通チェック | ★★★ 必須 |
| ブレッドボード | 部品配置 | ★★★ 必須 |
| ジャンパワイヤ | 配線 | ★★★ 必須 |
| はんだごて | テストボード組み立て | ★★★ 必須 |
| はんだ | SMD部品実装 | ★★★ 必須 |
| ニッパー | 部品のリード線カット | ★★☆ |
| ラジオペンチ | 部品の取り扱い | ★★☆ |
| ピンセット | 小さい部品の取り扱い | ★☆☆ |
| オシロスコープ | 波形確認（なくてもOK） | ★☆☆ |

## 安全上の注意

⚠️ **電源投入前に必ず確認:**
- 電源（3.3V, 5V）とGNDがショートしていないこと
- ICの向きが正しいこと
- 電解コンデンサの極性が正しいこと
- テストボードのピン配置が正しいこと

⚠️ **作業中の注意:**
- 静電気に注意（ICを触る前に金属に触れる）
- 電源を入れたままの配線変更は避ける
- 異常な発熱・異臭があれば即座に電源を切る
- はんだ作業時は換気を十分に

## 記号の説明

このガイドで使用する記号:

| 記号 | 意味 |
|---|---|
| ✅ | 完了した手順 |
| ⚠️ | 注意事項 |
| 💡 | ヒント・コツ |
| 🔧 | 調整が必要な箇所 |
| ❌ | やってはいけないこと |

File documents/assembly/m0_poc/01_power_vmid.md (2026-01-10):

# モジュール1: 電源 & Vmid生成

## 概要

このモジュールでは:
1. ブレッドボードの電源レールに3.3Vと5Vを配線
2. Vmid（仮想GND = 1.65V）を生成

## なぜVmidが必要？

単電源（0V〜3.3V）で交流信号を扱うため、**中点電圧（1.65V）**を基準にします。
これにより、正負の振動を持つ信号を0V〜3.3Vの範囲で表現できます。

```
3.3V ─────────────────
       ↑
       │  正の振動
1.65V ─│───────────────  ← Vmid（仮想GND）
       │  負の振動
       ↓
  0V ─────────────────
```

---

## 必要な部品

| 部品 | 秋月コード | 数量 | 用途 |
|---|---|---|---|
| 抵抗 10kΩ 0.1% | 116877 | 2 | Vmid分圧 |
| セラミックC 0.1µF | 117059 | 2 | デカップリング、平滑 |
| 電解C 100µF | 105002 | 1 | バルクデカップリング（オプション） |

---

## 手順

### Step 1: ブレッドボードの準備

ブレッドボードには通常、上下に**電源レール**（赤い線と青い線）があります。

```
+─────────────────────────────────────────────+
│ ● ● ● ● ● ● ● ● ● ● ● ● ● ● ● ● │ ← 赤レール（+）
│ ● ● ● ● ● ● ● ● ● ● ● ● ● ● ● ● │ ← 青レール（GND）
├─────────────────────────────────────────────┤
│                                             │
│   メイン配線エリア（5穴×N列）               │
│                                             │
├─────────────────────────────────────────────┤
│ ● ● ● ● ● ● ● ● ● ● ● ● ● ● ● ● │ ← 赤レール（+）
│ ● ● ● ● ● ● ● ● ● ● ● ● ● ● ● ● │ ← 青レール（GND）
+─────────────────────────────────────────────+
```

💡 **ヒント:** 上側を3.3V系、下側を5V系として使い分けると整理しやすいです。

### Step 2: XIAO ESP32C3から電源を取り出す

XIAO ESP32C3をブレッドボードに挿し、以下を電源レールに接続:

```
XIAO ESP32C3 ピン配置:
        ┌─────────────────┐
        │  ● USB-C ●     │
        │                 │
   D0 ──┤ ●           ● ├── 5V   → 下側赤レールへ
   D1 ──┤ ●           ● ├── GND  → 青レールへ
   D2 ──┤ ●           ● ├── 3V3  → 上側赤レールへ
   D3 ──┤ ●           ● ├── D10  → SPI MOSI
   D4 ──┤ ●           ● ├── D9   → SPI MISO
   D5 ──┤ ●           ● ├── D8   → SPI SCK
   D6 ──┤ ●           ● ├── D7   → SPI CS
        └─────────────────┘

左側: D0-D6 (GPIO2,3,4,5,6,7,21)
右側: 5V, GND, 3V3, D10-D7 (GPIO10,9,8,20)
```

| XIAOピン | 接続先 | 備考 |
|---|---|---|
| 3V3（3.3V出力） | 上側赤レール | アナログ回路用 |
| 5V（USB電源） | 下側赤レール | DRV8835用 |
| GND | 青レール（両方） | 共通GND |

⚠️ **注意:** 上下の青レール（GND）同士を**ジャンパで接続**してください。

### Step 3: Vmid分圧回路の作成

```
3.3V ──[10kΩ]──┬──[10kΩ]── GND
               │
               └── Vmid_raw（約1.65V）
```

**配線手順:**

1. 3.3Vレールから、10kΩ抵抗の片足を接続
2. その10kΩのもう片足を、空いている列（例: 列10）に挿す
3. 同じ列10に、もう1本の10kΩの片足を挿す
4. その10kΩのもう片足をGNDレールに接続

**確認:** テスターで列10とGND間の電圧を測定 → **約1.65V** になればOK

### Step 4: Vmid平滑コンデンサの追加

```
Vmid_raw ──┬── 0.1µF ── GND
           │
           └── Vmid_raw（安定化）
```

**配線手順:**

1. 列10（Vmid_raw）に0.1µFの片足を挿す
2. もう片足をGNDレールに接続

💡 **なぜ平滑が必要？** 分圧抵抗だけだと、ノイズで電圧が揺れます。コンデンサで高周波ノイズを吸収します。

### Step 5: 3.3V側デカップリングコンデンサ

XIAO ESP32C3の3.3V出力近くに0.1µFを追加:

1. 3.3Vレールに0.1µFの片足を接続
2. もう片足をGNDレールに接続

💡 **目的:** 電源のノイズを低減し、アナログ回路の動作を安定させます。

---

## 動作確認

### チェックリスト

電源を入れて、テスターで以下を確認:

| 測定点 | 期待値 | 許容範囲 | チェック |
|---|---|---|---|
| 3.3Vレール - GND | 3.3V | 3.2〜3.4V | ☐ |
| 5Vレール - GND | 5.0V | 4.8〜5.2V | ☐ |
| Vmid_raw - GND | 1.65V | 1.6〜1.7V | ☐ |

### トラブルシューティング

| 症状 | 原因 | 対策 |
|---|---|---|
| 3.3Vが出ない | XIAO ESP32C3が起動していない | USBケーブル確認、LEDの点灯確認 |
| Vmidが1.65Vにならない | 抵抗値の間違い | 抵抗を確認（テスターで測定） |
| Vmidが不安定 | 平滑Cがない、または接続不良 | 0.1µFの接続を確認 |

---

## 完成図

```
          3.3V
           │
         [10kΩ]
           │
    ┌──────┼──────┐
    │      │      │
  [0.1µF]  │    Vmid_raw ──→ 次のモジュールへ
    │      │      │
    GND  [10kΩ]   │
           │      │
          GND     │
                  │
                 GND
```

---

## 次のステップ

✅ 電源とVmidの確認が完了したら、[02_rx_amplifier.md](02_rx_amplifier.md) へ進みます。

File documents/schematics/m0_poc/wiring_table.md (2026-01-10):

# M0 PoC 配線接続表

## 使用機材

| 部品 | 型番 | 入手先 | データシート |
|---|---|---|---|
| MCU | XIAO ESP32C3 | [AliExpress](https://ja.aliexpress.com/item/1005006114576182.html) | [Wiki](https://wiki.seeedstudio.com/XIAO_ESP32C3_Getting_Started/) |
| 3軸コイル | 3D11-722J | [AliExpress](https://ja.aliexpress.com/item/1005004723068527.html) | [PDF](https://ru.shinhom.com/Content/upload/pdf/202339189/3D11-Series.pdf) |
| モータドライバ | DRV8835モジュール (AE-DRV8835-S) | 秋月電子 (109848) | [PDF](https://akizukidenshi.com/goodsaffix/AE-DRV8835-S_20210526.pdf) |
| オペアンプ | MCP6022-I/P | 秋月電子 (116187) | |
| ADC | MCP3008-I/P | 秋月電子 (109485) | |

---

## XIAO ESP32C3 ピンアウト

```
        ┌─────────────────┐
        │   XIAO ESP32C3  │
        │                 │
   D0 ──┤ GPIO2    5V    ├── 5V出力
   D1 ──┤ GPIO3    GND   ├── GND
   D2 ──┤ GPIO4    3V3   ├── 3.3V出力
   D3 ──┤ GPIO5    GPIO10├── D10 (MOSI)
   D4 ──┤ GPIO6    GPIO9 ├── D9  (MISO)
   D5 ──┤ GPIO7    GPIO8 ├── D8  (SCK)
   D6 ──┤ GPIO21   GPIO20├── D7  (RX/CS)
        └─────────────────┘

左側: D0-D6 (GPIO2,3,4,5,6,7,21)
右側: 5V, GND, 3V3, D10-D7 (GPIO10,9,8,20)
```

---

## DRV8835モジュール (AE-DRV8835-S) ピンアウト

[データシート](https://akizukidenshi.com/goodsaffix/AE-DRV8835-S_20210526.pdf)より:

```
ピン番号は基板左上を起点に反時計回り

        ┌────────────────┐
   VM ─1┤●            ●├12─ VCC
AOUT1 ─2┤●            ●├11─ MODE
AOUT2 ─3┤●            ●├10─ AIN1
BOUT1 ─4┤●            ●├9── AIN2
BOUT2 ─5┤●            ●├8── BIN1
  GND ─6┤●            ●├7── BIN2
        └────────────────┘
```

| ピン | 名称 | 機能 |
|---|---|---|
| 1 | VM | モータ電源 (0〜11V) |
| 2 | AOUT1 | A出力1 |
| 3 | AOUT2 | A出力2 |
| 4 | BOUT1 | B出力1 |
| 5 | BOUT2 | B出力2 |
| 6 | GND | グランド |
| 7 | BIN2 | B入力2 |
| 8 | BIN1 | B入力1 |
| 9 | AIN2 | A入力2 |
| 10 | AIN1 | A入力1 |
| 11 | MODE | モード設定 (0=IN/IN, 1=PHASE/ENABLE) |
| 12 | VCC | ロジック電源 (2〜7V) |

### IN/INモード (MODE = 0 = GND接続)

| xIN1 | xIN2 | xOUT1 | xOUT2 | 動作 |
|---|---|---|---|---|
| 0 | 0 | HiZ | HiZ | 空転 |
| 0 | 1 | L | H | 逆転 |
| 1 | 0 | H | L | 正転 |
| 1 | 1 | L | L | ブレーキ |

---

## 3D11-722J コイル スペック

[データシート](https://ru.shinhom.com/Content/upload/pdf/202339189/3D11-Series.pdf)より:

| 項目 | 値 |
|---|-----|
| サイズ | 11.8 × 11.8 × 2.9 mm |
| インダクタンス (L) | 7.20 mH（各軸） |
| Q値 | 30 |
| 自己共振周波数 (SRF) | 330 kHz (X,Y), 700 kHz (Z) |
| DC抵抗 | 150Ω (X,Y), 210Ω (Z) |

---

## 電源系統

| 信号名 | 電圧 | 接続元 | 接続先 | 備考 |
|---|---|---|---|---|
| 5V | 5V | XIAO 5V | DRV8835 VM (ピン1) | 送信電源 |
| 3.3V | 3.3V | XIAO 3V3 | MCP6022 VDD, MCP3008 VDD, Vmid分圧 | アナログ電源 |
| GND | 0V | XIAO GND | 全モジュール | 一点接続推奨 |

---

## Beacon（送信）接続

### XIAO ESP32C3 → DRV8835

| 信号名 | XIAO ピン | GPIO | DRV8835ピン | 備考 |
|---|---|---|---|---|
| PWM_X | D0 | GPIO2 | ピン10 (AIN1) | 20kHz PWM |
| PWM_X_INV | D1 | GPIO3 | ピン9 (AIN2) | 反転PWM（または GND固定） |
| - | - | - | ピン11 (MODE) | GNDへ接続（IN/INモード） |

### DRV8835 電源

| ピン | 接続先 | 備考 |
|---|---|---|
| ピン1 (VM) | 5V | モータ電源 |
| ピン12 (VCC) | 3.3V | ロジック電源 |
| ピン6 (GND) | GND | |
| ピン11 (MODE) | GND | IN/INモード |

### DRV8835 → 送信コイル（3D11-722J #1）

| DRV8835ピン | 接続先 | 備考 |
|---|---|---|
| ピン2 (AOUT1) | 3D11-722J X軸端子1 | コイル端子A |
| ピン3 (AOUT2) | 3D11-722J X軸端子2 | コイル端子B |

### 共振C

| 部品 | 接続 | 備考 |
|---|---|---|
| 8760pF (8200+560) | AOUT1-AOUT2間に並列 | 初期値、要調整 |

### DRV8835 デカップリング

| 部品 | 接続 | 備考 |
|---|---|---|
| 0.1µF | VM(ピン1)-GND | IC近傍 |
| 100µF電解 | 5V-GND | バルク |

---

## Tracker（受信）接続

### Vmid生成

| 部品/信号 | 接続 | 備考 |
|---|---|---|
| 10kΩ #1 | 3.3V → Vmid_raw | 分圧上側 |
| 10kΩ #2 | Vmid_raw → GND | 分圧下側 |
| 0.1µF | Vmid_raw → GND | 平滑 |
| MCP6022 ch1 (+) | Vmid_raw | 電圧フォロワ入力 |
| MCP6022 ch1 (-) | Vmid_out | フィードバック |
| MCP6022 ch1 out | Vmid_out | バッファ後の安定Vmid |

### 受信コイル（3D11-722J #2）→ MCP6022

| コイル端子 | 接続先 | 備考 |
|---|---|---|
| X軸端子1 | Vmid_out | コイル基準 |
| X軸端子2 | MCP6022 ch2 (+IN B) | 信号入力 |

### 受信アンプ（MCP6022 ch2）

| 部品/信号 | 接続 | 備考 |
|---|---|---|
| 10kΩ (Rf) | MCP6022 ch2 out → (-IN B) | フィードバック抵抗 |
| 1kΩ (Rg) | MCP6022 ch2 (-IN B) → Vmid_out | ゲイン設定抵抗 |
| 47pF | Rfに並列 | 発振防止 |
| MCP6022 ch2 out | ADC入力へ | 増幅後信号 |

### MCP6022 電源

| ピン | 接続 | 備考 |
|---|---|---|
| VDD (ピン8) | 3.3V | |
| VSS (ピン4) | GND | |
| 0.1µF | VDD-GND | IC近傍 |

### 入力保護（BAT43）

| 部品 | 接続 | 備考 |
|---|---|---|
| BAT43 #1 | ADC入力 → 3.3V (カソード→アノード) | 上側クランプ |
| BAT43 #2 | GND → ADC入力 (カソード→アノード) | 下側クランプ |

### MCP3008 ADC → XIAO ESP32C3

| MCP3008ピン | 接続先 | XIAO | 備考 |
|---|---|---|---|
| VDD (ピン16) | 3.3V | - | |
| VREF (ピン15) | 3.3V | - | |
| AGND (ピン14) | GND | - | |
| DGND (ピン9) | GND | - | |
| CLK (ピン13) | D8 | GPIO8 | SPI CLK |
| DOUT (ピン12) | D9 | GPIO9 | SPI MISO |
| DIN (ピン11) | D10 | GPIO10 | SPI MOSI |
| CS (ピン10) | D7 | GPIO20 | SPI CS |
| CH0 (ピン1) | アンプ出力 | - | 受信信号 |
| CH1-CH7 | 未接続 | - | 将来3軸用 |

### MCP3008 デカップリング

| 部品 | 接続 | 備考 |
|---|---|---|
| 0.1µF | VDD-DGND | IC近傍 |
| 0.1µF | VREF-AGND | IC近傍 |

---

## ブレッドボード配置ガイド

```
【推奨配置】

┌──────────────────────────────────────────────────────────────────┐
│                        ブレッドボード EIC-106J                   │
├──────────────────────────────────────────────────────────────────┤
│                                                                  │
│  [送信エリア]              [   間隔   ]       [受信エリア]       │
│                                                                  │
│  ┌─────────┐                              ┌─────────────────┐   │
│  │DRV8835  │                              │MCP6022          │   │
│  │(109848) │           5cm以上            │(Vmid+アンプ)    │   │
│  │         │           離す               │                 │   │
│  │3D11-722J│                              │MCP3008          │   │
│  │ #1(送信)│                              │(ADC)            │   │
│  │ + 共振C │                              │                 │   │
│  └─────────┘                              │BAT43 (保護)     │   │
│                                            │                 │   │
│                                            │3D11-722J        │   │
│                                            │ #2(受信)        │   │
│                                            └─────────────────┘   │
│                                                                  │
│  ┌─────────────────────────────────────────────────────────────┐│
│  │                    XIAO ESP32C3                              ││
│  │  (中央付近に配置、両側へアクセスしやすく)                    ││
│  └─────────────────────────────────────────────────────────────┘│
│                                                                  │
└──────────────────────────────────────────────────────────────────┘

【GND接続】
- 受信側でGNDを合流させる（一点接続）
- 送信側のGNDは細いジャンパで受信側GNDへ
```

---

## 配線チェックリスト

### 電源投入前の確認

- [ ] 3.3VとGNDがショートしていないこと（テスタで確認）
- [ ] 5VとGNDがショートしていないこと
- [ ] DRV8835のVM (ピン1) が5Vに接続されていること
- [ ] DRV8835のVCC (ピン12) が3.3Vに接続されていること
- [ ] DRV8835のMODE (ピン11) がGNDに接続されていること
- [ ] MCP6022, MCP3008のVDDが3.3Vに接続されていること
- [ ] 全てのGNDが接続されていること
- [ ] ICの向きが正しいこと（ピン1マーク確認）

### 電源投入後の確認

- [ ] XIAO ESP32C3が正常起動すること（LED点灯）
- [ ] DRV8835が過熱していないこと（触って確認）
- [ ] MCP6022 Vmid出力が約1.65Vであること
- [ ] MCP3008がSPIで応答すること

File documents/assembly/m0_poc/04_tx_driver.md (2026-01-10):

# モジュール4: 送信ドライバ（DRV8835）

## 概要

このモジュールでは:
1. DRV8835モジュールをブレッドボードに配置
2. XIAO ESP32C3からのPWM信号で駆動
3. 送信コイル（3D11-722J）と共振コンデンサを接続

---

## DRV8835モジュールについて

DRV8835は**デュアルHブリッジモータドライバ**です。
通常はモーター制御に使いますが、ここでは**交流電流を生成してコイルを駆動**します。

### 秋月モジュール（109848）のピン配置

```
┌─────────────────────────────┐
│  DRV8835モジュール (109848) │
│                             │
│  VM  ─ モータ電源（5V）     │
│  VCC ─ ロジック電源（3.3V） │
│  GND ─ グランド             │
│                             │
│  AIN1 ─ A側入力1            │
│  AIN2 ─ A側入力2            │
│  AOUT1 ─ A側出力1           │
│  AOUT2 ─ A側出力2           │
│                             │
│  BIN1 ─ B側入力1            │
│  BIN2 ─ B側入力2            │
│  BOUT1 ─ B側出力1           │
│  BOUT2 ─ B側出力2           │
│                             │
│  MODE ─ モード選択          │
└─────────────────────────────┘
```

⚠️ **注意:** モジュールの実際のシルク印刷を確認してください。

---

## 3D11-722Jコイルについて

AliExpressで入手した3軸コイル:
- 型番: 3D11-722J
- 構造: 3軸直交コイル内蔵
- インダクタンス: 各軸約7.2mH（722 = 72 × 10² = 7200µH = 7.2mH）
- リンク: [AliExpress](https://ja.aliexpress.com/item/1005004723068527.html)

**M0では1軸のみ使用します。**

---

## 必要な部品

| 部品 | 秋月コード | 数量 | 用途 |
|---|---|---|---|
| DRV8835モジュール | 109848 | 1 | Hブリッジ |
| コンデンサ 0.1µF | 117059 | 1 | 電源デカップリング |
| 電解コンデンサ 100µF | 105002 | 1 | バルクデカップリング |
| 3D11-722J | - | 1 | 送信コイル（1軸使用、SMD） |
| 3D11-722Jテストボード | 自作基板 | 1 | SMD→2.54mm変換基板 |
| ピンヘッダー 1×4（2.54mm） | 100167等 | 2 | テストボード用（上部・下部） |
| 共振コンデンサ | 108125等 | 1セット | 波形整形 |

---

## 手順

### Step 1: モジュールの配置

⚠️ **重要:** DRV8835は**受信回路から離して配置**してください（5cm以上推奨）。

送信系のスイッチングノイズが受信系に影響するのを防ぎます。

```
ブレッドボード配置例:

[受信側エリア]              [送信側エリア]
MCP6022, MCP3008           DRV8835, コイル
     ↑                          ↑
     └─────── 5cm以上 ──────────┘
```

### Step 2: 電源接続

| ピン | 接続先 | 備考 |
|---|---|---|
| VM | 5Vレール | モータ電源（送信電力） |
| VCC | 3.3Vレール | ロジック電圧（XIAO ESP32C3に合わせる） |
| GND | GNDレール | |
| MODE | 3.3Vレール | Hiで IN/IN モード |

### Step 3: デカップリングコンデンサ

**VM近傍に:**

1. 0.1µF: VM-GND間
2. 100µF電解: VM-GND間

⚠️ **電解コンデンサの極性に注意!** 長い足が+（プラス）側です。

### Step 4: XIAO ESP32C3からPWM信号接続

**±駆動モード（推奨）:**

| DRV8835ピン | XIAOピン | GPIO | 説明 |
|---|---|---|---|
| AIN1 | D0 | GPIO2 | 20kHz PWM |
| AIN2 | D1 | GPIO3 | 反転PWM |

**片側駆動モード（簡易）:**

| DRV8835ピン | 接続先 | 説明 |
|---|---|---|
| AIN1 | XIAO D0 (GPIO2) | 20kHz PWM |
| AIN2 | GND | 固定Low |

💡 **最初は片側駆動で試して**、動作確認後に±駆動に変更するのが安全です。

### Step 5: コイル接続（3D11-722Jテストボード）

3D11-722Jは**SMD部品**のため、直接ブレッドボードに挿入できません。
**テストボード**を使用して2.54mmピッチのピンヘッダーに変換します。

**テストボードのピン配置:**

```
        ┌─────────────┐
        │  3D11-722J  │
        │  Test Board │
        │             │
  Y- ───┤●            │
  Y+ ───┤●            │
  X- ───┤●            │
  X+ ───┤●            │
        │             │
        │    [UP]     │
        │             │
  X+ ───┤●            │
  X- ───┤●            │
  Z+ ───┤●            │
  Z- ───┤●            │
        └─────────────┘

上部: Y-, Y+, X-, X+  (Y軸とX軸)
下部: X+, X-, Z+, Z-  (X軸とZ軸)
```

**M0での接続（送信側）:**

3D11-722Jは3軸コイルですが、M0では**X軸のみ**使用します。
上部または下部のX軸端子を使用できます。

| DRV8835ピン | テストボード端子 | 備考 |
|---|---|---|
| AOUT1 | X+（上部または下部） | X軸プラス |
| AOUT2 | X-（上部または下部） | X軸マイナス |

💡 **テストボードの組み立て:**
- 詳細は [README.md](README.md) の「3D11-722Jテストボードについて」を参照
- 基板発注は [KiCadファイル](../../../kicad/3D11_test_Board/) からGerberファイルを生成

⚠️ **注意:** テストボードの向きを確認してください（"UP"マークが上向き）。

### Step 6: 共振コンデンサ

コイルと**並列**に共振Cを接続:

```
AOUT1 ──┬────[コイル L]────┬── AOUT2
        │                  │
        └────[共振C]───────┘
```

**3D11-722J（L ≈ 7.2mH）の場合:**

20kHz共振に必要なC:
```
f = 1 / (2π√(LC))
C = 1 / (4π²f²L)
C = 1 / (4 × 3.14² × 20000² × 0.0072)
C ≈ 8800pF
```

**最初は8200pF + 560pF = 8760pFから試してください。**

---

## XIAO ESP32C3 PWM生成コード

```cpp
// XIAO ESP32C3 PWM生成
#include <Arduino.h>

const int PWM_PIN = 2;       // D0 = GPIO2
const int PWM_INV_PIN = 3;   // D1 = GPIO3（±駆動時）
const int PWM_FREQ = 20000;  // 20kHz
const int PWM_RESOLUTION = 8; // 8bit (0-255)

// LEDC チャンネル
const int PWM_CHANNEL = 0;
const int PWM_INV_CHANNEL = 1;

void setup() {
  Serial.begin(115200);
  
  // PWMチャンネル0設定
  ledcSetup(PWM_CHANNEL, PWM_FREQ, PWM_RESOLUTION);
  ledcAttachPin(PWM_PIN, PWM_CHANNEL);
  ledcWrite(PWM_CHANNEL, 128);  // 50% duty
  
  // ±駆動の場合（簡易版: 同じPWMを両方に出力）
  // 完全な反転は追加のハード or ソフト対応が必要
  // まずは片側駆動（AIN2=GND）で試すことを推奨
  
  Serial.println("PWM Started: 20kHz, 50% duty");
}

void loop() {
  // 送信は常時ON（PoCでは）
  delay(1000);
  Serial.println("TX running...");
}
```

---

## 動作確認

### 確認前のチェック

- [ ] VMが5Vに接続されている
- [ ] VCCが3.3Vに接続されている
- [ ] GNDが接続されている
- [ ] MODEが3.3V（Hi）に接続されている

### 電源投入時の確認

| 確認項目 | 正常 | 異常時の対策 |
|---|---|---|
| DRV8835の発熱 | 常温〜微温 | 熱い場合は即電源OFF、配線確認 |
| XIAO ESP32C3の動作 | 正常起動（LED点灯） | リセット、電源確認 |

### オシロスコープがある場合

1. AOUT1-AOUT2間の波形を確認
2. 20kHzの矩形波（または共振で丸まった波形）が観測されればOK

### オシロがない場合

受信側で確認:
1. 送信コイル（3D11-722J X軸）と受信コイルを5cm程度に近づける
2. ADCの値がVmid（512）から大きく振れればOK

---

## 共振C探索の手順

3D11-722J (L ≈ 7.2mH) の場合:

| C値 | 共振周波数（理論） | A（実測） |
|-----|---|---|
| なし | - | __ |
| 8200pF | 20.6kHz | __ |
| 8200+560pF = 8760pF | 20.0kHz | __ |
| 8200+1500pF = 9700pF | 19.0kHz | __ |
| 6800pF | 22.9kHz | __ |

**Aが最大になったC値を採用**

---

## トラブルシューティング

| 症状 | 原因 | 対策 |
|---|---|---|
| DRV8835が熱くなる | 出力ショート、過電流 | 即電源OFF、配線確認 |
| 波形が出ない | PWMが出力されていない | GPIO確認、コード確認 |
| 受信側で信号が見えない | コイルが離れすぎ、共振ズレ | コイルを近づける、C値を変える |

---

## 回路図まとめ

```
                 5V
                  │
               [100µF]
                  │
                  ├──[0.1µF]── GND
                  │
          ┌───────┴───────┐
          │    DRV8835    │
          │    (109848)   │
          │               │
3.3V ────→│VCC       VM  │←── 5V
          │               │
3.3V ────→│MODE    AOUT1│──┬──[3D11-722J X軸]──┬── AOUT2
          │               │  │                   │
XIAO D0 ─→│AIN1    AOUT2│──│───────────────────┘
          │               │  │
GND ─────→│AIN2          │  └──[共振C 8760pF]───┘
          │               │
          │         GND  │←── GND
          └───────────────┘
```

---

## 次のステップ

✅ 送信回路の動作確認が完了したら、[05_integration.md](05_integration.md) へ進みます。

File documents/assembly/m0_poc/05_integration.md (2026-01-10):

# モジュール5: 全体結合と動作確認

## 概要

このモジュールでは:
1. 送信系と受信系を結合
2. 受信コイル（3D11-722J）を接続
3. I/Q処理で振幅Aを算出
4. 距離・角度応答を確認

---

## 3D11-722Jの送受信配置

3D11-722Jは3軸コイルなので、送信用と受信用に**2個**使用します。
**テストボード**を使用してブレッドボードに接続します。

```
【送信側】3D11-722J #1        【受信側】3D11-722J #2
┌─────────────┐              ┌─────────────┐
│  Test Board │   5cm以上    │  Test Board │
│  X軸 ← 使用 │  ←───────→  │  X軸 ← 使用 │
│  Y軸 (未使用)│              │  Y軸 (未使用)│
│  Z軸 (未使用)│              │  Z軸 (未使用)│
└─────────────┘              └─────────────┘
    DRV8835へ                    MCP6022へ
```

💡 **テストボードについて:**
- 3D11-722JはSMD部品のため、テストボードに実装してから使用します
- テストボードの組み立ては [README.md](README.md) を参照
- KiCad設計ファイル: [3D11_test_Board](../../../kicad/3D11_test_Board/)

---

## 全体接続図

```
┌────────────────────────────────────────────────────────────────────────┐
│                        XIAO ESP32C3                                    │
│  ┌──────────────────────────────────────────────────────────────────┐ │
│  │  D0 (GPIO2) ───────────────→ DRV8835 AIN1 (PWM)                  │ │
│  │  D1 (GPIO3) ───────────────→ DRV8835 AIN2 (GND固定 or 反転PWM)   │ │
│  │                                                                   │ │
│  │  D8 (GPIO8)  ──────────────→ MCP3008 CLK                         │ │
│  │  D9 (GPIO9)  ←────────────── MCP3008 DOUT                        │ │
│  │  D10 (GPIO10) ─────────────→ MCP3008 DIN                         │ │
│  │  D7 (GPIO20) ──────────────→ MCP3008 CS                          │ │
│  └──────────────────────────────────────────────────────────────────┘ │
│                                                                        │
│  3V3 ──────┬───────────────────────────────────────────────┐         │
│             │                                               │         │
│  5V ────────┼───────────────────────┐                       │         │
│             │                       │                       │         │
│  GND ───────┼───────────────────────┼───────────────────────┼─────    │
└─────────────┼───────────────────────┼───────────────────────┼─────────┘
              │                       │                       │
              ▼                       ▼                       ▼
┌─────────────────────┐   ┌─────────────────────┐   ┌─────────────────┐
│   Vmid生成          │   │   DRV8835           │   │   MCP6022       │
│   (10k/10k分圧)     │   │   (送信ドライバ)    │   │   (受信アンプ)  │
└─────────┬───────────┘   └─────────┬───────────┘   └────────┬────────┘
          │                         │                        │
          │                         ▼                        │
          │               ┌─────────────────┐                │
          │               │ 3D11-722J #1    │                │
          │               │ Test Board      │                │
          │               │ (送信: X軸)     │                │
          │               │ ＋ 共振C        │                │
          │               └─────────────────┘                │
          │                         │                        │
          │                     【磁界】                      │
          │                         │                        │
          │                         ▼                        │
          │               ┌─────────────────┐                │
          │               │ 3D11-722J #2    │────────────────┤
          │               │ Test Board      │                │
          │               │ (受信: X軸)     │                │
          │               └─────────────────┘                │
          │                                                  │
          └──────────────────────────────────────────────────┤
                                                             │
                                                             ▼
                                                   ┌─────────────────┐
                                                   │   MCP3008       │
                                                   │   (ADC)         │
                                                   └─────────────────┘
```

---

## 手順

### Step 1: 受信コイル（3D11-722J #2テストボード）の接続

受信側の3D11-722Jも**テストボード**を使用して接続します。

| テストボード端子 | 接続先 | 備考 |
|---|---|---|
| X+（上部または下部） | MCP6022 +IN B | 信号入力 |
| X-（上部または下部） | Vmid_out | コイルの基準電位 |

💡 **コイルの向き:** どちらの端子を+にしても動作しますが、極性が逆になると位相が180°変わります（振幅Aには影響なし）。

💡 **テストボードの確認:**
- テストボードが正しく組み立てられているか確認
- 各ピン間の導通をテスターで確認
- ショートがないことを確認

### Step 2: 配線の最終確認

以下のチェックリストを確認:

**電源系:**
- [ ] 3.3Vレールに3.3Vが出ている
- [ ] 5Vレールに5Vが出ている
- [ ] 全てのGNDが接続されている

**受信系:**
- [ ] Vmid_outが1.65V
- [ ] MCP6022の出力が1.65V付近（無信号時）
- [ ] MCP3008がSPIで応答する

**送信系:**
- [ ] DRV8835が過熱していない
- [ ] PWMが出力されている

### Step 3: コイルの配置

```
【テスト配置】

   3D11-722J #1            3D11-722J #2
   Test Board              Test Board
   (送信)                   (受信)
  ┌─────────┐             ┌─────────┐
  │  X軸面  │  ← 5cm →   │  X軸面  │
  │         │             │         │
  └─────────┘             └─────────┘
    
※ 同じ軸同士を向かい合わせる
※ 最初は5cm程度から始める
※ 両方ともテストボードに実装済み
```

---

## I/Q処理ファームウェア（XIAO ESP32C3用）

```cpp
#include <SPI.h>
#include <math.h>

// ===== XIAO ESP32C3 ピン設定 =====
#define SPI_SCK  8   // D8
#define SPI_MISO 9   // D9
#define SPI_MOSI 10  // D10
#define SPI_CS   20  // D7
#define PWM_PIN  2   // D0

// ===== 設定値 =====
const int SAMPLE_RATE = 80000;   // 80kHz目標
const int CARRIER_FREQ = 20000;  // 20kHz
const int WINDOW_MS = 2;         // 積分窓長 [ms]

// 計算値
const int SAMPLES_PER_WINDOW = SAMPLE_RATE * WINDOW_MS / 1000;
const float PHASE_INCREMENT = 2.0 * M_PI * CARRIER_FREQ / SAMPLE_RATE;

// ===== グローバル変数 =====
float phase = 0;

// ===== セットアップ =====
void setup() {
  Serial.begin(115200);
  while (!Serial) delay(10);
  
  // SPI初期化
  pinMode(SPI_CS, OUTPUT);
  digitalWrite(SPI_CS, HIGH);
  SPI.begin(SPI_SCK, SPI_MISO, SPI_MOSI, SPI_CS);
  
  // PWM初期化
  ledcSetup(0, 20000, 8);  // チャンネル0, 20kHz, 8bit
  ledcAttachPin(PWM_PIN, 0);
  ledcWrite(0, 128);  // 50% duty
  
  Serial.println("Loutrack EM M0 PoC");
  Serial.println("I,Q,A,phase");
}

// ===== ADC読み取り =====
int readADC(int channel) {
  byte command = 0b11000000 | (channel << 3);
  
  digitalWrite(SPI_CS, LOW);
  SPI.transfer(0x01);
  byte high = SPI.transfer(command);
  byte low = SPI.transfer(0x00);
  digitalWrite(SPI_CS, HIGH);
  
  return ((high & 0x03) << 8) | low;
}

// ===== I/Q処理 =====
void computeIQ(float &I, float &Q, float &A, float &phi) {
  I = 0;
  Q = 0;
  
  unsigned long startMicros = micros();
  
  for (int i = 0; i < SAMPLES_PER_WINDOW; i++) {
    // ADC読み取り（0-1023 → -512〜+511に正規化）
    int raw = readADC(0);
    float sample = (float)(raw - 512);
    
    // 参照波との乗算
    I += sample * cos(phase);
    Q += sample * sin(phase);
    
    // 位相を進める
    phase += PHASE_INCREMENT;
    if (phase > 2 * M_PI) phase -= 2 * M_PI;
  }
  
  unsigned long elapsed = micros() - startMicros;
  
  // 正規化
  I /= SAMPLES_PER_WINDOW;
  Q /= SAMPLES_PER_WINDOW;
  
  // 振幅・位相計算
  A = sqrt(I * I + Q * Q);
  phi = atan2(Q, I) * 180.0 / M_PI;  // 度に変換
}

// ===== メインループ =====
void loop() {
  float I, Q, A, phi;
  computeIQ(I, Q, A, phi);
  
  Serial.printf("%.2f,%.2f,%.2f,%.1f\n", I, Q, A, phi);
  
  // 60Hz更新のため約16.7ms間隔
  delay(16);
}
```

---

## 動作確認

### Step 4: 振幅Aの確認

1. **送信OFF時**（PWMを停止: `ledcWrite(0, 0);`）
   - Aはノイズフロア（小さい値、例: 1〜10）

2. **送信ON時**（PWMを開始: `ledcWrite(0, 128);`）
   - Aが明確に上昇（例: 50〜200以上）

3. **距離変化**
   - コイルを近づける → Aが増加
   - コイルを離す → Aが減少

### Step 5: 共振C最適化

| C値 | A（5cm時） | 備考 |
|-----|---|---|
| なし | __ | ベースライン |
| 8200pF | __ | |
| 8760pF (8200+560) | __ | 理論最適 |
| 9700pF (8200+1500) | __ | |
| 6800pF | __ | |

**最大のAを示すC値を採用**

### Step 6: 距離・角度スイープ

**距離スイープ:**

| 距離 | A | 備考 |
|---|---|---|
| 3cm | __ | |
| 5cm | __ | |
| 7cm | __ | |
| 10cm | __ | |
| 15cm | __ | |

**角度スイープ:**（コイル面の向きを変える）

| 角度 | A | 備考 |
|---|---|---|
| 0°（正対） | __ | |
| 45° | __ | |
| 90°（直交） | __ | |

---

## 成功判定

以下を満たせば**M0達成**:

| # | 条件 | 達成 |
|---|---|---|
| 1 | 送信ON時、Aが安定（標準偏差 < 平均の10%） | ☐ |
| 2 | 距離を変えるとAが単調変化 | ☐ |
| 3 | 送信ON/OFFでAに10倍以上の差 | ☐ |
| 4 | 1フレーム（16.7ms）内にI/Q算出完了 | ☐ |

---

## トラブルシューティング

### Aが安定しない（ノイズが大きい）

| 原因 | 対策 |
|---|---|
| 送信ノイズの回り込み | 送受を離す、GND一点接続を徹底 |
| 積分窓長が短い | WINDOW_MSを2→5msに増やす |
| サンプルレートが低い | SPIクロックを上げる |

### Aが常に小さい

| 原因 | 対策 |
|---|---|
| 共振Cが合っていない | 別のC値を試す |
| コイルの向きが悪い | 同じ軸を向かい合わせる |
| 距離が遠すぎる | 3cm程度まで近づける |
| アンプゲインが低い | Rfを増やす（22kΩでGain≈23） |

### Aが飽和（常に最大）

| 原因 | 対策 |
|---|---|
| 信号が強すぎ | コイルを離す |
| ADCが飽和 | ADC値が0か1023に張り付く → ゲインを下げる |

---

## 次のステップ

✅ M0達成おめでとうございます！

次のフェーズ:
- **M1**: 3軸TDM実装
  - 3D11-722JのY軸、Z軸を追加
  - DRV8835 #2を追加
  - TDMスロット制御実装

詳細は `documents/requirements/specification_v0.9.md` のセクション10を参照

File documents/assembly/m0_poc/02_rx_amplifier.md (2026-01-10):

# モジュール2: 受信アンプ（MCP6022）

## 概要

このモジュールでは:
1. MCP6022をブレッドボードに配置
2. 1ch目をVmidバッファとして構成
3. 2ch目を受信信号の増幅回路として構成

---

## MCP6022について

MCP6022は**2チャンネル入りのオペアンプ**です。

### ピン配置（DIP-8）

```
        ┌───∪───┐
 OUT A ─┤1    8├─ VDD (3.3V)
  -IN A ─┤2    7├─ OUT B
  +IN A ─┤3    6├─ -IN B
    VSS ─┤4    5├─ +IN B
        └───────┘

A = 1ch目（Vmidバッファに使用）
B = 2ch目（受信アンプに使用）
```

⚠️ **ICの向き確認:** ピン1の位置を示すマーク（くぼみ、点）を確認してから挿入！

---

## 必要な部品

| 部品 | 秋月コード | 数量 | 用途 |
|---|---|---|---|
| MCP6022-I/P | 116187 | 1 | オペアンプIC |
| 抵抗 10kΩ 0.1% | 116877 | 1 | Rf（フィードバック抵抗） |
| 抵抗 1kΩ 0.1% | 116876 | 1 | Rg（ゲイン設定抵抗） |
| コンデンサ 47pF | 108045 | 1 | 発振防止 |
| コンデンサ 0.1µF | 117059 | 1 | 電源デカップリング |

---

## 手順

### Step 1: MCP6022の配置

ブレッドボードの中央の溝をまたぐようにICを挿入します。

```
     列: 20 21 22 23 24
        ┌──┴──┴──┴──┴──┐
        │              │
   ● ● │●  ●  ●  ●  │ ● ●   ← 行A（ピン1-4側）
        │      溝      │
   ● ● │●  ●  ●  ●  │ ● ●   ← 行E/F（ピン5-8側）
        │              │
        └──────────────┘

ピン1(OUTA)は列20行A、ピン8(VDD)は列20行F、など
```

### Step 2: 電源接続

| ピン | 接続先 | 配線 |
|---|---|---|
| ピン8 (VDD) | 3.3Vレール | ジャンパワイヤ |
| ピン4 (VSS) | GNDレール | ジャンパワイヤ |

### Step 3: デカップリングコンデンサ

VDDとVSSの近く（ICのすぐ横）に0.1µFを追加:

1. ピン8と同じ列に0.1µFの片足
2. もう片足をGNDレールに

💡 **なぜICの近くに置く？** 遠いとノイズ除去効果が薄れます。

### Step 4: Vmidバッファ（1ch目）の配線

**電圧フォロワ回路:**

```
Vmid_raw ──[+IN A]
              │
           [MCP6022 A]
              │
[OUT A]───┬───[-IN A]
          │
          └── Vmid_out（バッファ後）
```

**配線:**

| 接続元 | 接続先 | 説明 |
|---|---|---|
| Vmid_raw（モジュール1で作った） | ピン3 (+IN A) | 入力 |
| ピン1 (OUT A) | ピン2 (-IN A) | フィードバック |
| ピン1 (OUT A) | Vmid_outとして使用 | 出力 |

**確認:** テスターでピン1（OUT A）とGND間を測定 → **約1.65V** になればOK

💡 **電圧フォロワとは？** 入力電圧と同じ電圧を、低インピーダンス（電流を取っても電圧が下がりにくい）で出力する回路です。

### Step 5: 受信アンプ（2ch目）の配線

**非反転増幅回路:**

```
              ┌────[47pF]────┐
              │              │
信号入力 ─[+IN B]            │
              │           [10kΩ Rf]
           [MCP6022 B]       │
              │              │
[-IN B]───┬───┴──────────────┴── OUT B ──→ ADC入力へ
          │
       [1kΩ Rg]
          │
        Vmid_out
```

**配線手順:**

1. **Rg（1kΩ）の接続:**
   - 片足: ピン6 (-IN B) と同じ列
   - もう片足: Vmid_out（ピン1）と同じ列

2. **Rf（10kΩ）の接続:**
   - 片足: ピン6 (-IN B) と同じ列
   - もう片足: ピン7 (OUT B) と同じ列

3. **47pF（発振防止）の接続:**
   - Rfと並列に接続（同じ2点を結ぶ）

4. **入力（+IN B）:**
   - ピン5 (+IN B) は後で受信コイルからの信号を接続
   - **今はVmid_outに接続しておく**（動作確認用）

**ゲインの計算:**
```
Gain = 1 + Rf/Rg = 1 + 10kΩ/1kΩ = 11倍
```

---

## 動作確認

### 入力をVmidに接続した状態での確認

電源を入れて、テスターで以下を確認:

| 測定点 | 期待値 | 許容範囲 | チェック |
|---|---|---|---|
| ピン1 (OUT A) - GND | 1.65V | 1.6〜1.7V | ☐ |
| ピン7 (OUT B) - GND | 1.65V | 1.6〜1.7V | ☐ |

💡 **なぜ両方1.65V？** 入力がVmid（1.65V）なので、増幅しても中心は1.65Vのままです。

### オシロスコープがある場合

1. ピン5 (+IN B) にテスト信号（例: 1kHz正弦波、100mVpp）を入力
2. ピン7 (OUT B) の波形を確認
3. 振幅が約11倍（1.1Vpp）になっていればOK

---

## トラブルシューティング

| 症状 | 原因 | 対策 |
|---|---|---|
| OUT Aが1.65Vにならない | Vmid_rawの問題 | モジュール1を再確認 |
| OUT Bが0Vまたは3.3Vに張り付く | 発振している | 47pFが正しく接続されているか確認 |
| OUT Bが1.65Vにならない | Rf/Rgの接続ミス | 抵抗の接続を再確認 |

---

## 回路図まとめ

```
                          MCP6022
                    ┌───────────────┐
Vmid_raw ──────────→│+IN A    VDD│←── 3.3V
                    │              │    │
                    │-IN A   OUT A│──┬─[0.1µF]── GND
                    │      ↑      │  │
                    │      └──────│──┘ (Vmid_out)
                    │              │
(将来:コイル信号)──→│+IN B   OUT B│───→ ADC入力へ
          ↓         │      ↑      │  │
       Vmid_out     │-IN B        │  │
          ↑         │  ↑ │       │  │
          │         │  │ [10kΩ]──│──┘
       [1kΩ]        │  │    │47pF│
          │         │  └────┴────│
        (Rg)        │            │
                    │  VSS       │
                    │   │        │
                    └───┼────────┘
                        │
                       GND
```

---

## 次のステップ

✅ アンプの動作確認が完了したら、[03_adc.md](03_adc.md) へ進みます。

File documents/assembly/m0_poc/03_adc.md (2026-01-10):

# モジュール3: ADC（MCP3008）

## 概要

このモジュールでは:
1. MCP3008をブレッドボードに配置
2. 電源とデカップリングを接続
3. XIAO ESP32C3とSPI接続
4. アンプ出力をADCに入力

---

## MCP3008について

MCP3008は**8チャンネル、10bit、SPIインターフェース**のADCです。

### ピン配置（DIP-16）

```
        ┌───∪───┐
   CH0 ─┤1   16├─ VDD (3.3V)
   CH1 ─┤2   15├─ VREF (3.3V)
   CH2 ─┤3   14├─ AGND
   CH3 ─┤4   13├─ CLK   ← SPI
   CH4 ─┤5   12├─ DOUT  ← SPI (MISO)
   CH5 ─┤6   11├─ DIN   ← SPI (MOSI)
   CH6 ─┤7   10├─ CS    ← SPI
   CH7 ─┤8    9├─ DGND
        └───────┘
```

⚠️ **ICの向き確認:** ピン1のマークを確認！

---

## 必要な部品

| 部品 | 秋月コード | 数量 | 用途 |
|---|---|---|---|
| MCP3008-I/P | 109485 | 1 | ADC IC |
| コンデンサ 0.1µF | 117059 | 2 | VDD, VREFデカップリング |
| BAT43 | 113907 | 2 | 入力保護（オプション） |

---

## 手順

### Step 1: MCP3008の配置

ブレッドボードの溝をまたぐようにICを挿入します。

```
     列: 30 31 32 33 34 35 36 37 38
        ┌──┴──┴──┴──┴──┴──┴──┴──┴──┐
        │                          │
   ● ● │●  ●  ●  ●  ●  ●  ●  ●  │ ● ●   ← 行A（ピン1-8側）
        │           溝             │
   ● ● │●  ●  ●  ●  ●  ●  ●  ●  │ ● ●   ← 行E/F（ピン9-16側）
        │                          │
        └──────────────────────────┘
```

### Step 2: 電源接続

| ピン | 接続先 | 備考 |
|---|---|---|
| ピン16 (VDD) | 3.3Vレール | デジタル電源 |
| ピン15 (VREF) | 3.3Vレール | 基準電圧 |
| ピン14 (AGND) | GNDレール | アナログGND |
| ピン9 (DGND) | GNDレール | デジタルGND |

### Step 3: デカップリングコンデンサ

**VDDデカップリング（ピン16近傍）:**
1. ピン16と同じ列に0.1µFの片足
2. もう片足をGNDレールに

**VREFデカップリング（ピン15近傍）:**
1. ピン15と同じ列に0.1µFの片足
2. もう片足をAGND（ピン14）と同じ列に

💡 **VREFのデカップリングは重要!** ADCの精度に直結します。

### Step 4: XIAO ESP32C3とのSPI接続

| MCP3008ピン | 信号名 | XIAO ピン | GPIO | 備考 |
|---|---|---|---|---|
| ピン13 (CLK) | SPI_SCK | D8 | GPIO8 | クロック |
| ピン12 (DOUT) | SPI_MISO | D9 | GPIO9 | データ出力 |
| ピン11 (DIN) | SPI_MOSI | D10 | GPIO10 | データ入力 |
| ピン10 (CS) | SPI_CS | D7 | GPIO20 | チップセレクト |

### Step 5: アナログ入力接続

| MCP3008ピン | 接続元 | 備考 |
|---|---|---|
| ピン1 (CH0) | MCP6022 OUT B | 受信アンプ出力 |
| ピン2-8 (CH1-7) | 未接続 | 将来3軸用 |

### Step 6: 入力保護（オプション）

BAT43ショットキーダイオードで過電圧からADCを保護:

```
        3.3V
          │
        [BAT43] (カソード→3.3V)
          │
CH0 ──────┼────── アンプ出力
          │
        [BAT43] (アノード→GND)
          │
         GND
```

**配線:**
1. BAT43 #1: アノード→CH0の列、カソード→3.3Vレール
2. BAT43 #2: カソード→CH0の列、アノード→GNDレール

💡 **ダイオードの向き:** BAT43には帯（バンド）があり、これがカソード側です。

---

## 動作確認

### XIAO ESP32C3用テストコード

Arduino IDEまたはPlatformIOで以下のコードを書き込み:

```cpp
// XIAO ESP32C3 + MCP3008 テスト
#include <SPI.h>

// XIAO ESP32C3 SPI pins
#define SPI_SCK  8   // D8
#define SPI_MISO 9   // D9
#define SPI_MOSI 10  // D10
#define SPI_CS   20  // D7

void setup() {
  Serial.begin(115200);
  while (!Serial) delay(10);
  
  pinMode(SPI_CS, OUTPUT);
  digitalWrite(SPI_CS, HIGH);
  
  SPI.begin(SPI_SCK, SPI_MISO, SPI_MOSI, SPI_CS);
  
  Serial.println("MCP3008 Test Started");
}

int readADC(int channel) {
  byte command = 0b11000000 | (channel << 3);
  
  digitalWrite(SPI_CS, LOW);
  SPI.transfer(0x01);  // Start bit
  byte high = SPI.transfer(command);
  byte low = SPI.transfer(0x00);
  digitalWrite(SPI_CS, HIGH);
  
  return ((high & 0x03) << 8) | low;
}

void loop() {
  int value = readADC(0);  // CH0を読む
  float voltage = value * 3.3 / 1023.0;
  
  Serial.printf("ADC: %4d, Voltage: %.3fV\n", value, voltage);
  delay(100);
}
```

### 期待される結果

| 入力状態 | ADC値 | 電圧 |
|---|---|---|
| アンプ出力 = Vmid (1.65V) | 約512 | 約1.65V |
| CH0をGNDに接続 | 0〜10 | 約0V |
| CH0を3.3Vに接続 | 1013〜1023 | 約3.3V |

---

## トラブルシューティング

| 症状 | 原因 | 対策 |
|---|---|---|
| 常に0が返る | SPI接続ミス、CSが常にHigh | 配線確認、CSがLowになっているか確認 |
| 値が不安定 | デカップリング不足、配線が長い | 0.1µFを確認、配線を短くする |
| 512付近にならない | Vmidの問題 | モジュール1, 2を再確認 |

---

## 回路図まとめ

```
                          MCP3008
                    ┌───────────────┐
アンプ出力 ────────→│CH0        VDD│←── 3.3V
                    │              │    │
        未使用 ─────│CH1       VREF│←───┼── 3.3V
        未使用 ─────│CH2           │    │
        未使用 ─────│CH3       AGND│──┬─│── GND
        未使用 ─────│CH4           │  │ │
        未使用 ─────│CH5        CLK│──│─│──→ XIAO D8
        未使用 ─────│CH6       DOUT│──│─│──→ XIAO D9
        未使用 ─────│CH7        DIN│←─│─│─── XIAO D10
                    │          CS │←─│─│─── XIAO D7
                    │        DGND │──│─│── GND
                    └───────────────┘  │ │
                                      │ │
                         [0.1µF]←─────┘ │
                            │           │
                           GND    [0.1µF]
                                    │
                                   GND
```

---

## 次のステップ

✅ ADCの動作確認が完了したら、[04_tx_driver.md](04_tx_driver.md) へ進みます。

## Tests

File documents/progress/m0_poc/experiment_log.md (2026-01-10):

# 実験ログ

## 記録フォーマット

各実験は以下の形式で記録してください。

---

## テンプレート

### 実験 #XXX: [タイトル]

**日時:** YYYY-MM-DD HH:MM  
**目的:** 

**条件:**
- 送信周波数: 
- 積分窓長: 
- コイル距離: 
- 共振C: 
- その他: 

**結果:**

| 測定項目 | 値 |
|---|-----|
| A（平均） | |
| A（標準偏差） | |
| サンプルレート | |

**観察・考察:**

**次のアクション:**

---

## 実験記録

（以下に実験結果を追記していく）

---

### 実験 #001: 受信アンプ動作確認

**日時:** 2026-01-11
**目的:** Vmidバッファと受信アンプの基本動作確認

**条件:**
- 電源電圧: 3.3V
- 入力接続: ピン5 (+IN B) を Vmid_out (ピン1) に接続
- 周囲温度: 室温
- 負荷: なし

**結果:**

| 測定項目 | 期待値 | 実測値 | ステータス |
|---|---|---|---|
| ピン1 (OUT A) - GND | 1.65V | 1.655V | ✅ |
| ピン7 (OUT B) - GND | 1.65V | 1.655V | ✅ |

**観察・考察:**
- Vmidバッファ（ピン1）は1.655Vを出力し、期待値1.65Vに近い値を示した
- 受信アンプ（ピン7）も1.655Vを出力し、入力（Vmid_out）が正しく増幅されている
- 両方の出力が一致していることから、アンプのオフセット電圧が適切に設定されている
- 測定値は許容範囲(1.6〜1.7V)内であり、回路動作は正常

**次のアクション:**
- MCP3008 ADC接続（03_adc.md）へ進む
- ADCでアンプ出力をデジタル変換できることを確認
- その後、送信回路（DRV8835）組み立てへ

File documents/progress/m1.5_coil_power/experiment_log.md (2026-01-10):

# M1.5 実験ログ

## 記録フォーマット

各実験は以下の形式で記録してください。

---

## テンプレート

### 実験 #XXX: [タイトル]

**日時:** YYYY-MM-DD HH:MM  
**目的:** 

**条件:**
- コイル仕様: 
- ドライバ: 
- 電源電圧: 
- 送信電流: 
- 距離: 

**結果:**

| 測定項目 | 値 |
|---|-----|
| インダクタンスL | |
| 共振C | |
| 振幅A（1m） | |
| 振幅A（2m） | |
| 振幅A（3m） | |
| 温度上昇 | |

**観察・考察:**

**次のアクション:**

---

## 実験記録

（以下に実験結果を追記していく）

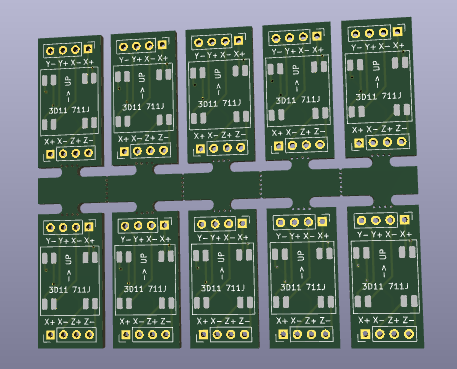
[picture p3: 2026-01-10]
kicad/3D11_production/3d11_testboard_batch.png

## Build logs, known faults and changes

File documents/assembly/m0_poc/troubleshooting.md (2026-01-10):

# M0 PoC トラブルシューティング

## よくある問題と対策

---

## 1. 電源系の問題

### 症状: XIAO ESP32C3が起動しない

| 原因 | 確認方法 | 対策 |
|---|---|---|
| USBケーブルの問題 | 別のケーブルで試す | データ転送対応ケーブルを使用 |
| ショート | テスタで3.3V-GND間を確認 | 配線を見直し、ショートを解消 |
| 過電流 | USB給電元を確認 | PCポートを変える、USBハブを避ける |

### 症状: 3.3Vが出ない

| 原因 | 確認方法 | 対策 |
|---|---|---|
| XIAO ESP32C3が動作していない | LEDを確認 | リセット、再書き込み |
| 過負荷 | 回路を切り離して測定 | 負荷を減らす |

### 症状: Vmidが1.65Vにならない

| 原因 | 確認方法 | 対策 |
|---|---|---|
| 抵抗値の間違い | テスターで抵抗を測定 | 正しい抵抗に交換 |
| 分圧抵抗の接続ミス | 回路を確認 | 3.3V→10k→Vmid→10k→GND を確認 |
| 負荷が重い | Vmidバッファを確認 | MCP6022のVmidバッファを先に構成 |

---

## 2. 受信アンプ（MCP6022）の問題

### 症状: 出力が0Vまたは3.3Vに張り付く

| 原因 | 確認方法 | 対策 |
|---|---|---|
| 発振している | オシロで波形確認 | 47pFを追加・増量 |
| 入力がオープン | 入力電圧を確認 | +INをVmidに接続 |
| ICの向きが逆 | ピン1の位置を確認 | ICを正しい向きに挿し直し |

### 症状: ゲインが想定と異なる

| 原因 | 確認方法 | 対策 |
|---|---|---|
| Rf/Rgの値が違う | テスターで確認 | 正しい抵抗値に交換 |
| RgがVmidに接続されていない | 配線確認 | RgをVmid_outに接続 |
| 帯域制限 | 周波数を下げてテスト | 47pFを減らす（発振注意） |

### 症状: ノイズが多い

| 原因 | 確認方法 | 対策 |
|---|---|---|
| デカップリング不足 | コンデンサの有無確認 | 0.1µFを追加 |
| 配線が長い | 配線を確認 | 配線を短くする |
| GNDループ | GND配線を確認 | 一点接続に変更 |

---

## 3. ADC（MCP3008）の問題

### 症状: 常に0が返る

| 原因 | 確認方法 | 対策 |
|---|---|---|
| SPI接続ミス | 配線確認 | CLK, MOSI, MISO, CSを確認 |
| CSがHighのまま | CSピンを確認 | コードでCSをLowにしているか確認 |
| 電源が入っていない | VDD電圧確認 | 3.3Vが来ているか確認 |

### 症状: 値が不安定

| 原因 | 確認方法 | 対策 |
|---|---|---|
| VREFデカップリング不足 | コンデンサ確認 | VREF-AGND間に0.1µF追加 |
| 入力インピーダンスが高い | 入力源を確認 | アンプ経由で入力 |
| SPIクロックが速すぎ | クロック設定確認 | クロックを下げる（1MHz以下から試す） |

### 症状: 値がVmid（512）付近にならない

| 原因 | 確認方法 | 対策 |
|---|---|---|
| アンプ出力がVmidでない | アンプ出力を測定 | モジュール2を再確認 |
| CH0以外を読んでいる | コードを確認 | チャンネル指定を確認 |

---

## 4. 送信（DRV8835）の問題

### 症状: DRV8835が熱くなる

⚠️ **即座に電源を切ってください！**

| 原因 | 確認方法 | 対策 |
|---|---|---|
| 出力がショート | AOUT1-AOUT2間を確認 | コイル接続を確認 |
| 過電流 | 電源供給能力を確認 | USB電源を確認、コイル巻数を増やす |
| MODEの設定ミス | MODE電圧を確認 | MODEを3.3V（Hi）に |

### 症状: 波形が出ない

| 原因 | 確認方法 | 対策 |
|---|---|---|
| PWMが出力されていない | GPIO電圧を確認 | XIAO ESP32C3のPWMコードを確認 |
| VMが来ていない | VM電圧を確認 | 5V供給を確認 |

### 症状: 受信側で信号が見えない

| 原因 | 確認方法 | 対策 |
|---|---|---|
| 共振がズレている | C値を変えてテスト | 共振C探索を実施 |
| コイルの向きが悪い | 配置を変えてテスト | 同じ軸を向かい合わせる |
| 距離が遠い | 近づけてテスト | 3cm程度まで近づける |
| アンプゲインが低い | アンプ出力を確認 | Rfを増やす |

---

## 5. I/Q処理の問題

### 症状: Aが常に0または小さい

| 原因 | 確認方法 | 対策 |
|---|---|---|
| ADC値が変化していない | 生のADC値をログ | 受信系を確認 |
| 参照周波数がズレている | CARRIER_FREQを確認 | 20000（Hz）に設定 |
| サンプルレートが低い | 実測サンプルレート確認 | SPIクロックを上げる |

### 症状: Aが不安定

| 原因 | 確認方法 | 対策 |
|---|---|---|
| 積分窓長が短い | WINDOW_MSを確認 | 2→5msに増やす |
| ノイズが大きい | 生波形を確認 | アナログ回路のノイズ対策 |
| 周波数ドリフト | 長時間観測 | NCO追従アルゴリズム追加 |

### 症状: Aが飽和（常に最大）

| 原因 | 確認方法 | 対策 |
|---|---|---|
| 信号が強すぎ | ADC生値を確認 | コイルを離す、ゲインを下げる |
| ADCが飽和 | ADC値が0か1023に張り付く | アンプゲインを下げる |

---

## 6. 部品の確認方法

### 抵抗のカラーコード

| 値 | カラーコード（4本帯） | カラーコード（5本帯・0.1%） |
|----|---|---|
| 1kΩ | 茶-黒-赤-金 | 茶-黒-黒-茶-茶 |
| 10kΩ | 茶-黒-橙-金 | 茶-黒-黒-赤-茶 |

### コンデンサの表記

| 表記 | 値 |
|---|-----|
| 104 | 0.1µF (100nF) |
| 103 | 0.01µF (10nF) |
| 822 | 8200pF |
| 682 | 6800pF |
| 152 | 1500pF |
| 561 | 560pF |
| 470 | 47pF |

### ダイオードの向き（BAT43）

```
バンド（帯）がある側がカソード（K）

   アノード(A)    カソード(K)
      │              │
   ───│◁─────────────│───
      │      帯      │
```

---

## 7. XIAO ESP32C3固有の注意点

### ピン配置の確認

```
        ┌─────────────────┐
        │   XIAO ESP32C3  │
        │                 │
   D0 ──┤ GPIO2    5V    ├── 5V出力
   D1 ──┤ GPIO3    GND   ├── GND
   D2 ──┤ GPIO4    3V3   ├── 3.3V出力
   D3 ──┤ GPIO5    GPIO10├── D10 (MOSI)
   D4 ──┤ GPIO6    GPIO9 ├── D9  (MISO)
   D5 ──┤ GPIO7    GPIO8 ├── D8  (SCK)
   D6 ──┤ GPIO21   GPIO20├── D7  (CS)
        └─────────────────┘

左側: D0-D6 (GPIO2,3,4,5,6,7,21)
右側: 5V, GND, 3V3, D10-D7 (GPIO10,9,8,20)
```

### SPI初期化の注意

ESP32C3では`SPI.begin()`の引数でピンを指定:

```cpp
SPI.begin(SPI_SCK, SPI_MISO, SPI_MOSI, SPI_CS);
// SPI.begin(8, 9, 10, 20); でも可
```

### GPIO2の注意

GPIO2はブート時にプルアップされている場合があります。
PWMに使用する場合は問題ありませんが、他の用途では注意。

---

## 8. 3D11-722Jコイルの注意点

### ピン配置の確認

コイルの実物のマーキングを確認してください。
一般的な3軸コイルのピン配置例:

```
┌─────────────────────┐
│  ●1  ●2  ●3  ●4   │  
│                     │
│      3D11-722J      │
│                     │
│  ●5  ●6  ●7  ●8   │
└─────────────────────┘

例: 
1-2: X軸
3-4: Y軸
5-6: Z軸
```

### インダクタンス確認

テスターのインダクタンスモードで測定:
- 期待値: 約7.2mH（各軸）
- 許容範囲: 6〜9mH

---

## 9. 測定のコツ

### テスターでの電圧測定

1. 黒リード（COM）をGNDに固定
2. 赤リードで測定点に触れる
3. 値が安定するまで待つ

### 導通チェック

1. テスターを導通モード（ブザーマーク）に
2. 両端に触れて「ピー」と鳴れば導通
3. 電源を切った状態で行う

### ショートチェック

1. 電源投入前に、3.3V-GND間、5V-GND間を測定
2. 数kΩ以上あればOK（数Ωはショートの可能性）

---

## 10. 助けを求める際の情報

問題が解決しない場合、以下の情報をまとめてください:

1. **症状:** 何が起きているか
2. **期待動作:** 何が起きるべきか
3. **測定値:** テスターで測った電圧など
4. **写真:** 配線の様子
5. **コード:** 使用しているファームウェア
6. **シリアル出力:** Serial.printの出力

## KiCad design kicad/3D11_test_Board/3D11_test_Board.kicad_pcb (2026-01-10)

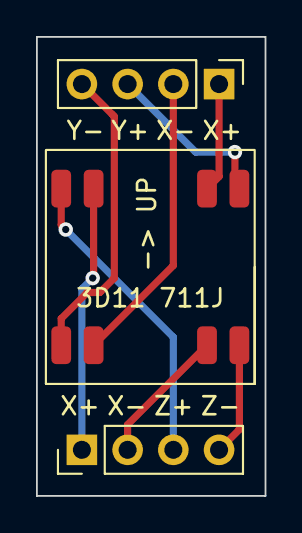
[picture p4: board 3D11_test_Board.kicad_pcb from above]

Board: 2 copper layers, 12.7 x 25.5 mm, 3 parts (0 on the bottom side), 8 nets.

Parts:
3D11 711J: ZSUCORE_3D11-722J
JXY: Conn_01x04_MountingPin; PinHeader_1x04_P2.54mm_Vertical
JXZ: Conn_01x04_MountingPin; PinHeader_1x04_P2.54mm_Vertical

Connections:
unnamed: 3D11 711J.2 (X+), JXY.1
unnamed: 3D11 711J.6 (X-), JXY.2
unnamed: 3D11 711J.1 (Y+), JXY.3
unnamed: 3D11 711J.5 (Y-), JXY.4
unnamed: 3D11 711J.3 (X+), JXZ.1
unnamed: 3D11 711J.7 (X-), JXZ.2
unnamed: 3D11 711J.4 (Z+), JXZ.3
unnamed: 3D11 711J.8 (Z-), JXZ.4

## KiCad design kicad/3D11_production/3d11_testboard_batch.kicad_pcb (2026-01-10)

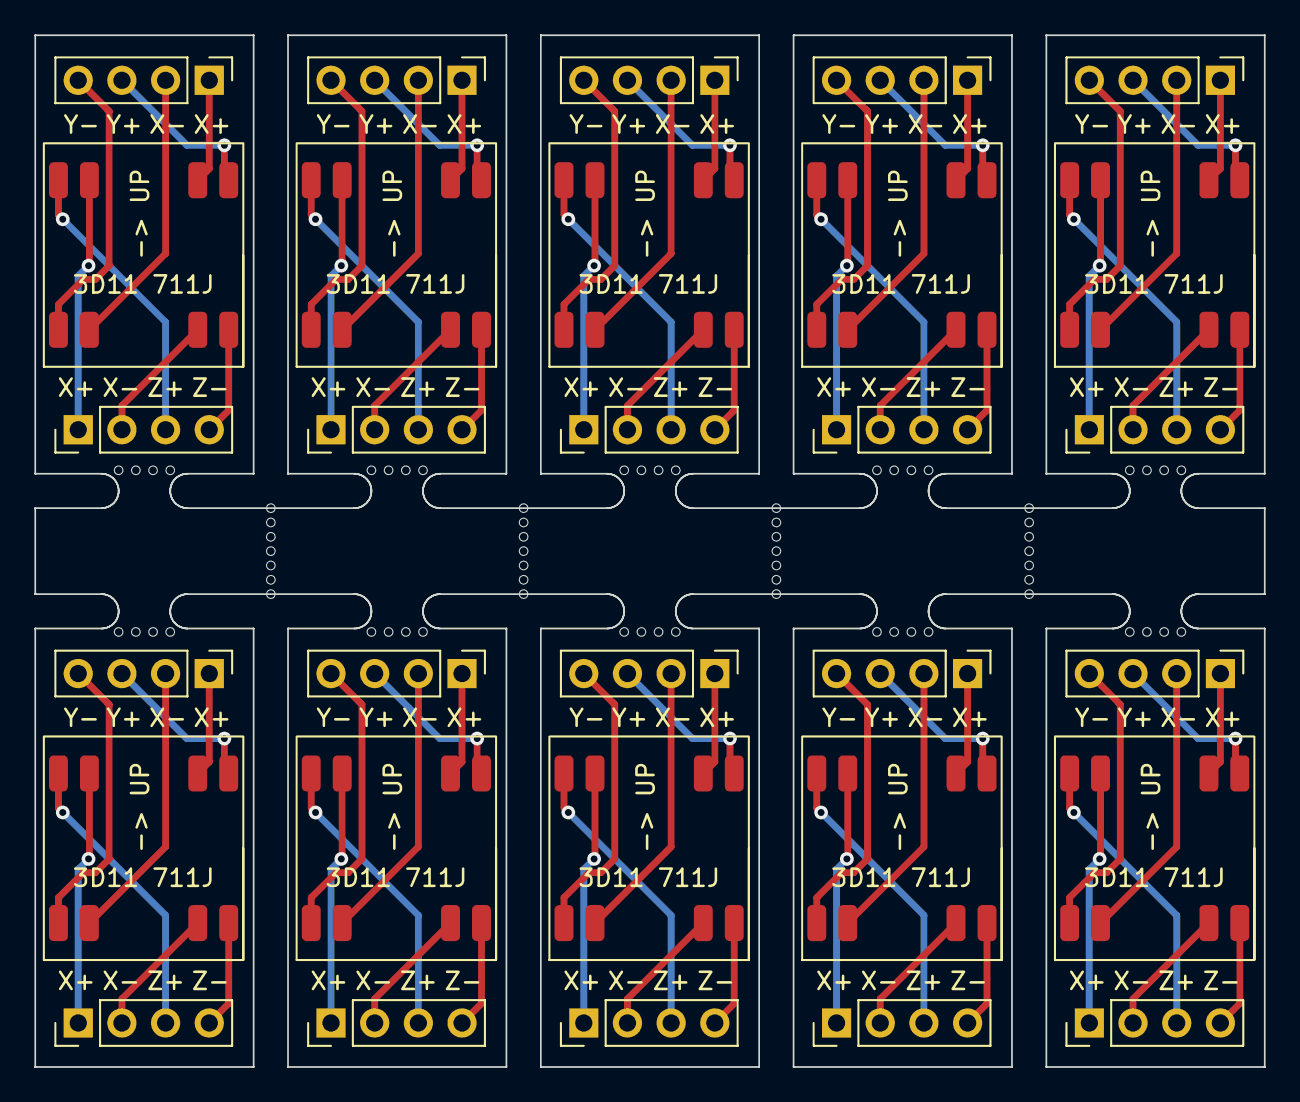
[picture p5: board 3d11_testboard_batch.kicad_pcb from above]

Board: 2 copper layers, 71.5 x 60.0 mm, 98 parts (0 on the bottom side), 80 nets.

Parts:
3D11 711J, 3D11 711J#2, 3D11 711J#3, 3D11 711J#4, 3D11 711J#5, 3D11 711J#6, 3D11 711J#7, 3D11 711J#8, 3D11 711J#9, 3D11 711J#10: ZSUCORE_3D11-722J
JXY: Conn_01x04_MountingPin; PinHeader_1x04_P2.54mm_Vertical
JXY#2, JXY#3, JXY#4, JXY#5, JXY#6, JXY#7, JXY#8, JXY#9, JXY#10: Conn_01x04_MountingPin; PinHeader_1x04_P2.54mm_Vertical
JXZ: Conn_01x04_MountingPin; PinHeader_1x04_P2.54mm_Vertical
JXZ#2, JXZ#3, JXZ#4, JXZ#5, JXZ#6, JXZ#7, JXZ#8, JXZ#9, JXZ#10: Conn_01x04_MountingPin; PinHeader_1x04_P2.54mm_Vertical
KiKit_MB_1_1, KiKit_MB_1_2, KiKit_MB_1_3, KiKit_MB_1_4, KiKit_MB_2_1, KiKit_MB_2_2, KiKit_MB_2_3, KiKit_MB_2_4, KiKit_MB_3_1, KiKit_MB_3_2, KiKit_MB_3_3, KiKit_MB_3_4, KiKit_MB_4_1, KiKit_MB_4_2, KiKit_MB_4_3, KiKit_MB_4_4, KiKit_MB_5_1, KiKit_MB_5_2, KiKit_MB_5_3, KiKit_MB_5_4, KiKit_MB_6_1, KiKit_MB_6_2, KiKit_MB_6_3, KiKit_MB_6_4, KiKit_MB_7_1, KiKit_MB_7_2, KiKit_MB_7_3, KiKit_MB_7_4, KiKit_MB_8_1, KiKit_MB_8_2, KiKit_MB_8_3, KiKit_MB_8_4, KiKit_MB_9_1, KiKit_MB_9_2, KiKit_MB_9_3, KiKit_MB_9_4, KiKit_MB_10_1, KiKit_MB_10_2, KiKit_MB_10_3, KiKit_MB_10_4, KiKit_MB_11_1, KiKit_MB_11_2, KiKit_MB_11_3, KiKit_MB_11_4, KiKit_MB_11_5, KiKit_MB_11_6, KiKit_MB_11_7, KiKit_MB_12_1, KiKit_MB_12_2, KiKit_MB_12_3, KiKit_MB_12_4, KiKit_MB_12_5, KiKit_MB_12_6, KiKit_MB_12_7, KiKit_MB_13_1, KiKit_MB_13_2, KiKit_MB_13_3, KiKit_MB_13_4, KiKit_MB_13_5, KiKit_MB_13_6, KiKit_MB_13_7, KiKit_MB_14_1, KiKit_MB_14_2, KiKit_MB_14_3, KiKit_MB_14_4, KiKit_MB_14_5, KiKit_MB_14_6, KiKit_MB_14_7: NPTH

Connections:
Board_0-Net-(JXY-Pad1): 3D11 711J#9.2 (X+), JXY.1
Board_0-Net-(JXY-Pad2): 3D11 711J#9.6 (X-), JXY.2
Board_0-Net-(JXY-Pad3): 3D11 711J#9.1 (Y+), JXY.3
Board_0-Net-(JXY-Pad4): 3D11 711J#9.5 (Y-), JXY.4
Board_0-Net-(JXZ-Pad1): 3D11 711J#9.3 (X+), JXZ#7.1
Board_0-Net-(JXZ-Pad2): 3D11 711J#9.7 (X-), JXZ#7.2
Board_0-Net-(JXZ-Pad3): 3D11 711J#9.4 (Z+), JXZ#7.3
Board_0-Net-(JXZ-Pad4): 3D11 711J#9.8 (Z-), JXZ#7.4
Board_1-Net-(JXY-Pad1): 3D11 711J#7.2 (X+), JXY#6.1
Board_1-Net-(JXY-Pad2): 3D11 711J#7.6 (X-), JXY#6.2
Board_1-Net-(JXY-Pad3): 3D11 711J#7.1 (Y+), JXY#6.3
Board_1-Net-(JXY-Pad4): 3D11 711J#7.5 (Y-), JXY#6.4
Board_1-Net-(JXZ-Pad1): 3D11 711J#7.3 (X+), JXZ#4.1
Board_1-Net-(JXZ-Pad2): 3D11 711J#7.7 (X-), JXZ#4.2
Board_1-Net-(JXZ-Pad3): 3D11 711J#7.4 (Z+), JXZ#4.3
Board_1-Net-(JXZ-Pad4): 3D11 711J#7.8 (Z-), JXZ#4.4
Board_2-Net-(JXY-Pad1): 3D11 711J.2 (X+), JXY#3.1
Board_2-Net-(JXY-Pad2): 3D11 711J.6 (X-), JXY#3.2
Board_2-Net-(JXY-Pad3): 3D11 711J.1 (Y+), JXY#3.3
Board_2-Net-(JXY-Pad4): 3D11 711J.5 (Y-), JXY#3.4
Board_2-Net-(JXZ-Pad1): 3D11 711J.3 (X+), JXZ#9.1
Board_2-Net-(JXZ-Pad2): 3D11 711J.7 (X-), JXZ#9.2
Board_2-Net-(JXZ-Pad3): 3D11 711J.4 (Z+), JXZ#9.3
Board_2-Net-(JXZ-Pad4): 3D11 711J.8 (Z-), JXZ#9.4
Board_3-Net-(JXY-Pad1): 3D11 711J#8.2 (X+), JXY#10.1
Board_3-Net-(JXY-Pad2): 3D11 711J#8.6 (X-), JXY#10.2
Board_3-Net-(JXY-Pad3): 3D11 711J#8.1 (Y+), JXY#10.3
Board_3-Net-(JXY-Pad4): 3D11 711J#8.5 (Y-), JXY#10.4
Board_3-Net-(JXZ-Pad1): 3D11 711J#8.3 (X+), JXZ#2.1
Board_3-Net-(JXZ-Pad2): 3D11 711J#8.7 (X-), JXZ#2.2
Board_3-Net-(JXZ-Pad3): 3D11 711J#8.4 (Z+), JXZ#2.3
Board_3-Net-(JXZ-Pad4): 3D11 711J#8.8 (Z-), JXZ#2.4
Board_4-Net-(JXY-Pad1): 3D11 711J#3.2 (X+), JXY#2.1
Board_4-Net-(JXY-Pad2): 3D11 711J#3.6 (X-), JXY#2.2
Board_4-Net-(JXY-Pad3): 3D11 711J#3.1 (Y+), JXY#2.3
Board_4-Net-(JXY-Pad4): 3D11 711J#3.5 (Y-), JXY#2.4
Board_4-Net-(JXZ-Pad1): 3D11 711J#3.3 (X+), JXZ#6.1
Board_4-Net-(JXZ-Pad2): 3D11 711J#3.7 (X-), JXZ#6.2
Board_4-Net-(JXZ-Pad3): 3D11 711J#3.4 (Z+), JXZ#6.3
Board_4-Net-(JXZ-Pad4): 3D11 711J#3.8 (Z-), JXZ#6.4
Board_5-Net-(JXY-Pad1): 3D11 711J#4.2 (X+), JXY#7.1
Board_5-Net-(JXY-Pad2): 3D11 711J#4.6 (X-), JXY#7.2
Board_5-Net-(JXY-Pad3): 3D11 711J#4.1 (Y+), JXY#7.3
Board_5-Net-(JXY-Pad4): 3D11 711J#4.5 (Y-), JXY#7.4
Board_5-Net-(JXZ-Pad1): 3D11 711J#4.3 (X+), JXZ#10.1
Board_5-Net-(JXZ-Pad2): 3D11 711J#4.7 (X-), JXZ#10.2
Board_5-Net-(JXZ-Pad3): 3D11 711J#4.4 (Z+), JXZ#10.3
Board_5-Net-(JXZ-Pad4): 3D11 711J#4.8 (Z-), JXZ#10.4
Board_6-Net-(JXY-Pad1): 3D11 711J#5.2 (X+), JXY#9.1
Board_6-Net-(JXY-Pad2): 3D11 711J#5.6 (X-), JXY#9.2
Board_6-Net-(JXY-Pad3): 3D11 711J#5.1 (Y+), JXY#9.3
Board_6-Net-(JXY-Pad4): 3D11 711J#5.5 (Y-), JXY#9.4
Board_6-Net-(JXZ-Pad1): 3D11 711J#5.3 (X+), JXZ.1
Board_6-Net-(JXZ-Pad2): 3D11 711J#5.7 (X-), JXZ.2
Board_6-Net-(JXZ-Pad3): 3D11 711J#5.4 (Z+), JXZ.3
Board_6-Net-(JXZ-Pad4): 3D11 711J#5.8 (Z-), JXZ.4
Board_7-Net-(JXY-Pad1): 3D11 711J#10.2 (X+), JXY#4.1
Board_7-Net-(JXY-Pad2): 3D11 711J#10.6 (X-), JXY#4.2
Board_7-Net-(JXY-Pad3): 3D11 711J#10.1 (Y+), JXY#4.3
Board_7-Net-(JXY-Pad4): 3D11 711J#10.5 (Y-), JXY#4.4
Board_7-Net-(JXZ-Pad1): 3D11 711J#10.3 (X+), JXZ#5.1
Board_7-Net-(JXZ-Pad2): 3D11 711J#10.7 (X-), JXZ#5.2
Board_7-Net-(JXZ-Pad3): 3D11 711J#10.4 (Z+), JXZ#5.3
Board_7-Net-(JXZ-Pad4): 3D11 711J#10.8 (Z-), JXZ#5.4
Board_8-Net-(JXY-Pad1): 3D11 711J#2.2 (X+), JXY#5.1
Board_8-Net-(JXY-Pad2): 3D11 711J#2.6 (X-), JXY#5.2
Board_8-Net-(JXY-Pad3): 3D11 711J#2.1 (Y+), JXY#5.3
Board_8-Net-(JXY-Pad4): 3D11 711J#2.5 (Y-), JXY#5.4
Board_8-Net-(JXZ-Pad1): 3D11 711J#2.3 (X+), JXZ#8.1
Board_8-Net-(JXZ-Pad2): 3D11 711J#2.7 (X-), JXZ#8.2
Board_8-Net-(JXZ-Pad3): 3D11 711J#2.4 (Z+), JXZ#8.3
Board_8-Net-(JXZ-Pad4): 3D11 711J#2.8 (Z-), JXZ#8.4
Board_9-Net-(JXY-Pad1): 3D11 711J#6.2 (X+), JXY#8.1
Board_9-Net-(JXY-Pad2): 3D11 711J#6.6 (X-), JXY#8.2
Board_9-Net-(JXY-Pad3): 3D11 711J#6.1 (Y+), JXY#8.3
Board_9-Net-(JXY-Pad4): 3D11 711J#6.5 (Y-), JXY#8.4
Board_9-Net-(JXZ-Pad1): 3D11 711J#6.3 (X+), JXZ#3.1
Board_9-Net-(JXZ-Pad2): 3D11 711J#6.7 (X-), JXZ#3.2
Board_9-Net-(JXZ-Pad3): 3D11 711J#6.4 (Z+), JXZ#3.3
Board_9-Net-(JXZ-Pad4): 3D11 711J#6.8 (Z-), JXZ#3.4

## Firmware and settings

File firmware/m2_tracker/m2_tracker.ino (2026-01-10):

/**
 * @file m2_tracker.ino
 * @brief M2 Tracker（受信機）メインスケッチ
 * 
 * バッテリー駆動対応の受信機ファームウェア。
 * - バッテリー電圧監視
 * - 過放電防止（自動DEEP SLEEP）
 * - Wake-upボタンによる復帰
 * 
 * @note GPIO割り当て:
 *   D0 (GPIO2): バッテリー電圧監視 (A0)
 *   D1 (GPIO3): Wake-upボタン
 *   D7-D10: SPI (MCP3008)
 */

#include "../lib/battery_monitor.h"
#include "../lib/power_manager.h"

// インスタンス生成
BatteryMonitor batteryMonitor;
PowerManager powerManager(batteryMonitor);

// バッテリー監視間隔（ms）
const unsigned long BATTERY_CHECK_INTERVAL = 1000;
unsigned long lastBatteryCheck = 0;

// ステータス表示間隔（ms）
const unsigned long STATUS_INTERVAL = 5000;
unsigned long lastStatus = 0;

void setup() {
  Serial.begin(115200);
  delay(1000);  // シリアルモニタを開く時間
  
  Serial.println();
  Serial.println("========================================");
  Serial.println("  M2 Tracker - Battery Powered Receiver");
  Serial.println("========================================");
  
  // バッテリーモニタ初期化
  batteryMonitor.begin();
  
  // 電源マネージャ初期化（過放電時はここでスリープに入る）
  powerManager.begin();
  
  // 起動情報を表示
  powerManager.printDebug();
  
  Serial.println();
  Serial.println("System ready.");
  Serial.println("----------------------------------------");
}

void loop() {
  unsigned long now = millis();
  
  // バッテリー監視（1秒間隔）
  if (now - lastBatteryCheck >= BATTERY_CHECK_INTERVAL) {
    lastBatteryCheck = now;
    powerManager.update();  // 過放電チェック＆警告処理
  }
  
  // ステータス表示（5秒間隔）
  if (now - lastStatus >= STATUS_INTERVAL) {
    lastStatus = now;
    batteryMonitor.printDebug();
  }
  
  // --- ここに受信処理を追加 ---
  // TODO: MCP3008からのADC読み取り
  // TODO: I/Q処理
  // TODO: データ送信
  
  delay(10);  // CPU負荷軽減
}

/**
 * @brief ボタン押下でDEEP SLEEPに入るテスト用関数
 * 
 * シリアルから 's' を送信するとDEEP SLEEPに入ります。
 * Wake-upボタン（D1）を押すと復帰します。
 */
void checkSerialCommand() {
  if (Serial.available()) {
    char cmd = Serial.read();
    if (cmd == 's' || cmd == 'S') {
      Serial.println("Manual sleep requested.");
      powerManager.enterDeepSleep();
    }
  }
}

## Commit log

2026-01-06 Initial commit: Loutrack EM project setup
    - Project documentation structure
    - M0 PoC specifications and assembly guides
    - BOM with XIAO ESP32C3, 3D11-722J, DRV8835, MCP6022, MCP3008
    - Datasheets (DRV8835, 3D11 coil, MCP3008)
    - Wiring tables and block diagrams
2026-01-06 Add M1.5 phase: Custom coil & driver enhancement
    - Add m1.5_coil_power folders across all document categories
    - Create M1.5 specification (coil design, driver selection, power supply)
    - Update milestone tracking with M1.5 tasks
    - Update project rules and READMEs with new phase
    - Target: 3m+ range with custom coil and high-power driver
2026-01-06 Update inventory: XIAO ESP32C3 x2, 3D11-722J x5
    - Update BOM with actual inventory counts
    - XIAO ESP32C3: 2 units (M0 uses 1, 1 spare for M1+)
    - 3D11-722J: 5 units (M0 uses 2, M1 uses 2, 1 spare)
    - M1 BOM updated: no additional coil purchase needed
2026-01-06 Update M1 BOM: add inventory remaining column
2026-01-06 Add links to Akizuki product codes in BOM tables
    - Add clickable links to all Akizuki product codes
    - Format: [code](https://akizukidenshi.com/catalog/g/g[code]/)
    - Updated m0_poc/bom.md and m1_3axis/bom.md
2026-01-10 docs: 3D11-722Jテストボードの情報を追加
    - KiCad設計ファイル（単体版・パネル版）を追加
    - README.mdにテストボードの説明と組み立て手順を追加
    - 04_tx_driver.mdと05_integration.mdにテストボード使用を明記
    - BOMにテストボード情報を追加
    [3D11_test_Board.kicad_pcb, 3D11_test_Board.kicad_sch, 3d11_testboard_batch.kicad_pcb]
2026-01-10 fix: 3D11-722JテストボードのKiCadファイルパスを修正
    - documents/assembly/m0_poc/から見た相対パスを../../kicad/から../../../kicad/に修正
    - README.md, 04_tx_driver.md, 05_integration.md, bom.mdを更新
2026-01-10 M2: バッテリー駆動仕様策定とファームウェア実装
    - M2仕様書にGPIO割り当てとバッテリー駆動仕様を追加
    - 電源回路図を作成（電圧監視、Wake-up回路）
    - バッテリー電圧監視ライブラリ実装
    - DEEP SLEEP/Wake-up機能実装
    - M0: 受信アンプ動作確認完了（実験ログ更新）
2026-01-10 README.md: M0/M2進捗更新とバッテリー駆動構成図追加
    - M0進捗: 電源＆受信アンプ完了、ADC接続中に更新
    - M2進捗: バッテリー駆動仕様策定完了に更新
    - M2システム構成図（バッテリー駆動対応）を追加
    - ロードマップの詳細化（M0タスク個別記載、M2バッテリー機能追加）
    - 技術資料にM2仕様書・電源回路図・実験ログを追加
    - フォルダ構成にfirmware/詳細構造を追加
2026-01-10 XIAO ESP32C3ピンアウト情報修正とデータシートREADME更新
    - wiring_table.md: XIAO ESP32C3ピン配置図の修正
    - D3-D6のGPIO/ピン割り当てを正しいものに更新
    - 左側/右側のピン配置説明を追加
    - 01_power_vmid.md: ピン配置図にSPI機能説明を追加
    - datasheets/README.md: ダウンロード済みファイル情報を更新
    - ESP32C3ピン図、MCP6022データシート、3D11コイルデータを反映
    - ESP32C3主要スペック情報を追加
2026-01-10 KiCadフォルダにREADME.mdを追加
    - 3D11_test_Boardと3D11_productionプロジェクトの説明
    - テストボードの目的とピン配置図
    - 設計仕様、製造手順、使用方法
    - KiCadプロジェクトの編集方法
    - 関連ドキュメントへのリンク
2026-01-12 .gitignore: documents/outside_sources/を追加
    - 外部ソースフォルダをGit管理から除外
    - 著作権/ライセンス関連の懸念があるファイルを管理対象外に
2026-01-12 Add LIS3DH integration for hemispheric ambiguity resolution
    - Update M1 milestone tracking with LIS3DH tasks (1.7-1.9)
    - Add LIS3DH to M1 BOM and create M2 SMD BOM
    - Create LIS3DH integration specification for M1
    - Update M0 spec with hemispheric ambiguity solution
    - Add M2 SMD LIS3DH schematic and BOM
    - Update README files across documentation structure
